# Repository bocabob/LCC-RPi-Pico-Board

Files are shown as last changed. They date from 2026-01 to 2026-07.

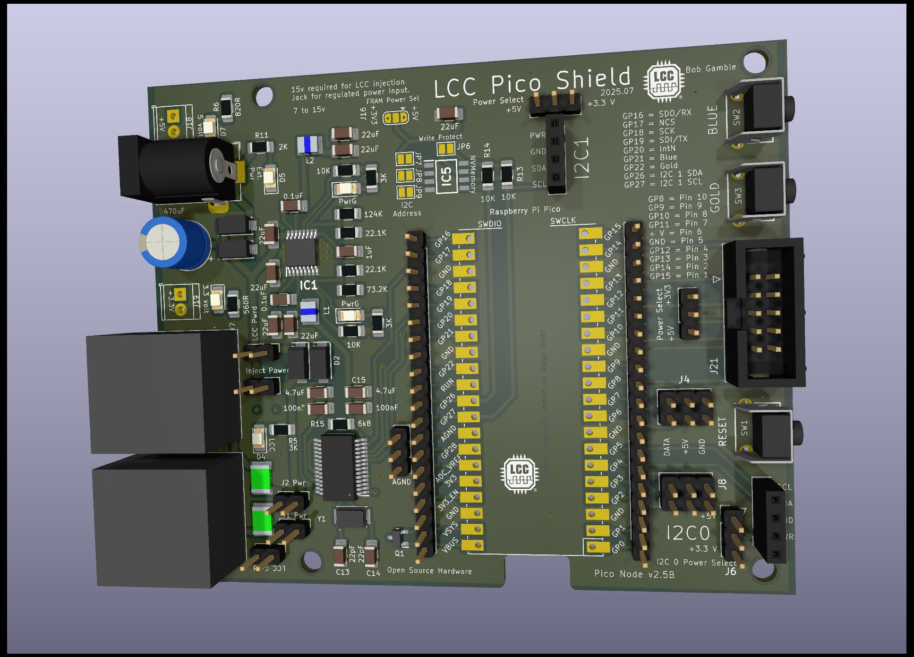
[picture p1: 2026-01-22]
LCC-Pico-Node_v2_6.jpg

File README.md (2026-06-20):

# Raspberry Pi Pico for LCC

KiCad OpenLCB / LCC Raspberry Pi Pico motherboard for model railroad control.

Documentation, source, and gerbers for the board may be found in this repository:
<https://github.com/bocabob/LCC-RPi-Pico-Board>

## Overview

This board provides a flexible Raspberry Pi Pico (or Pico 2) platform for OpenLCB/LCC nodes. It includes:

- 3.3V and 5V switching power regulation
- Provision for onboard or plug-attached EEPROM or FRAM NVM modules
- Configurable to be powered from LCC, powered independently, or to inject power onto the LCC bus
- Tested with the OpenLCB Single Thread and OpenLcbCLib libraries

## Evolution

The LCC Pico development boards evolved from LocoNet designs dating back to 2021. The early turntable boards used Arduino Nanos and depended on turnout commands for indexing to hard-coded stepper positions. Fascia panel input was desired, so a keypad version was developed. This proved cumbersome, so a small touch screen was added with a Mega processor. The screen size needed to grow to nine inches for usability, so the Raspberry Pi Pico was selected. The Pico represents the "Goldilocks" processor of very good function, technical stability, and the easy-to-use Arduino IDE. Moving to the Pico enabled the LCC migration in 2024, when the Single Thread library began to support the RP2040 processor family. With OpenLcbCLib, full protocol support was enabled.

Earlier revisions also included a dedicated **Stepper** board with its own stepper motor driver circuitry built in. As of v3.0, that circuitry has moved to a separate breakout board that plugs into the standard Node board, so there is no longer a need for a Stepper-specific board design — one Node board now serves every node type.

## Family

There is a single board design: the **Node**. It exposes 16 GP pins through two 10P IDC connectors, plus an additional 5-pin analog header (I/O-3), for general-purpose I/O. Specialized functions — stepper motor control, displays, servos, etc. — are added via plug-in breakout boards rather than dedicated board variants.

While the board works with either the Pico or the Pico 2, the Pico 2 is recommended for its enhanced capabilities.

## Common Features

### Power

The board provides dual switching outputs of 3.3V and 5V, with input either from the LCC CAN bus or an external 8–15V source. It may be configured to inject power onto the CAN bus, or to isolate power on either or both of the CAN bus jacks. Auxiliary 3.3V and 5V outputs are available on the board.

### CAN Bus Control

Uses the discrete MCP2518 and MCP2562 CAN controller/transceiver hardware (easier to hand-solder than the integrated MCP251863 used on some earlier boards).

### Non-Volatile Memory (NVM)

I2C non-volatile memory should be used to reduce wear on the Pico flash. External NVM may be attached via the I2C header, the FRAM Breakout header, or soldered down to the IC5 footprint. When using the latter two, the I2C address jumpers may be used to select non-default addresses or implement write protection. Otherwise, those functions are handled by the module plugged into the I2C header.

Typical parts include modules using an AT25C256 chip or RC256V FRAM. Parts compatible with the following pinouts should work for soldering directly to the footprint:

- BR24G512F-3AGTE2 I2C BUS (2-Wire) 512K, or other sizes with equivalent pinouts
- MB85RC256VPF-G-BCERE1 256kbit FRAM with I2C

### I2C

I2C is used to address NVM. One or both of the available I2C channels on the Pico are exposed via headers for external devices. Care should be taken when attaching peripherals to the same channel as the NVM, to avoid interference. Some I2C devices require 5V, so a jumper selects between the two available voltages.

### Buttons

Since the Pico has no reset button, one is provided on the board. There is also a header so a remote reset button may be wired in. Provision is included for blue and gold buttons; on v3.0 these share pins with the I/O-2 and I/O-3 connectors (see pin table below), so they are unavailable when a breakout uses those specific pins.

### IDC Connections

GP pins and other connections are available on 10P IDC connectors (I/O-1, I/O-2), plus a 5-pin analog header (I/O-3). Pinouts are printed on the silkscreen and in the board user guide. On each 10P connector, pin 5 is Ground and pin 6 is a jumper-selectable voltage rail (3.3V or 5V) for the attached breakout.

## Board Variants

### LCC-Pico-Node v3.0

- MCP2518 and MCP2562 chips for CAN bus implementation of OpenLCB/LCC protocols
- Two 10-pin IDC connectors (I/O-1, I/O-2) exposing 16 GP pins for general-purpose I/O
- One 5-pin analog header (I/O-3) for additional GP/analog connections
- Two I2C ports
- Stepper, display, servo, or other specialized functions are added via plug-in breakout boards rather than being built into the Node board itself

### IDC Breakout Boards

- **Display 101 Adapter** — attaches to a BuyDisplay ER-TFTM101 10.1" touchscreen for SPI display control and I2C touch. Includes provision for alternate assignments of line 10 and a reset button.
- **Stepper Breakout** *(planned — design files not yet in this repository)* — carries a stepper motor driver and provides connections to the stepper motor, sensors, NeoPixel bus, and an I2C connection. Has a separate power connection for the external stepper motor supply (12–15V) and for the +5V used for Hall sensors and the NeoPixel bus; the IDC connector voltage should be set to 3.3V on the Node side when this breakout is attached.
- **Ribbon Breakout** — IDC breakout with optional LEDs for testing.
- **Servo Breakout** — IDC breakout with power and ground pins around each GPIO pin to facilitate connections to inputs, servos, NeoPixels, or other devices.

## Board Pin Assignments

| Pin | GP | Alt 1 | Alt 2 | v3.0 Node |
|-----|---|---|---|---|
| 1 | gp0 | SPI0 RX | I2C0 SDA | ACAN_RX_PIN |
| 2 | gp1 | SPI0 CSN  | I2C0 SCL | ACAN_CS_PIN |
| 3 | GND | | | |
| 4 | gp2 | SPI0 SCK  | I2C1 SDA | ACAN_CSK_PIN |
| 5 | gp3 | SPI0 TX | I2C1 SCL | ACAN_TX_PIN |
| 6 | gp4 | SPI0 RX | I2C0 SDA | ACAN_INT_PIN |
| 7 | gp5 | SPI0 CSn  | I2C0 SCL | I/O-2: Pin 10 & Blue Button |
| 8 | GND | | | |
| 9 | gp6 | SPI0 SCK  | I2C1 SDA | I2C1 SDA |
| 10  | gp7 | SPI0 TX | I2C1 SCL | I2C1 SCL |
| 11  | gp8 | SPI1 RX | I2C0 SDA | I/O-1: Pin 1 |
| 12  | gp9 | SPI1 CSn  | I2C0 SCL | I/O-1: Pin 2 |
| 13  | GND | | | |
| 14  | gp10 | SPI1 SCK  | I2C1 SDA | I/O-1: Pin 3 |
| 15  | gp11 | SPI1 TX | I2C1 SCL | I/O-1: Pin 4 |
| 16  | gp12 | SPI1 RX | I2C0 SDA | I/O-1: Pin 7 |
| 17  | gp13 | SPI1 CSn  | I2C0 SCL | I/O-1: Pin 8 |
| 18  | GND | | | |
| 19  | gp14 | SPI1 SCK  | I2C1 SDA | I/O-1: Pin 9 |
| 20  | gp15 | SPI1 TX | I2C1 SCL | I/O-1: Pin 10 |
| 21  | gp16 | SPI0 RX | I2C0 SDA | I/O-2: Pin 1 |
| 22  | gp17 | SPI0 CSn  | I2C0 SCL | I/O-2: Pin 2 |
| 23  | GND | | | |
| 24  | gp18 | SPI0 SCK  | I2C1 SDA | I/O-2: Pin 3 |
| 25  | gp19 | SPI0 TX | I2C1 SCL | I/O-2: Pin 4 |
| 26  | gp20 | | I2C0 SDA | I/O-2: Pin 7 |
| 27  | gp21 | | I2C0 SCL | I/O-2: Pin 8 |
| 28  | GND | | | |
| 29  | gp22 | | | I/O-2: Pin 9 |
| 30  | RUN | | | Reset Button / header |
| 31  | gp26 | ADC0 | I2C1 SDA | I/O-3: Pin 1 |
| 32  | gp27 | ADC1 | I2C1 SCL | I/O-3: Pin 2 |
| 33  | GND | A GND | | I/O-3: Pin 3 (AGND) |
| 34  | gp28 | ADC2 | | I/O-3: Pin 5 & Gold Button |
| 35  | | ADC_VREF  | | I/O-3: Pin 4 (VREF) |
| 36  | 3v3_OUT  | | | |
| 37  | 3V3_EN | | | |
| 38  | GND | | | |
| 39  | VSYS | | | |
| 40  | VBUS | | | |
| | GND | | | I/O-1: Pin 5 |
| | Vselect1 | | | I/O-1: Pin 6 |
| | GND | | | I/O-2: Pin 5 |
| | Vselect2 | | | I/O-2: Pin 6 |

Note: I/O-2 Pin 10 (gp5) and I/O-3 Pin 5 (gp28) double as the Blue and Gold buttons. A breakout that uses either of those pins makes the corresponding button unavailable.

## Software

### Example Node Applications

- <https://github.com/bocabob/LCC_RPiPico_Turntable>
- <https://github.com/bocabob/LCC_RPiPico_Roundhouse>
- <https://github.com/bocabob/LCC_RPiPico_PixelLights>
- <https://github.com/bocabob/LCC_RPiPico_Clock_Lights>

### Architectural Standard

Cross-project firmware conventions (board versioning, breakout pin assignments, configuration memory, naming) for all node applications above are documented in:
<https://github.com/bocabob/LCC_RPiPico_Common>

### Board Support

Use the RP2040 board library by Earle Philhower:
<https://arduino-pico.readthedocs.io/en/latest/install.html>

### LCC Support

- <https://github.com/openlcb/OpenLCB_Single_Thread>
- <https://github.com/JimKueneman/OpenLcbCLib>

### CAN Hardware

- ACAN2517 Arduino library

### External Storage

- I2C_EEPROM Arduino library by Rob Tillaart
- FRAM_I2C Arduino library by Rob Tillaart

### NeoPixel

- NeoPixelBus by Makuna (preferred)
- NeoPixelConnect by Alan Yorinks

### Other Preferred Libraries

#### Display

- `TFT_eSPI_RA8876.h` — display library (modified): <https://github.com/bocabob/TFT_eSPI_RA8876>
- `RA8876_RP2040.h` — display library (modified): <https://github.com/bocabob/RA8876_RP2040>
- `my_bb_captouch.h` — capacitive touch driver (modified): <https://github.com/bocabob/my_bb_captouch>

#### Servos

- `ServoEasing.hpp` — for slow servo action, including bounces
- `PCA9685_servo_driver.h`
- `PCA9685_servo.h`

#### Stepper Motor

- `AccelStepper.h` by Mike McCauley (modified)

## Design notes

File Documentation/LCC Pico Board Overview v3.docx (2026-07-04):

# LCC Pico Board Overview

Documentation, source and gerbers for boards may be found at: https://github.com/bocabob/LCC-RPi-Pico-Board

## Overview

This board provides a flexible Raspberry Pi Pico (or Pico 2) platform for OpenLCB/LCC nodes. It includes:

- 3.3V and 5V switching power regulation
- Provision for onboard or plug-attached EEPROM or FRAM NVM modules
- Configurable to be powered from LCC, powered independently, or to inject power onto the LCC bus
- Tested with the OpenLCB Single Thread and OpenLcbCLib libraries

## Evolution

The LCC Pico development boards evolved from LocoNet designs dating back to 2021. The early turntable boards used Arduino Nanos and depended on turnout commands for indexing to hard-coded stepper positions. Fascia panel input was desired, so a keypad version was developed. This proved cumbersome, so a small touch screen was added with a Mega processor. The screen size needed to grow to nine inches for usability, so the Raspberry Pi Pico was selected. The Pico represents the "Goldilocks" processor of very good function, technical stability, and the easy-to-use Arduino IDE. Moving to the Pico enabled the LCC migration in 2024, when the Single Thread library began to support the RP2040 processor family. With OpenLcbCLib, full protocol support was enabled.

Earlier revisions also included a dedicated Stepper board with its own stepper motor driver circuitry built in. As of v3.0, that circuitry has moved to a separate breakout board that plugs into the standard Node board, so there is no longer a need for a Stepper-specific board design — one Node board now serves every node type.

## Families

There is a single board architecture: the Node. It exposes 16 GP pins through two 10P IDC connectors, plus an additional 6-pin analog header (I/O-3), for general-purpose I/O. Specialized functions — stepper motor control, displays, servos, etc. — are added via plug-in breakout boards rather than dedicated board variants.

## A variant of the Node is the Lite Node which is slightly smaller and lacks external power inputs and the 3.3-volt power circuitry. 3.3-volt power is supplied by the RPi Pico and is thus limited by that specification and should not exceed about 250mA.

## While the boards work with either the Pico or the Pico 2, the Pico 2 is recommended for its enhanced capabilities.

## Common Features

#### Power

The full board provides dual switching power output of 3.3V and 5V with input either from the LCC CAN bus or an external power source between 8 and 15 volts. The boards may be configured to inject power to the CAN bus or to isolate power for either or both of the CAN bus jacks. Auxiliary power outputs for both 3.3V and 5V are available on the board.

#### CAN Bus Control

#### Uses the discrete MCP2518 and MCP2562 CAN controller/transceiver hardware (easier to hand-solder than the integrated MCP251863 used on some earlier boards).

#### Non-Volatile Memory (NVM)

I2C nonvolatile memory is used to reduce strain on the Pico flash. External NVM is soldered down to the IC5 footprint. The I2C Address jumpers may be used to select non-default addresses or implement write protection. Otherwise, these would be functions of the module plugged into the I2C header.

Parts compatible with the following should work for soldering to the footprint on the board.

- BR24G256F-3AGTE2 I2C BUS(2-Wre) 256K or other sizes with equivalent pinouts
- MB85RC256VPF-G-BCERE1 256kbit FRAM with I2C

#### I2C

One of the two available I2C channels is dedicated to address NVM. The other available I2C channel on the Pico may be configured from appropriate pins on the IDC connections. Care should be taken should you attach peripherals to the same channel as the NVM lest there be interference. Some I2C devices will require 5 volts and so there is selection via jumper between the two available voltages but 3.3-volts is preferred as this matches the Pico voltage.

#### Buttons

As there is no reset button on the Pico, one is provided on the board. There is also a header so that a button may be wired in for remote reset. Provision is included for blue and gold buttons; on v3.0 these share pins with the I/O-2 and I/O-3 connectors (see pin table below), so they are unavailable when a breakout uses those specific pins.

#### IDC Connections

GP pins and other connections are available on 10P IDC connectors (I/O-1, I/O-2), plus a 5-pin analog header (I/O-3). Pinouts are printed on the silkscreen and in the board user guide. On each 10P connector, pin 5 is Ground and pin 6 is a jumper-selectable voltage rail (3.3V or 5V) for the attached breakout.

# Board Variants

There are versions with 1206 size components for hand assembly and versions with 0805 sized components for economic production by JLCPCB. All files for assembly input are provided.

## LCC-Pico-Node v3.0

- MCP2518 and MCP2562 chips for CAN bus implementation of OpenLCB/LCC protocols
- Two 10-pin IDC connectors (I/O-1, I/O-2) exposing 16 GP pins for general-purpose I/O
- One 6-pin IDC analog header (I/O-3) for additional GP/analog connections
- External power connections for input and/or output to peripheral devices. 5- and 3.3-volt regulation is on board and available from supplied input. Current should not exceed 1 A from each regulated source. External input power is passed through to associated headers.
- Stepper, display, servo, or other specialized functions are added via plug-in breakout boards rather than being built into the Node board itself

## LCC-Pico-Node-Lite v3.0

- MCP2518 and MCP2562 chips for CAN bus implementation of OpenLCB/LCC protocols
- Two 10-pin IDC connectors (I/O-1, I/O-2) exposing 16 GP pins for general-purpose I/O
- One 6-pin IDC analog header (I/O-3) for additional GP/analog connections
- LCC bus powered, 5 volt regulated supply, 3.3 volt from Pico (limited capacity)
- Display, servo, or other specialized functions are added via plug-in breakout boards rather than being built into the Node board itself. Current demand should not exceed LCC specifications.

### Board Pin Assignments

Pin | GP | Alt 1 | Alt 2 | v3.0 Node
1 | gp0 | SPI0 RX | I2C0 SDA | ACAN_RX_PIN
2 | gp1 | SPI0 CSN | I2C0 SCL | ACAN_CS_PIN
3 | GND
4 | gp2 | SPI0 SCK | I2C1 SDA | ACAN_CSK_PIN
5 | gp3 | SPI0 TX | I2C1 SCL | ACAN_TX_PIN
6 | gp4 | SPI0 RX | I2C0 SDA | ACAN_INT_PIN
7 | gp5 | SPI0 CSn | I2C0 SCL | I/O-2: Pin 10 & Blue Button
8 | GND
9 | gp6 | SPI0 SCK | I2C1 SDA | I2C1 SDA
10 | gp7 | SPI0 TX | I2C1 SCL | I2C1 SCL
11 | gp8 | SPI1 RX | I2C0 SDA | I/O-1: Pin 1
12 | gp9 | SPI1 CSn | I2C0 SCL | I/O-1: Pin 2
13 | GND
14 | gp10 | SPI1 SCK | I2C1 SDA | I/O-1: Pin 3
15 | gp11 | SPI1 TX | I2C1 SCL | I/O-1: Pin 4
16 | gp12 | SPI1 RX | I2C0 SDA | I/O-1: Pin 7
17 | gp13 | SPI1 CSn | I2C0 SCL | I/O-1: Pin 8
18 | GND
19 | gp14 | SPI1 SCK | I2C1 SDA | I/O-1: Pin 9
20 | gp15 | SPI1 TX | I2C1 SCL | I/O-1: Pin 10
21 | gp16 | SPI0 RX | I2C0 SDA | I/O-2: Pin 1
22 | gp17 | SPI0 CSn | I2C0 SCL | I/O-2: Pin 2
23 | GND
24 | gp18 | SPI0 SCK | I2C1 SDA | I/O-2: Pin 3
25 | gp19 | SPI0 TX | I2C1 SCL | I/O-2: Pin 4
26 | gp20 | | I2C0 SDA | I/O-2: Pin 7
27 | gp21 | | I2C0 SCL | I/O-2: Pin 8
28 | GND
29 | gp22 | | | I/O-2: Pin 9
30 | RUN | | | Reset Button / header
31 | gp26 | ADC0 | I2C1 SDA | I/O-3: Pin 1
32 | gp27 | ADC1 | I2C1 SCL | I/O-3: Pin 2
33 | GND | A GND | | I/O-3: Pin 3 (AGND)
34 | gp28 | ADC2 | | I/O-3: Pin 5 & Gold Button
35 | | ADC_VREF | | I/O-3: Pin 4 (VREF)
36 | 3v3_OUT
37 | 3V3_EN
38 | GND
39 | VSYS
40 | VBUS
| GND | | | I/O-1: Pin 5
| Vselect1 | | | I/O-1: Pin 6
| GND | | | I/O-2: Pin 5
| Vselect2 | | | I/O-2: Pin 6

Note: I/O-2 Pin 10 (gp5) and I/O-3 Pin 5 (gp28) double as the Blue and Gold buttons. A breakout that uses either of those pins makes the corresponding button unavailable.

### Node 3.0C

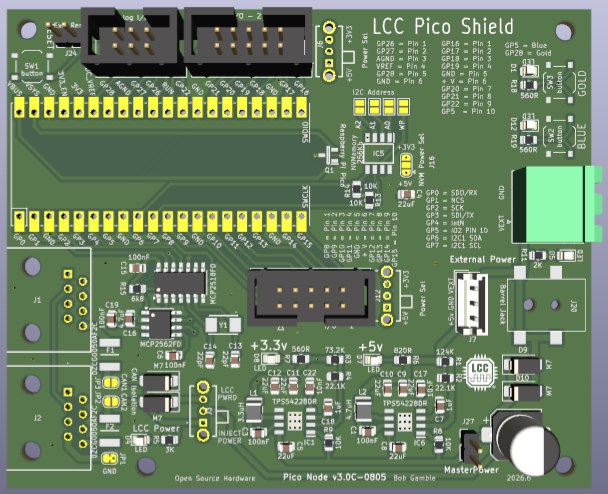
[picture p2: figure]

The power circuit uses two separate switching chips which are identical in function and rated for about 1 amp each.

There is a switch to toggle between injecting power to LCC or to be powered from LCC. Each 10 pin IDC connector is associated with a switch to select the voltage (3.3 or 5) passed on the power pin (6) of the connection. There is a solder jumper to select the voltage used for the NVM chip should there be a specific need.

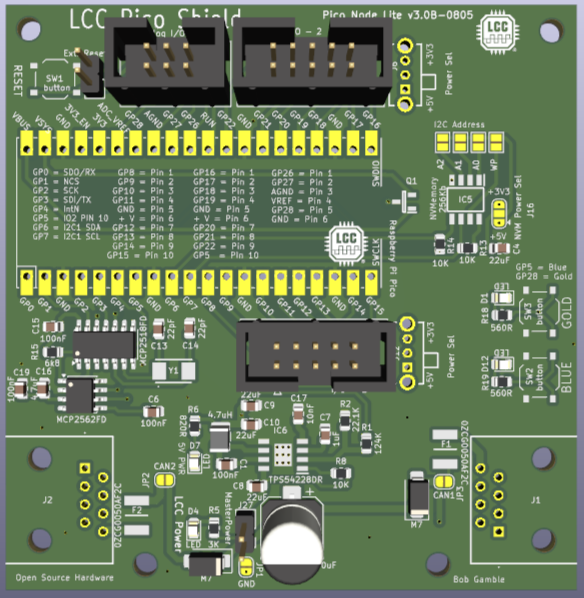
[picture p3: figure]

### Node Lite 3.0B

There is no provision for external power input. The node draws power from the LCC bus.

This board is built using just a single 5-volt supply and using the Pico 3.3V output pin to power the 3.3V for CAN and NVM circuits. Draw should not exceed 200-250mA.

Other than that, it has essentially the same functionality as Node 3.0C.

# IDC Breakout Boards

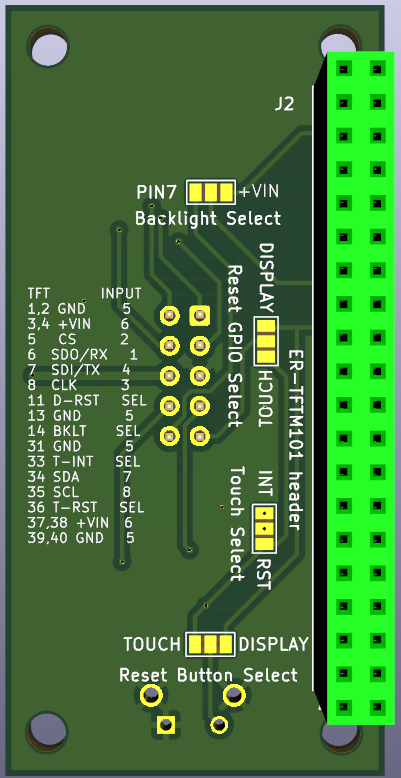
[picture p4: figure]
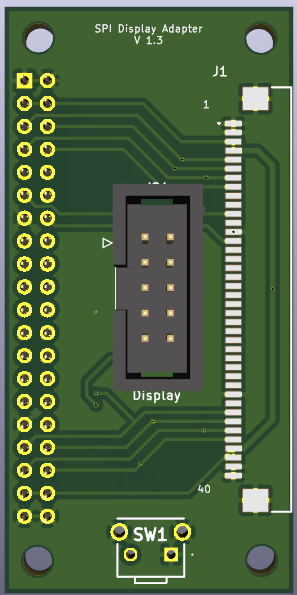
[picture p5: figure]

Display 101 Adapter — attaches to a BuyDisplay ER-TFTM101 10.1" touchscreen for SPI display control and I2C touch. Includes provision for alternate assignments of line 10 and a reset button.

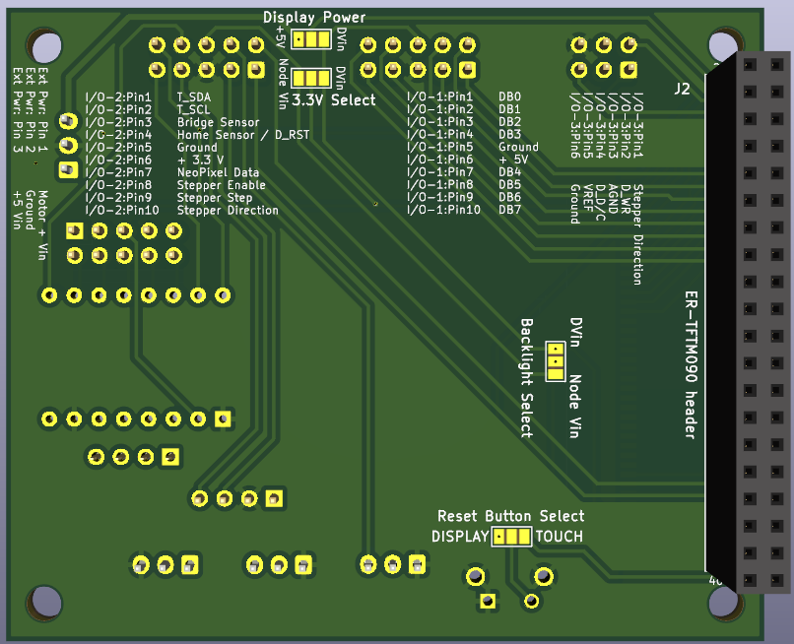
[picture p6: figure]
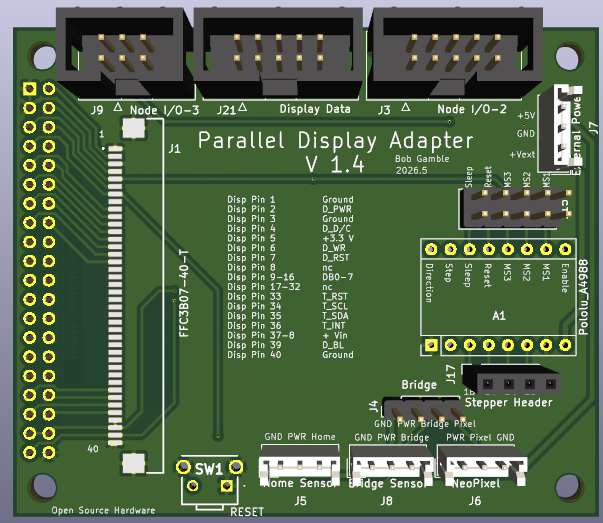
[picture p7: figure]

Display 090 Adapter — attaches to a BuyDisplay ER-TFTM090 9.0" touchscreen for parallel display control and I2C touch. Includes provision for alternate assignments of line 10 and a reset button.

Display 070 Adapter — attaches to a BuyDisplay ER-TFTM070 7.0" touchscreen for SPI display and touch control. Includes provision for alternate assignments of line 10 and a reset button.

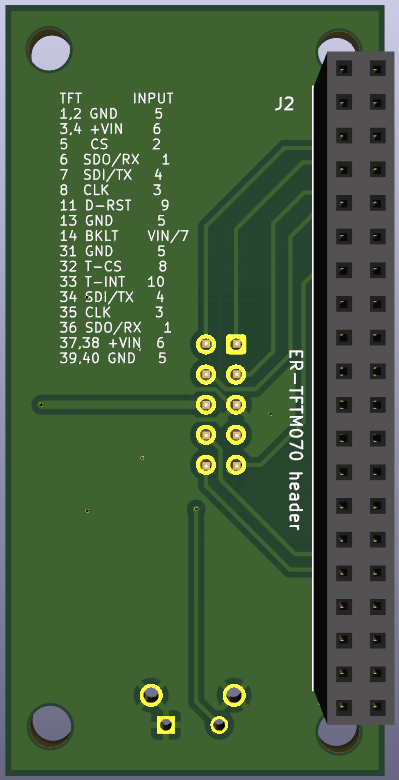
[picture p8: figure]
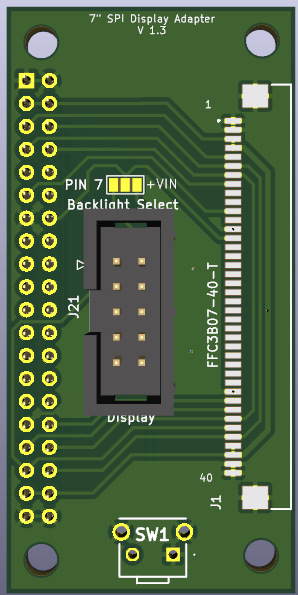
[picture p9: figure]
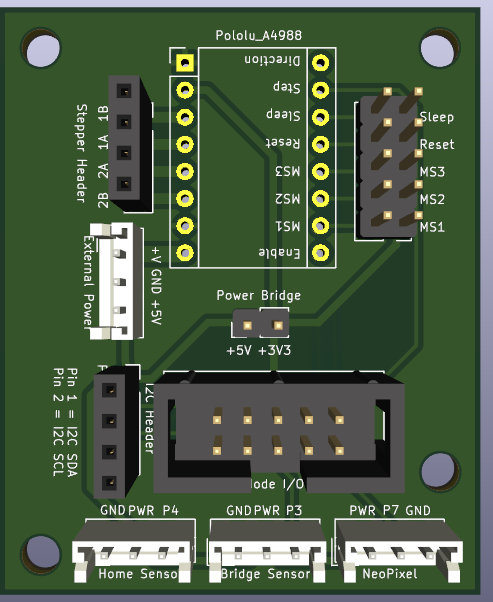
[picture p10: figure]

Stepper Breakout — carries a stepper motor driver and provides connections to the stepper motor, sensors, NeoPixel bus, and an I2C connection. Has a separate power connection for the external stepper motor supply (12–15V) and for the +5V used for Hall sensors and the NeoPixel bus; the IDC connector voltage should be set to 3.3V on the Node side when this breakout is attached.

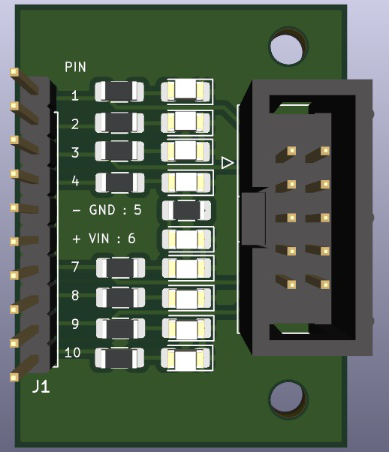
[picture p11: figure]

Ribbon Breakout — IDC breakout with optional LEDs for testing.

Servo Breakout — IDC breakout with power and ground pins around each GPIO pin to facilitate connections to inputs, servos, NeoPixels, or other devices.

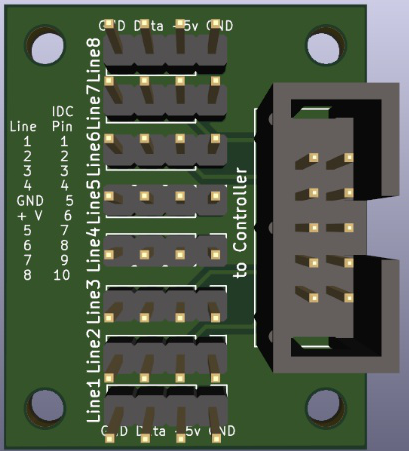
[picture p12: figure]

# Software

## Example Node Applications

- https://github.com/bocabob/LCC_RPiPico_Turntable
- https://github.com/bocabob/LCC_RPiPico_Roundhouse
- https://github.com/bocabob/LCC_RPiPico_PixelLights
- https://github.com/bocabob/LCC_RPiPico_Clock_Lights

## Architectural Standard

Cross-project firmware conventions (board versioning, breakout pin assignments, configuration memory, naming) for all node applications above are documented in: https://github.com/bocabob/LCC_RPiPico_Common

## Board Support

Use the RP2040 board library by Earle Philhower: https://arduino-pico.readthedocs.io/en/latest/install.html

## LCC Support

- https://github.com/openlcb/OpenLCB_Single_Thread
- https://github.com/JimKueneman/OpenLcbCLib

## CAN Hardware

- ACAN2517 Arduino library

## External Storage

- I2C_EEPROM Arduino library by Rob Tillaart
- FRAM_I2C Arduino library by Rob Tillaart

## NeoPixel

- NeoPixelBus by Makuna (preferred)
- NeoPixelConnect by Alan Yorinks

### Other Preferred Libraries

#### Display

- TFT_eSPI_RA8876.h — display library (modified): https://github.com/bocabob/TFT_eSPI_RA8876
- RA8876_RP2040.h — display library (modified): https://github.com/bocabob/RA8876_RP2040
- my_bb_captouch.h — capacitive touch driver (modified): https://github.com/bocabob/my_bb_captouch

#### Servos

- ServoEasing.hpp — for slow servo action, including bounces
- PCA9685_servo_driver.h
- PCA9685_servo.h

#### Stepper Motor

- AccelStepper.h by Mike McCauley (modified)

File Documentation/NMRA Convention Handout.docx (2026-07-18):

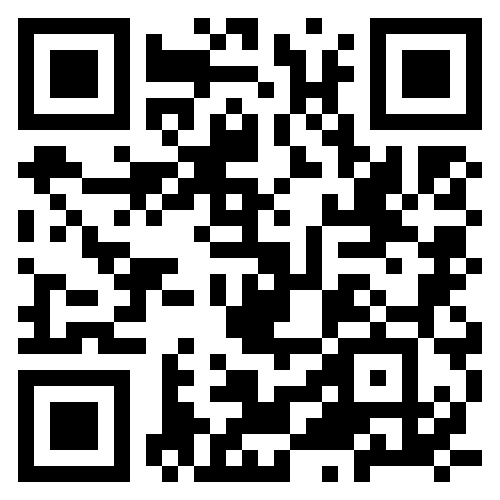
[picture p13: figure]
QR Code Image

LCC RPiPico Node (v3.0)

An open, DIY-friendly Raspberry Pi Pico platform for OpenLCB / LCC model railroad control

Bob Gamble · bocabobgamble@gmail.com · github.com/bocabob

The LCC RPiPico Node is a single, general-purpose board design that replaces a whole family of earlier dedicated boards. Specialized functions — displays, stepper drivers, servos, and more — plug in as breakout boards rather than requiring a new board revision for every node type. It grew out of LocoNet turntable controllers dating back to 2021 and migrated to full LCC/OpenLCB support in 2024.

## WHY IT’S AN EASY DIY ENTRY POINT

- Arduino IDE — programmed with the standard Earle Philhower RP2040 board package.
- Full LCC/OpenLCB stack included via the OpenLcbCLib library — alias allocation, datagrams, CDI, memory config, and more already implemented.
- One board, every node type — swap breakout boards instead of re-designing hardware for each new function.
- Hand-solderable — discrete MCP2518/MCP2562 CAN chips instead of hard-to-hand-solder integrated parts.
- Documented pin/architecture standard shared across every example project, so patterns learned on one node transfer directly to the next.
- Working example firmware to copy — four complete, real-world node applications with full source (see below).

## KEY BOARD ATTRIBUTES

- Processor: Raspberry Pi Pico or Pico 2 (Pico 2 recommended)
- CAN: discrete MCP2518 controller + MCP2562 transceiver
- Power: dual 3.3V/5V switching regulation; power from LCC bus or 8–15V external; can inject power onto the bus
- NVM: onboard I2C EEPROM or FRAM spares the Pico’s flash from wear
- I/O: 16 GP pins via two 10-pin IDC connectors (I/O-1, I/O-2) + a 6-pin analog header (I/O-3)
- Breakout ecosystem: touchscreen displays (SPI or parallel), stepper driver, servo, and test/ribbon breakouts
- Buttons: onboard reset (Pico has none) + header for a remote reset button; Blue/Gold (shared pins)

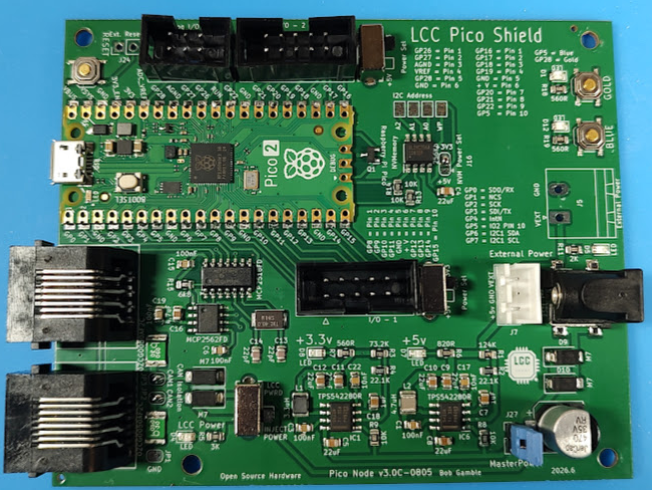
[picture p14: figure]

EXAMPLE NODE PROJECTS (OPEN SOURCE, FULL FIRMWARE ON GITHUB)

- Turntable — Motorized turntable controller — stepper-driven positioning, home/limit sensing, touchscreen UI with track selection, bridge animation, and RailCom occupancy display.
- Roundhouse — Multi-stall roundhouse door control — servo-driven doors synchronized to turntable track selection.
- PixelLights — Addressable NeoPixel lighting controller — scene/effect control for structure, signal, or ambient layout lighting over LCC events.
- Clock Lights — Layout lighting tied to the LCC fast clock — day/night lighting transitions and dimming driven by the shared broadcast fast-clock protocol.

GET STARTED

- Board hardware (documentation, schematics, PCB, gerbers, breakout designs): github.com/bocabob/LCC-RPi-Pico-Board
- Firmware architecture standard & example application links: github.com/bocabob/LCC_RPiPico_Common
- Board support: Earle Philhower’s RP2040 core (arduino-pico) — install instructions at arduino-pico.readthedocs.io/en/latest/install.html
- LCC protocol stack: OpenLcbCLib at github.com/JimKueneman/OpenLcbCLib or OpenLCB Single Thread at github.com/openlcb/OpenLCB_Single_Thread

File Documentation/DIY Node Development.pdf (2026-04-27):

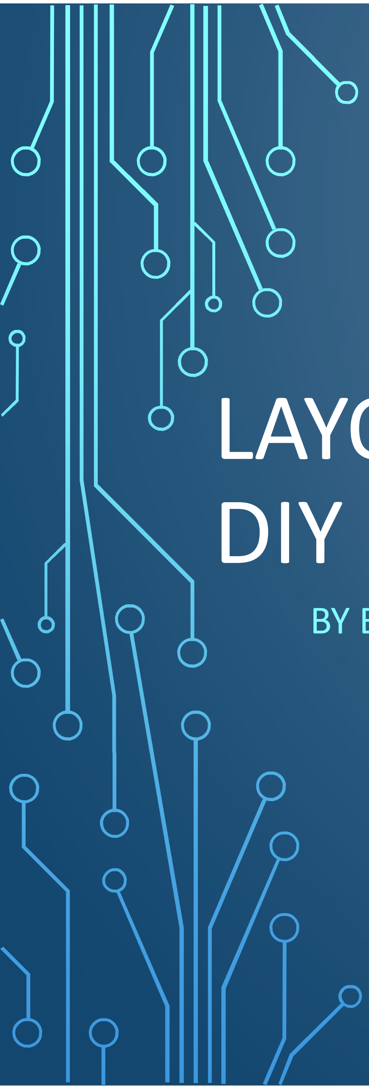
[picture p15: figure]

# LAYOUT COMMAND CONTROL

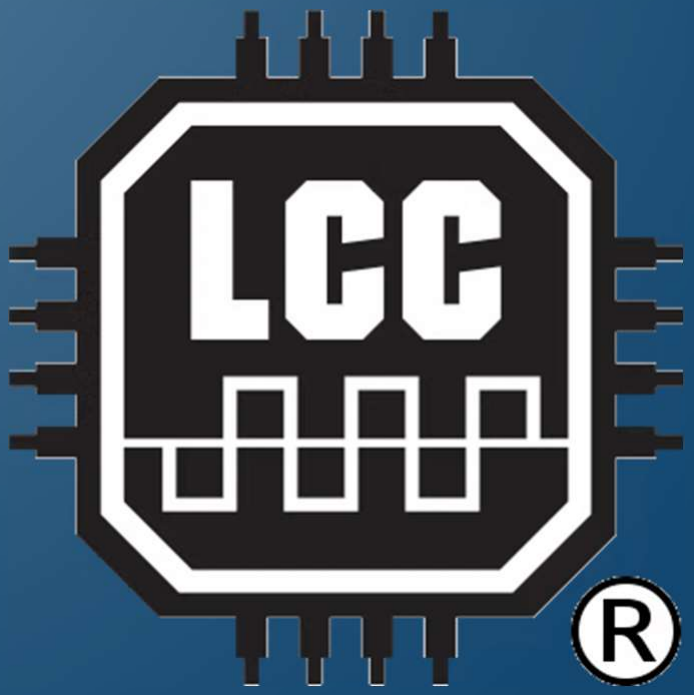
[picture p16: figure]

# DIY NODE DEVELOPMENT

BY BOB GAMBLE, MMR® #800

AGENDA • Disclaimer • LCC Background • Objectives • Resources • Hardware • Software Library • Software Application • My Experience • Recommendations

## DISCLAIMER

- By training I am a Mechanical Engineer, not Electrical or Programming. I did have a career in computer and software development, so I did pick up a few things along the way. Osmosis can be wonderful.
- Self-taught in programming though I have had a course or two in college and professionally.
- I muddle through on circuit design and as Ringo said “With a little help from my friends.”

## LCC BACKGROUND

- Had produced a number of LocoNet nodes using Arduino Nanos and Megas but wanted to upgrade to LCC. Bought a starter kit in 2020.
- I started deploying LCC on my layout in 2021 with Tortoise controls using RRCirKits products. Worked with Dick Bronson to use sampling mode on I/O lines and wrote an article in the NMRA magazine (Jan 2023) on the topic.
- Investigated an ESP32 based LCC development board by Mike Dunston but decided the development environment was too complex for me.
- Deployed block occupancy (2022) and signaling (2023)
- Started using Raspberry Pi Pico and decided to start on the LCC DIY path in 2024.
- Layout has 10 LCC nodes: 7 Towers w/9 SMD-8 & 5 BOD-8, 2 Signal 32H, 1 DIY Pico for lighting
One LocoNet node for Turntable & Roundhouse control to be replaced with DIY LCC

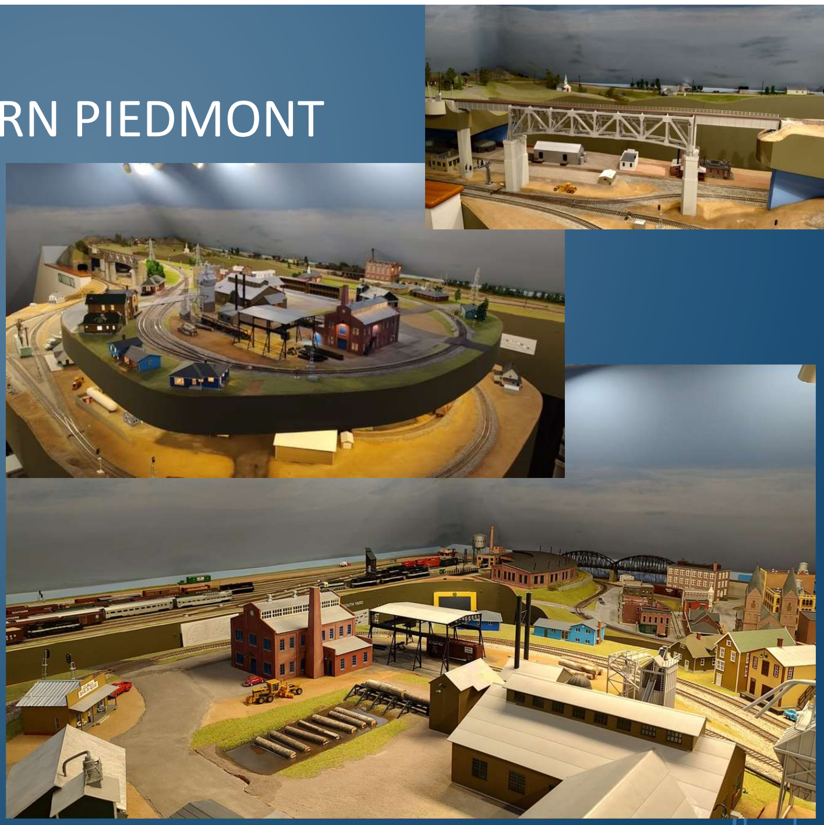
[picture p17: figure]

## MY LAYOUT – SOUTHERN PIEDMONT

- RR Prototype — Southern Railway
- Scale — HO
- Era – Early 1960s, Diesel • Scenery complete – 90%
- Configuration — Overlapping folded dog bone
- Layout Size — 25 by 19 ft • Location in Home —Third floor attic
- Approximate Square Feet – 450 plus
- DCC System — Digikeijs/YAMORC
w/ WiThrottle or Engine Driver • Operation — Fictional branches of the

Southern, with main yard, interchanges, local industries. • Ops-Method – JMRI manifests/switch lists

- Dispatching – JMRI Dispatcher Panel. • Max Operators – 5, yardmasters & road

crews

## OBJECTIVES

- Ease of maintenance using the LCC Configuration tools in JMRI
- Cross-node communication (events)
- Familiar development environment (Arduino IDE)
- Goal: to replace my DIY LocoNet turntable & roundhouse controller with one based on LCC.

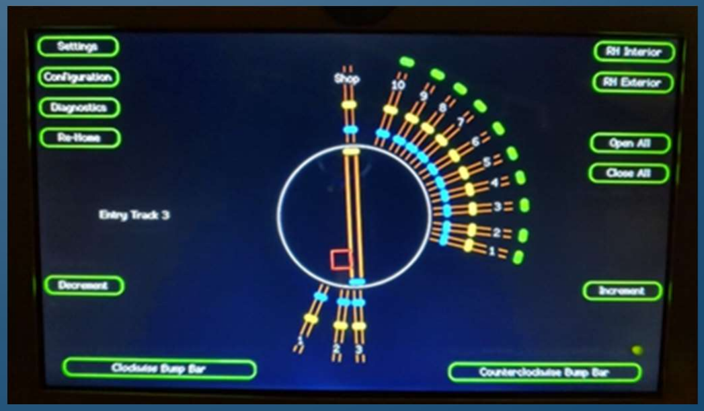
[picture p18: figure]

## RESOURCES

- Friends Mike Dunston and David Harris provided advice and guidance on hardware and software.
- LCC community groups for questions and answers both mine and from others.
- Github for example software.
- Videos, blogs, and books.

## HARDWARE

- I spent a lot of time reading component datasheets on Mouser and searching for example reference designs and schematics.
- The LCC Pico node was designed with the help of my friends. Thanks Ringo.
- Designed in KiCad with PCB from China
- Dual power regulator provides 3.3v and 5v from either LCC cable or external source. If powered externally the node may be configured to inject power to the LCC cable.
- CAN transceiver and NVM support as the RPi Pico lacks these features

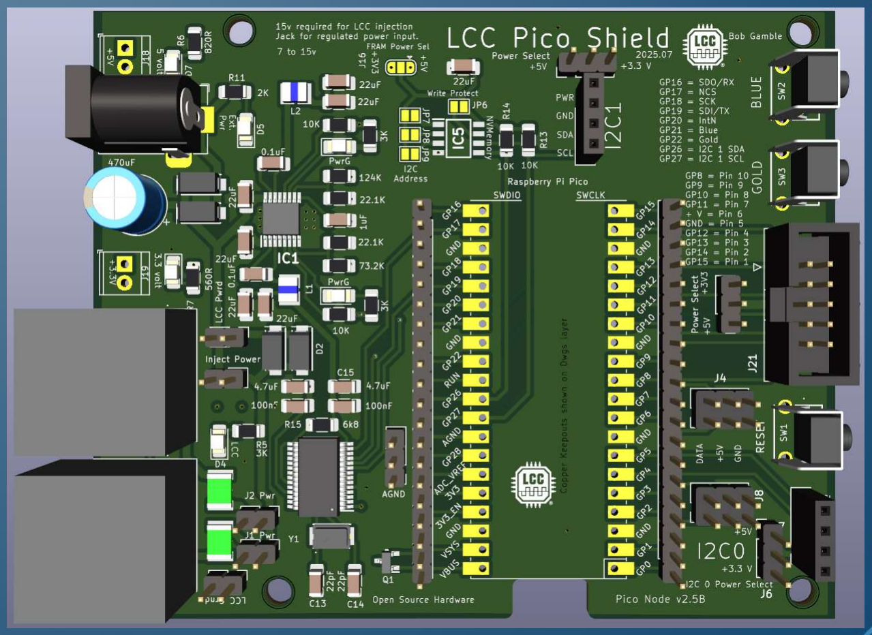
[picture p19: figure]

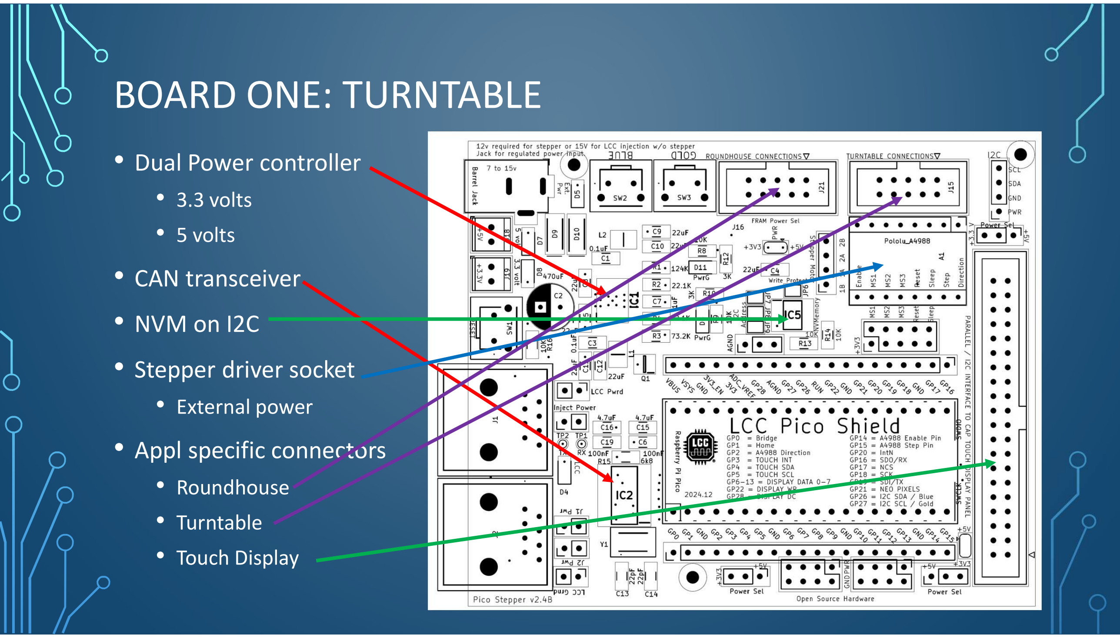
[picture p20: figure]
BOARD ONE: TURNTABLE; • Dual Power controller • 3.3 volts • 5 volts • CAN transceiver • NVM on I2C • Stepper driver socket • External power • Appl specific connectors • Roundhouse • Turntable • Touch Display

## BOARD TWO: SIMPLIFIED DEVELOPMENT

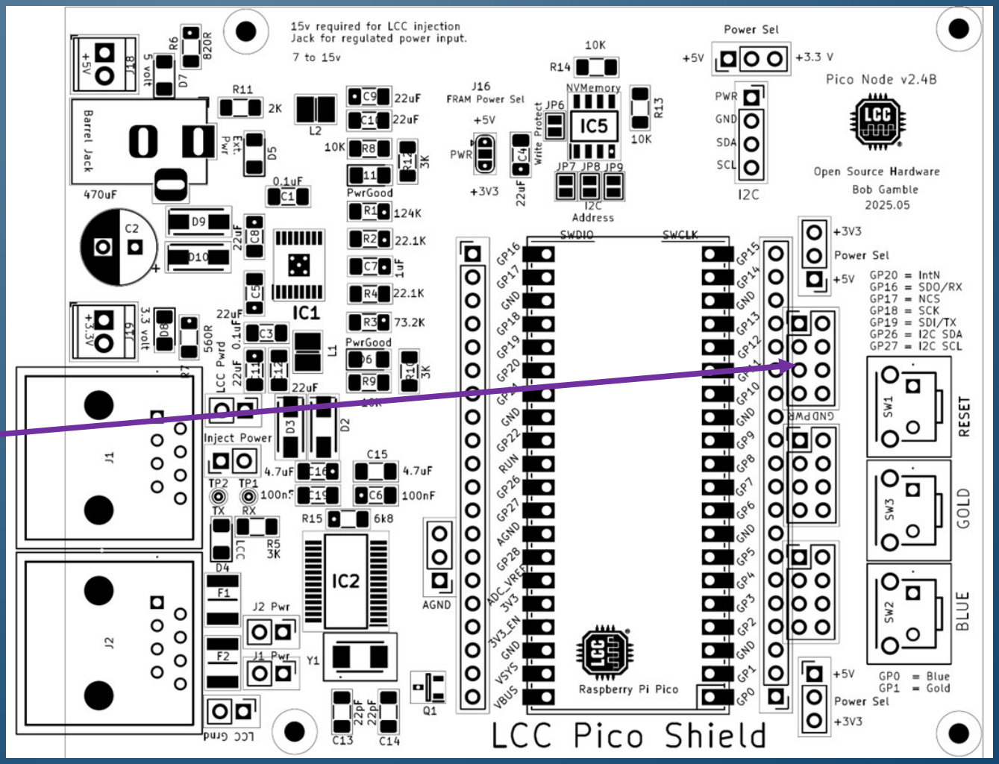
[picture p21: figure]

- Dual Power controller
- 3.3 volts
- 5 volts
- CAN transceiver
- NVM on I2C
- Pico pin access

## BOARD THREE: GENERAL USAGE

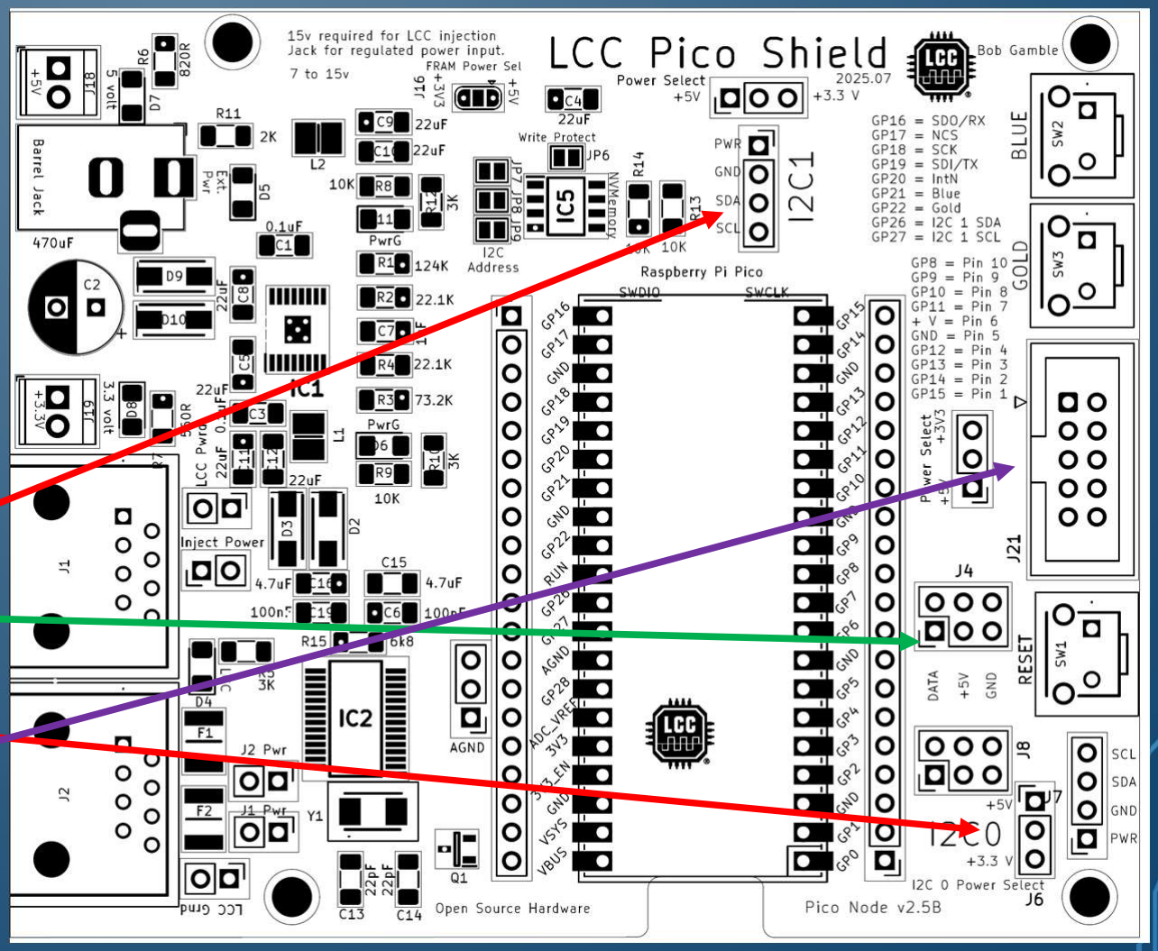
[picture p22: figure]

- Dual Power controller
- 3.3 volts
- 5 volts
- CAN transceiver
- NVM on I2C
- Appl specific connectors
- NeoPixel (4)
- I2C (2)
- 10 Pin IDC (8 GPIO pins)

## SOFTWARE LIBRARY

- Using the OpenLCB_Single_Thread library maintained by David Harris
- Supported by the Arduino IDE
- Raspberry Pi Pico Arduino core, Arduino-Pico, by Earle Philhower, III.
- Various other libraries for specific functions
- NeoPixel lights
- Non-Volatile Memory
- Servos
- Stepper Motors
- Displays

## SOFTWARE APPLICATION

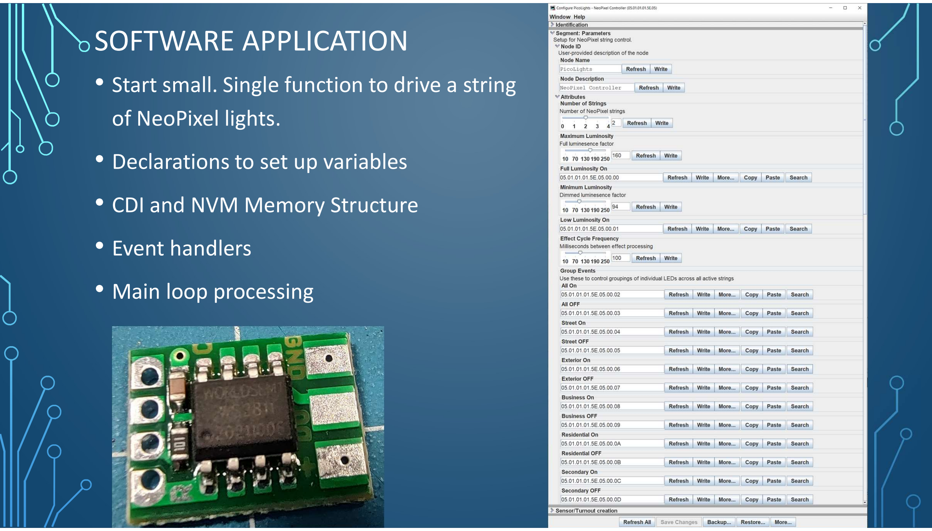
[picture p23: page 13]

- Start small. Single function to drive a string of NeoPixel lights.
- Declarations to set up variables
- CDI and NVM Memory Structure
- Event handlers
- Main loop processing

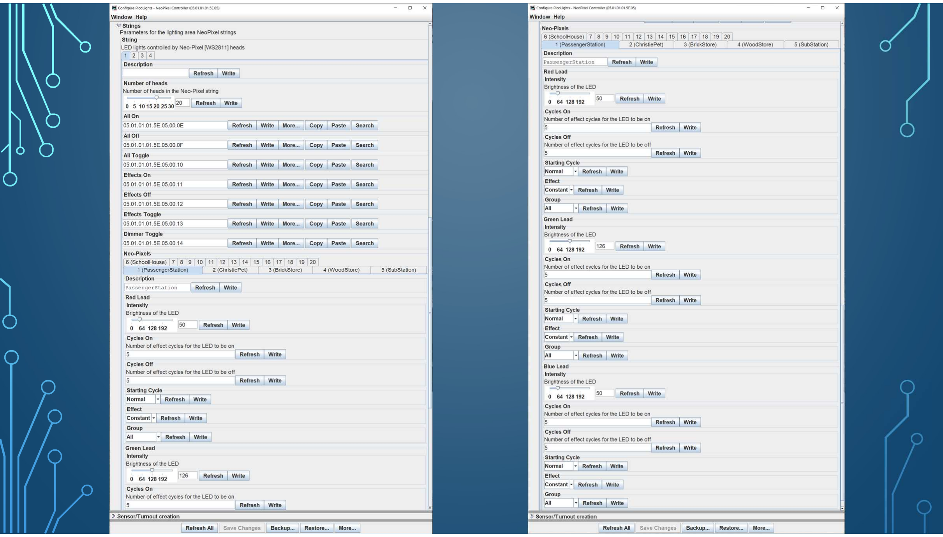
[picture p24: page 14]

## MY EXPERIENCE

- Get a working hardware base
- Start with an example and learn to manipulate the CDI
- Once you have the CDI, work on function and event handling
- Set up a bench test with JMRI LCCPro to iterate and test

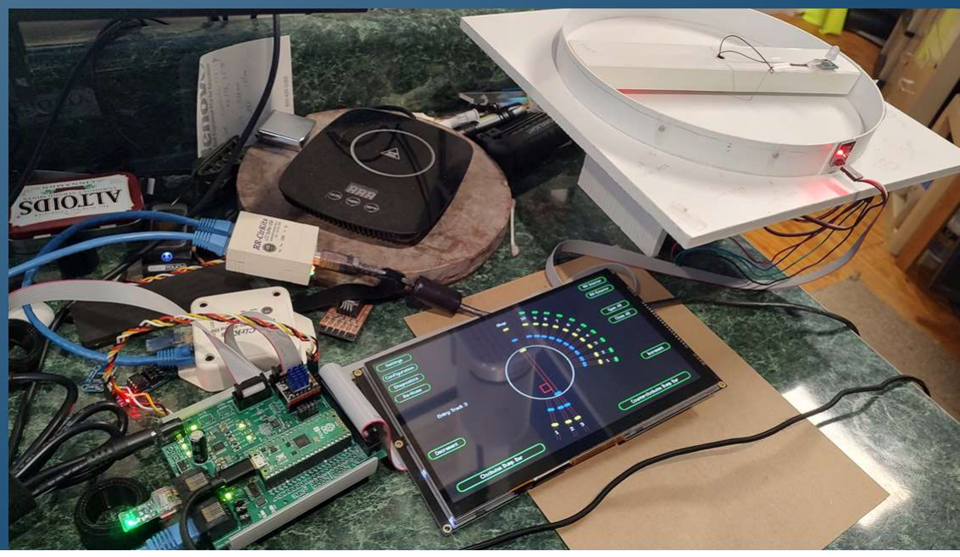
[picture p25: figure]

## FUTURE ADDITIONS


- Developing my own Raspberry Pi Pico LCC node to control my turntable. Will use a separate node to control the roundhouse doors and lights.
- Migrate layout accessory lighting to LCC control so that I can tie to a fastclock for operations.
- Add more block detection on industrial spurs.
- Add grade crossings.
- May change command station and boosters to ones with integrated LCC.
- May change reversing loop control to one that is short-free.

## RECOMMENDATIONS

- Understand the end game
decide where you want to be when complete
- LCC is a great solution for turnout control, detection, and signaling. It can be extended to other peripheral uses.
- If you are unhappy with what you have or want LCC
- Get an LCC starter set
- Read book, manuals, blogs, sites, and watch some videos
- Set it up on your workbench and get familiar with how to make it do what you want
- Deploy to the layout

## INFORMATION

- Developer User Group:

https://groups.io/g/openlcb
- LCC User Group:

https://groups.io/g/layoutcommandcontrol
To Join: openlcb+subscribe@groups.iolayoutcommandcontrol+subscribe@groups.io
- Useful Links:

http://openlcb.org or http://openlcb.com
https://www.nmra.org/lcc


## GETTING UP TO SPEED ON LCC

- Read “Layout Command Control 2025” by Dana Zimmerli. Some of this book is more detailed and technical than a user needs to know for implementation but familiarity of these concepts could be helpful and it won’t hurt (much) to learn it. • Join the openlcb@groups.io mailing list, which emphasizes LCC development efforts and

layoutcommandcontrol@groups.io, which is more user-oriented. • Look at some of the LCC tutorials found on the Great Northwestern Railway website and video

https://www.youtube.com/watch?v=Au4lcuyfx4g
- Introduction to LCC by Robin Peel: https://www.youtube.com/watch?v=jjaNdu0cgaE
- NMRAx clinic “LCC A Better Way to Switch Points” https://www.youtube.com/watch?v=ZsnLhOQSNzs. • Search for the latest tutorials and videos. • Look at The OpenLCB Group – Layout Command Control (LCC). • Decide what you want to do / accomplish with LCC. • Buy the LCC Starter Kit from RR-CirKits, Inc. , SPROG, or others and perhaps a node or two that align with your goals. Read

the manual(s) http://www.rr-cirkits.com/manuals/
- Install jmri A Java Model Railroad Interface if you haven’t already and join jmriusers@groups.io. • The various groups.io message boards are great sources of support.

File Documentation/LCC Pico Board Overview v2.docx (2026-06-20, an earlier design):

# LCC Pico Board Overview

Documentation, source and gerbers for boards may be found at: https://github.com/bocabob/LCC-RPi-Pico-Board

## Evolution

The LCC Pico development boards evolved from LocoNet designs dating back to 2021. These early turntable boards used Arduino Nanos and depended on turnout commands for indexing to hard-coded stepper positions. Fascia panel input was desired so a keypad version was developed. This proved to be cumbersome, so a small touch screen was added with a Mega processor. The screen size needed to increase to nine inches for usability so the Raspberry Pi Pico processor was selected. For me, the Pico represents the ‘Goldilocks’ processor of very good function, technical stability, and the easy-to-use Arduino IDE. Moving to the Pico enabled LCC migration in 2024 when the Single Thread library began to support the RP2040 processor family. With the OpenLcbCLib, full protocol support was enabled.

## Families

There have been two basic designs, the Node and the Stepper. The Stepper provides for a stepper motor driver and dedicates supporting GP pins. The Node provides 16 GP pins through two 10P IDC connectors. While it will work with either the Pico or Pico2, the latter is recommended due to enhanced capabilities.

I have put the stepper driver circuitry on a separate board which can be driven from the Node board. So there should not be a need to continue with a specific Stepper node board design.

## Common Features

#### Power

The boards provide dual switching power output of 3.3V and 5V with input either from the LCC CAN bus or an external power source between 8 and 15 volts. The boards may be configured to inject power to the CAN bus or to isolate power for either or both of the CAN bus jacks. Auxiliary power outputs for both 3.3V and 5V are available on the board.

#### CAN Bus Control

While there is an early design that uses the MCP251863 integrated CAN controller and transceiver, later designs settled on the MCP2518 and MCP2562 discrete hardware components (chips) for the LCC interface. Both work fine, it is just easier to hand solder the discrete chips.

#### Non-Volatile Memory (NVM)

I2C nonvolatile memory should be used to reduce strain on the Pico flash. External NVM may be attached to either a I2C header, the FRAM Breakout header, or soldered down to the IC5 footprint. If either of the latter two choices are used, the I2C Address jumpers may be used to select non-default addresses or implement write protection. Otherwise, these would be functions of the module plugged into the I2C header.


A typical part would be a module utilizing an AT25C256 chip (left) or RC256V FRAM (right).

Parts compatible with the following should work for soldering to the footprint on the board.

- BR24G512F-3AGTE2 I2C BUS(2-Wre) 512K or other sizes with equivalent pinouts
- MB85RC256VPF-G-BCERE1 256kbit FRAM with I2C

#### I2C

I2C is used to address NVM. One or both of the available I2C channels on the Pico have headers on the board for external devices. Care should be taken should you attach peripherals to the same channel as the NVM lest there be interference. Some I2C devices will require 5 volts and so there is selection via jumper between the two available voltages.

#### Buttons

As there is no reset button on the Pico, one is provided on the board. There is also a header so that a button may be wired in for remote reset. There is also provision for blue and gold buttons should these be desired. Later designs have LEDs for these two buttons.

#### IDC Connections

GP pins and other connections are available via 10P IDC connectors. Pinouts may vary but are printed on the board and in the respective board user guide. Power is provided on pins 5 & 6 and is typically selectable except for the Turntable connector on the Stepper board.

The higher GPIO pins are used on the 2.8 Node board for the second IDC connector making the analog pins usable for node peripherals.

#### Node 2.95


The power circuit has been changed to two separate switching chips vs. the dual channel chip use on previous boards. The chips are identical in function. A board could be built just using the single 5-volt supply and using the Pico 3.3V output pin (through the provided jumper) to power the 3.3V for CAN and NVM circuits. Draw should not exceed 200-250mA in this configuration.

This node puts the analog GPIO pins on a separate connector to simplify the board. The I2C0 connector was removed as these pins are available in the second I/O connector to be used as desired.

#### Node 2.8


This node exposes the analog GPIO pins as an alternate implementation. Other than that, it has essentially the same functionality as Node 2.7.

#### Node 2.7


This node drives two 10P IDC connectors with a total of 16 GPIO pins. It is intended to drive servos and lights or to take inputs from detectors or buttons.

#### Stepper 2.7


This node has provision for a stepper motor driver and is intended to control a turntable and SPI connected display.

#### Stepper 2.4


This node has provision for a stepper motor driver and is intended to control a turntable and parallel connected display.

#### IDC Breakout Boards


Display adapter attaches to a BuyDisplay ER-TFTM101 10.1” touchscreen for SDI display control and I2C touch. There is provision for alternate assignments of line 10 and a reset button.


This IDC breakout has optional LEDs for testing.


This IDC breakout has power and ground pins around the GPIO pin to facilitate connections to inputs, servos, NeoPixels, or another device.


This IDC breakout is intended to carry a stepper driver and provide connections to the stepper motor, sensors, NeoPixel bus, and an I2C connection. There is a separate power connection for the external power used for the stepper motor (12-15V) and for the +5V used for the hall sensors and NeoPixel bus. The IDC connector voltage should be set to 3.3V on the node side.

# Board Pin Assignments

| | | | | 2.5 Node board | 2.6 Node board | 2.7 Node board | 2.8 Node board | 2.95 Node board
1 | gp0 | SPI0 RX | I2C0 SDA | | header pin | header pin | I/0-1:Pin1 | ACAN_RX_PIN | ACAN_RX_PIN
2 | gp1 | SPI0 CSN | I2C0 SCL | | header pin | header pin | I/0-1:Pin2 | ACAN_CS_PIN | ACAN_CS_PIN
3 | GND
4 | gp2 | SPI0 SCK | I2C1 SDA | | Npixel 1 | Npixel 1 | I/0-1:Pin3 | ACAN_CSK_PIN | ACAN_CSK_PIN
5 | gp3 | SPI0 TX | I2C1 SCL | | Npixel 2 | Npixel 2 | I/0-1:Pin4 | ACAN_TX_PIN | ACAN_TX_PIN
6 | gp4 | SPI0 RX | I2C0 SDA | | I2C0 SDA | I2C0 SDA | I/0-1:Pin7 / I2C0 SDA | ACAN_INT_PIN | ACAN_INT_PIN
7 | gp5 | SPI0 CSn | I2C0 SCL | | I2C0 SCL | I2C0 SCL | I/0-1:Pin8 / I2C0 SCL | header pin | header pin
8 | GND
9 | gp6 | SPI0 SCK | I2C1 SDA | | Npixel 3 | Npixel 3 | I/0-1:Pin9 | I2C1 SDA | I2C1 SDA
10 | gp7 | SPI0 TX | I2C1 SCL | | Npixel 4 | Npixel 4 | I/0-1:Pin10 | I2C1 SCL | I2C1 SCL
11 | gp8 | SPI1 RX | I2C0 SDA | | I/0-1:Pin10 | I/O - Pin10 | I/0-2:Pin1 | I/0-1:Pin1 | I/0-1:Pin1
12 | gp9 | SPI1 CSn | I2C0 SCL | | I/0-1:Pin9 | I/O - Pin9 | I/0-2:Pin2 | I/0-1:Pin2 | I/0-1:Pin2
13 | GND
14 | gp10 | SPI1 SCK | I2C1 SDA | | I/0-1:Pin8 | I/O - Pin8 | I/0-2:Pin3 | I/0-1:Pin3 | I/0-1:Pin3
15 | gp11 | SPI1 TX | I2C1 SCL | | I/0-1:Pin7 | I/O - Pin7 | I/0-2:Pin4 | I/0-1:Pin4 | I/0-1:Pin4
16 | gp12 | SPI1 RX | I2C0 SDA | | I/0-1:Pin4 | I/O - Pin4 | I/0-2:Pin7 | I/0-1:Pin7 | I/0-1:Pin7
17 | gp13 | SPI1 CSn | I2C0 SCL | | I/0-1:Pin3 | I/O - Pin3 | I/0-2:Pin8 | I/0-1:Pin8 | I/0-1:Pin8
18 | GND
19 | gp14 | SPI1 SCK | I2C1 SDA | | I/0-1:Pin2 | I/O - Pin2 | I/0-2:Pin9 | I/0-1:Pin9 | I/0-1:Pin9
20 | gp15 | SPI1 TX | I2C1 SCL | | I/0-1:Pin1 | I/O - Pin1 | I/0-2:Pin10 | I/0-1:Pin10 | I/0-1:Pin10
21 | gp16 | SPI0 RX | I2C0 SDA | | ACAN_RX_PIN | ACAN_RX_PIN | ACAN_RX_PIN | I2C0 SDA | I/0-2:Pin1
22 | gp17 | SPI0 CSn | I2C0 SCL | | ACAN_CS_PIN | ACAN_CS_PIN | ACAN_CS_PIN | I2C0 SCL | I/0-2:Pin2
23 | GND
24 | gp18 | SPI0 SCK | I2C1 SDA | | ACAN_CSK_PIN | ACAN_CSK_PIN | ACAN_CSK_PIN | I/0-2:Pin1 | I/0-2:Pin3
25 | gp19 | SPI0 TX | I2C1 SCL | | ACAN_TX_PIN | ACAN_TX_PIN | ACAN_TX_PIN | I/0-2:Pin2 | I/0-2:Pin4
26 | gp20 | | I2C0 SDA | | ACAN_INT_PIN | ACAN_INT_PIN | ACAN_INT_PIN | I/0-2:Pin3 | I/0-2:Pin7
27 | gp21 | | I2C0 SCL | | Blue Button | Blue Button | Blue Button | I/0-2:Pin4 & Blue Button | I/0-2:Pin8 & Blue Button
28 | GND
29 | gp22 | | | | Gold Button | Gold Button | Gold Button | I/0-2:Pin7 & Gold Button | I/0-2:Pin9 & Gold Button
30 | RUN | | | | Reset Button / header | Reset Button / header | Reset Button / header | Reset Button / header | Reset Button / header
31 | gp26 | ADC0 | I2C1 SDA | | I2C1 SDA | I2C1 SDA | I2C1 SDA | I/0-2:Pin8 | I/0-2:Pin10; I/O-3:Pin 1
32 | gp27 | ADC1 | I2C1 SCL | | I2C1 SCL | I2C1 SCL | I2C1 SCL | I/0-2:Pin9 | I/0-3:Pin2
33 | GND | A GND | | | header pin | header pin | header pin | I/0-2:Pin7 alternative | I/0-3:Pin3
34 | gp28 | ADC2 | | | header pin | header pin | header pin | I/0-2:Pin10 | I/0-3:Pin5
35 | | ADC_VREF | | | header pin | header pin | header pin | I/0-2:Pin6 alternative | I/0-3:Pin4
36 | 3v3_OUT
37 | 3V3_EN
38 | GND | | | | | | | | I/0-3:Pin6
39 | VSYS
40 | VBUS
| GND | | | | I/0-1:Pin5 | I/0-1:Pin5 | I/0-1:Pin5 | I/0-1:Pin5 | I/0-1:Pin5
| Vselect1 | | | | I/0-1:Pin6 | I/0-1:Pin6 | I/0-1:Pin6 | I/0-1:Pin6 | I/0-1:Pin6
| GND | | | | | | I/0-2:Pin5
| Vselect2 | | | | | | I/0-2:Pin6

| | | | | 2.4 Stepper board | 2.7 Stepper board | 2.9 Stepper board
1 | gp0 | SPI0 RX | I2C0 SDA | | Bridge sensor | TT-Pin3 - Bridge sensor | ACAN_RX_PIN
2 | gp1 | SPI0 CSN | I2C0 SCL | | Home sensor | TT-Pin2 - Home sensor | ACAN_CS_PIN
3 | GND
4 | gp2 | SPI0 SCK | I2C1 SDA | | Stepper Direction | Stepper Direction | ACAN_CSK_PIN
5 | gp3 | SPI0 TX | I2C1 SCL | | Touch Interrupt | TT-Pin4 - NeoPixel data line | ACAN_TX_PIN
6 | gp4 | SPI0 RX | I2C0 SDA | | Touch SDA | header pin | ACAN_INT_PIN
7 | gp5 | SPI0 CSn | I2C0 SCL | | Touch SCL | header pin | TT-Pin1
8 | GND
9 | gp6 | SPI0 SCK | I2C1 SDA | | Display Data 0 | Stepper Enable | I2C1 SDA
10 | gp7 | SPI0 TX | I2C1 SCL | | Display Data 1 | Stepper Step | I2C1 SCL
11 | gp8 | SPI1 RX | I2C0 SDA | | Display Data 2 | I/0-2:Pin1 : SPI1 SDI | I/0-2:Pin1 : SPI1 SDI
12 | gp9 | SPI1 CSn | I2C0 SCL | | Display Data 3 | I/0-2:Pin2 : SPI1 CS | I/0-2:Pin2 : SPI1 CS
13 | GND
14 | gp10 | SPI1 SCK | I2C1 SDA | | Display Data 4 | I/0-2:Pin3 : SPI1 CLK | I/0-2:Pin3 : SPI1 CLK
15 | gp11 | SPI1 TX | I2C1 SCL | | Display Data 5 | I/0-2:Pin4 : SPI1 SDO | I/0-2:Pin4 : SPI1 SDO
16 | gp12 | SPI1 RX | I2C0 SDA | | Display Data 6 | I/0-2:Pin7 : Touch I2C0 SDA | I/0-2:Pin7 : Touch I2C0 SDA
17 | gp13 | SPI1 CSn | I2C0 SCL | | Display Data 7 | I/0-2:Pin8 : Touch I2C0 SCL | I/0-2:Pin8 : Touch I2C0 SCL
18 | GND
19 | gp14 | SPI1 SCK | I2C1 SDA | | Stepper Enable | I/0-2:Pin9 : Touch INT | I/0-2:Pin9 : Touch INT
20 | gp15 | SPI1 TX | I2C1 SCL | | Stepper Step | I/0-2:Pin10 : open | I/0-2:Pin10 : open
21 | gp16 | SPI0 RX | I2C0 SDA | | ACAN_RX_PIN | ACAN_RX_PIN | I2C0 SDA
22 | gp17 | SPI0 CSn | I2C0 SCL | | ACAN_CS_PIN | ACAN_CS_PIN | I2C0 SCL
23 | GND
24 | gp18 | SPI0 SCK | I2C1 SDA | | ACAN_CSK_PIN | ACAN_CSK_PIN | TT-Pin3 - Bridge sensor
25 | gp19 | SPI0 TX | I2C1 SCL | | ACAN_TX_PIN | ACAN_TX_PIN | TT-Pin2 - Home sensor
26 | gp20 | | I2C0 SDA | | ACAN_INT_PIN | ACAN_INT_PIN | TT-Pin4 - NeoPixel data line
27 | gp21 | | I2C0 SCL | | NeoPixel data line | Blue Button | Blue Button
28 | GND
29 | gp22 | | | | Display WR | Gold Button | Gold Button
30 | RUN | | | | Reset Button | Reset Button / header | Reset Button / header
31 | gp26 | ADC0 | I2C1 SDA | | I2C SDA / Blue Button | I2C1 SDA | Stepper Enable
32 | gp27 | ADC1 | I2C1 SCL | | I2C SCL / Gold Button | I2C1 SCL | Stepper Step
33 | GND | A GND | | | | header pin | header pin
34 | gp28 | ADC2 | | | Display D/C | header pin | Stepper Direction
35 | | ADC_VREF | | | | header pin | header pin
36 | 3v3_OUT
37 | 3V3_EN
38 | GND
39 | VSYS
40 | VBUS
| | | | | | TT-Pin1 - open | TT-Pin1 - open
| GND | | | | | I/0-1:Pin5 | I/0-1:Pin5
| Vselect1 | | | | | I/0-1:Pin6 | I/0-1:Pin6
| GND | | | | | I/0-2:Pin5 | I/0-2:Pin5
| Vselect2 | | | | | I/0-2:Pin6 | I/0-2:Pin6

# Software

Example node applications may be found in:

https://github.com/bocabob/LCC_RPiPico_Turntable

https://github.com/bocabob/LCC_RPiPico_Roundhouse

https://github.com/bocabob/LCC_RPiPico_PixelLights

### Board:

Must use the RP2040 board library by Earle Philhower: https://arduino-pico.readthedocs.io/en/latest/install.html

### LCC support:

https://github.com/openlcb/OpenLCB_Single_Thread

https://github.com/JimKueneman/OpenLcbCLib

### CAN Hardware:

ACAN2517 Arduino library.

### External Storage:

I2C_EEPROM Arduino library by Rob Tillaart

FRAM_I2C Arduino library by Rob Tillaart

### NeoPixel:

NeoPixelBus by Makuna Arduino library (preferred)

NeoPixelConnect Arduino library by Alan Yorinks.

### Other preferred libraries for the RPi Pico:

#### Display

#include <TFT_eSPI_RA8876.h> // display library [modified] https://github.com/bocabob/TFT_eSPI_RA8876

#include <RA8876_RP2040.h> // display library [modified] https://github.com/bocabob/RA8876_RP2040

#include "my_bb_captouch.h" //capacitive touch driver [modified] https://github.com/bocabob/my_bb_captouch

#### Servos

#include <ServoEasing.hpp> // great library for getting slow servo action, including bounces

#include <PCA9685_servo_driver.h>

#include <PCA9685_servo.h>

#### Stepper Motor

#include "AccelStepper.h" // by Mike McCauley [modified]

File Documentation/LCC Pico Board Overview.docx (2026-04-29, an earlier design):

# LCC Pico Board Overview

Documentation, source and gerbers for boards may be found at: https://github.com/bocabob/LCC-RPi-Pico-Board

## Evolution

The LCC Pico development boards evolved from LocoNet designs dating back to 2021. These early turntable boards used Arduino Nanos and depended on turnout commands for indexing to hard-coded stepper positions. Fascia panel input was desired so a keypad version was developed. This proved to be cumbersome, so a small touch screen was added with a Mega processor. The screen size needed to increase to nine inches for usability so the Raspberry Pi Pico processor was selected. For me, the Pico represents the ‘Goldilocks’ processor of very good function, technical stability, and the easy-to-use Arduino IDE. Moving to the Pico enabled LCC migration in 2024 when the Single Thread library began to support the RP2040 processor family. With the OpenLcbCLib, full protocol support was enabled.

## Families

There are two basic designs, the Node and the Stepper. The Stepper provides for a stepper motor driver and dedicates supporting GP pins. The Node provides 16 GP pins through two 10P IDC connectors. While it will work with either the Pico or Pico2, the latter is recommended due to enhanced capabilities.

## Common Features

#### Power

The boards provide dual switching power output of 3.3V and 5V with input either from the LCC CAN bus or an external power source between 8 and 15 volts. The boards may be configured to inject power to the CAN bus or to isolate power for either or both of the CAN bus jacks. Auxiliary power outputs for both 3.3V and 5V are available on the board.

#### CAN Bus Control

While there is an early design that uses the MCP251863 integrated CAN controller and transceiver, later designs settled on the MCP2518 and MCP2562 discrete hardware components (chips) for the LCC interface. Both work fine, it is just easier to hand solder the discrete chips.

#### Non-Volatile Memory (NVM)

I2C nonvolatile memory should be used to reduce strain on the Pico flash. External NVM may be attached to either a I2C header, the FRAM Breakout header, or soldered down to the IC5 footprint. If either of the latter two choices are used, the I2C Address jumpers may be used to select non-default addresses or implement write protection. Otherwise, these would be functions of the module plugged into the I2C header.


A typical part would be a module utilizing an AT25C256 chip (left) or RC256V FRAM (right).

Parts compatible with the following should work for soldering to the footprint on the board.

- BR24G512F-3AGTE2 I2C BUS(2-Wre) 512K or other sizes with equivalent pinouts
- MB85RC256VPF-G-BCERE1 256kbit FRAM with I2C

#### I2C

I2C is used to address NVM. One or both of the available I2C channels on the Pico have headers on the board for external devices. Care should be taken should you attach peripherals to the same channel as the NVM lest there be interference. Some I2C devices will require 5 volts and so there is selection via jumper between the two available voltages.

#### Buttons

As there is no reset button on the Pico, one is provided on the board. There is also a header so that a button may be wired in for remote reset. There is also provision for blue and gold buttons should these be desired. Later designs have LEDs for these two buttons.

#### IDC Connections

GP pins and other connections are available via 10P IDC connectors. Pinouts may vary but are printed on the board and in the respective board user guide. Power is provided on pins 5 & 6 and is typically selectable except for the Turntable connector on the Stepper board.

The higher GPIO pins are used on the 2.8 Node board for the second IDC connector making the analog pins usable for node peripherals.

#### Node 2.8


This node exposes the analog GPIO pins as an alternate implementation. Other than that, it has essentially the same functionality as Node 2.7.

#### Node 2.7


This node drives two 10P IDC connectors with a total of 16 GPIO pins. It is intended to drive servos and lights or to take inputs from detectors or buttons.

#### Stepper 2.7


This node has provision for a stepper motor driver and is intended to control a turntable and SPI connected display.

#### Stepper 2.4


This node has provision for a stepper motor driver and is intended to control a turntable and parallel connected display.

#### IDC Breakout Boards


Display adapter attaches to a BuyDisplay ER-TFTM101 10.1” touchscreen for SDI display control and I2C touch. There is provision for alternate assignments of line 10 and a reset button.


This IDC breakout has optional LEDs for testing.


This IDC breakout has power and ground pins around the GPIO pin to facilitate connections to inputs, servos, NeoPixels, or another device.

# Board Pin Assignments

| | | | | 2.5 Node board | 2.6 Node board | 2.7 Node board | 2.8 Node board | 2.4 Stepper board | 2.7 Stepper board
1 | gp0 | SPI0 RX | I2C0 SDA | | header pin | header pin | I/0-1:Pin1 | ACAN_RX_PIN | Bridge sensor | TT-Pin3 - Bridge sensor
2 | gp1 | SPI0 CSN | I2C0 SCL | | header pin | header pin | I/0-1:Pin2 | ACAN_CS_PIN | Home sensor | TT-Pin2 - Home sensor
3 | GND
4 | gp2 | SPI0 SCK | I2C1 SDA | | Npixel 1 | Npixel 1 | I/0-1:Pin3 | ACAN_CSK_PIN | Stepper Direction | Stepper Direction
5 | gp3 | SPI0 TX | I2C1 SCL | | Npixel 2 | Npixel 2 | I/0-1:Pin4 | ACAN_TX_PIN | Touch Interrupt | TT-Pin4 - NeoPixel data line
6 | gp4 | SPI0 RX | I2C0 SDA | | I2C0 SDA | I2C0 SDA | I/0-1:Pin7 / I2C0 SDA | ACAN_INT_PIN | Touch SDA | header pin
7 | gp5 | SPI0 CSn | I2C0 SCL | | I2C0 SCL | I2C0 SCL | I/0-1:Pin8 / I2C0 SCL | header pin | Touch SCL | header pin
8 | GND
9 | gp6 | SPI0 SCK | I2C1 SDA | | Npixel 3 | Npixel 3 | I/0-1:Pin9 | I2C1 SDA | Display Data 0 | Stepper Enable
10 | gp7 | SPI0 TX | I2C1 SCL | | Npixel 4 | Npixel 4 | I/0-1:Pin10 | I2C1 SCL | Display Data 1 | Stepper Step
11 | gp8 | SPI1 RX | I2C0 SDA | | I/0-1:Pin10 | I/O - Pin10 | I/0-2:Pin1 | I/0-1:Pin1 | Display Data 2 | I/0-2:Pin1 : SPI1 SDI
12 | gp9 | SPI1 CSn | I2C0 SCL | | I/0-1:Pin9 | I/O - Pin9 | I/0-2:Pin2 | I/0-1:Pin2 | Display Data 3 | I/0-2:Pin2 : SPI1 CS
13 | GND
14 | gp10 | SPI1 SCK | I2C1 SDA | | I/0-1:Pin8 | I/O - Pin8 | I/0-2:Pin3 | I/0-1:Pin3 | Display Data 4 | I/0-2:Pin3 : SPI1 CLK
15 | gp11 | SPI1 TX | I2C1 SCL | | I/0-1:Pin7 | I/O - Pin7 | I/0-2:Pin4 | I/0-1:Pin4 | Display Data 5 | I/0-2:Pin4 : SPI1 SDO
16 | gp12 | SPI1 RX | I2C0 SDA | | I/0-1:Pin4 | I/O - Pin4 | I/0-2:Pin7 | I/0-1:Pin7 | Display Data 6 | I/0-2:Pin7 : Touch I2C0 SDA
17 | gp13 | SPI1 CSn | I2C0 SCL | | I/0-1:Pin3 | I/O - Pin3 | I/0-2:Pin8 | I/0-1:Pin8 | Display Data 7 | I/0-2:Pin8 : Touch I2C0 SCL
18 | GND
19 | gp14 | SPI1 SCK | I2C1 SDA | | I/0-1:Pin2 | I/O - Pin2 | I/0-2:Pin9 | I/0-1:Pin9 | Stepper Enable | I/0-2:Pin9 : Touch INT
20 | gp15 | SPI1 TX | I2C1 SCL | | I/0-1:Pin1 | I/O - Pin1 | I/0-2:Pin10 | I/0-1:Pin10 | Stepper Step | I/0-2:Pin10 : open
21 | gp16 | SPI0 RX | I2C0 SDA | | ACAN_RX_PIN | ACAN_RX_PIN | ACAN_RX_PIN | I2C0 SDA | ACAN_RX_PIN | ACAN_RX_PIN
22 | gp17 | SPI0 CSn | I2C0 SCL | | ACAN_CS_PIN | ACAN_CS_PIN | ACAN_CS_PIN | I2C0 SCL | ACAN_CS_PIN | ACAN_CS_PIN
23 | GND
24 | gp18 | SPI0 SCK | I2C1 SDA | | ACAN_CSK_PIN | ACAN_CSK_PIN | ACAN_CSK_PIN | I/0-2:Pin1 | ACAN_CSK_PIN | ACAN_CSK_PIN
25 | gp19 | SPI0 TX | I2C1 SCL | | ACAN_TX_PIN | ACAN_TX_PIN | ACAN_TX_PIN | I/0-2:Pin2 | ACAN_TX_PIN | ACAN_TX_PIN
26 | gp20 | | I2C0 SDA | | ACAN_INT_PIN | ACAN_INT_PIN | ACAN_INT_PIN | I/0-2:Pin3 | ACAN_INT_PIN | ACAN_INT_PIN
27 | gp21 | | I2C0 SCL | | Blue Button | Blue Button | Blue Button | I/0-2:Pin4 & Blue Button | NeoPixel data line | Blue Button
28 | GND
29 | gp22 | | | | Gold Button | Gold Button | Gold Button | I/0-2:Pin7 & Gold Button | Display WR | Gold Button
30 | RUN | | | | Reset Button / header | Reset Button / header | Reset Button / header | Reset Button / header | Reset Button | Reset Button / header
31 | gp26 | ADC0 | I2C1 SDA | | I2C1 SDA | I2C1 SDA | I2C1 SDA | I/0-2:Pin8 | I2C SDA / Blue Button | I2C1 SDA
32 | gp27 | ADC1 | I2C1 SCL | | I2C1 SCL | I2C1 SCL | I2C1 SCL | I/0-2:Pin9 | I2C SCL / Gold Button | I2C1 SCL
33 | GND | A GND | | | header pin | header pin | header pin | I/0-2:Pin7 alternative | | header pin
34 | gp28 | ADC2 | | | header pin | header pin | header pin | I/0-2:Pin10 | Display D/C | header pin
35 | | ADC_VREF | | | header pin | header pin | header pin | I/0-2:Pin6 alternative | | header pin
36 | 3v3_OUT
37 | 3V3_EN
38 | GND
39 | VSYS
40 | VBUS
| | | | | | | | | | TT-Pin1 - open
| GND | | | | I/0-1:Pin5 | I/0-1:Pin5 | I/0-1:Pin5 | I/0-1:Pin5 | | I/0-1:Pin5
| Vselect1 | | | | I/0-1:Pin6 | I/0-1:Pin6 | I/0-1:Pin6 | I/0-1:Pin6 | | I/0-1:Pin6
| GND | | | | | | I/0-2:Pin5 | | | I/0-2:Pin5
| Vselect2 | | | | | | I/0-2:Pin6 | | | I/0-2:Pin6

# Software

Example node applications may be found in:

https://github.com/bocabob/LCC_RPiPico_Turntable

https://github.com/bocabob/LCC_RPiPico_Roundhouse

https://github.com/bocabob/LCC_RPiPico_PixelLights

### Board:

Must use the RP2040 board library by Earle Philhower: https://arduino-pico.readthedocs.io/en/latest/install.html

### LCC support:

https://github.com/openlcb/OpenLCB_Single_Thread

https://github.com/JimKueneman/OpenLcbCLib

### CAN Hardware:

ACAN2517 Arduino library.

### External Storage:

I2C_EEPROM Arduino library by Rob Tillaart

FRAM_I2C Arduino library by Rob Tillaart

### NeoPixel:

NeoPixelBus by Makuna Arduino library (preferred)

NeoPixelConnect Arduino library by Alan Yorinks.

### Other preferred libraries for the RPi Pico:

#### Display

#include <TFT_eSPI_RA8876.h> // display library [modified] https://github.com/bocabob/TFT_eSPI_RA8876

#include <RA8876_RP2040.h> // display library [modified] https://github.com/bocabob/RA8876_RP2040

#include "my_bb_captouch.h" //capacitive touch driver [modified] https://github.com/bocabob/my_bb_captouch

#### Servos

#include <ServoEasing.hpp> // great library for getting slow servo action, including bounces

#include <PCA9685_servo_driver.h>

#include <PCA9685_servo.h>

#### Stepper Motor

#include "AccelStepper.h" // by Mike McCauley [modified]

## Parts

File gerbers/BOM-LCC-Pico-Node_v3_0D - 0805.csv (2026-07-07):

Comment | Designator | Footprint | LCSC | Quantity
0ZCG0050AF2C | F1,F2 | FUSC4632X70N | C3762102 | 2
100nF | C1,C15,C19,C3,C6 | C_0805_2012Metric | C49678 | 5
10K | R13,R14,R8,R9 | R_0805_2012Metric | C17414 | 4
10nF | C17,C22 | C_0805_2012Metric | C1710 | 2
124K | R1 | R_0805_2012Metric | C2902861 | 1
1uF | C18,C7 | C_0805_2012Metric | C28323 | 2
22.1K | R2,R4 | R_0805_2012Metric | C865310 | 2
22pF | C13,C14 | C_0805_2012Metric | C1804 | 2
22uF | C10,C11,C12,C4,C5,C8,C9 | C_0805_2012Metric | C45783 | 7
256Kb | IC5 | SOIC127P600X175-8N | C90485 | 1
2K | R11 | R_0805_2012Metric | C17604 | 1
3.3uH | L1 | L_1210_3225Metric | C337905 | 1
3K | R5 | R_0805_2012Metric | C17661 | 1
4.7uF | C16 | C_0805_2012Metric | C1779 | 1
4.7uH | L2 | L_1210_3225Metric | C1330201 | 1
470uF | C2 | CP_Elec_8x10.5 | C48935389 | 1
560R | R18,R19,R7 | R_0805_2012Metric | C28636 | 3
6k8 | R15 | R_0805_2012Metric | C17772 | 1
73.2K | R3 | R_0805_2012Metric | C422816 | 1
820R | R6 | R_0805_2012Metric | C17837 | 1
ABM-40MHZ | Y1 | ABM3 | C1986264 | 1
Barrel Jack | J20 | DC-050_SMD | C431534 | 1
DMG2305UX-7 | Q1 | SOT96P240X115-3N | C150470 | 1
LED | D1,D12,D4,D5,D7,D8 | LED_0805_2012Metric | C2297 | 6
M7 | D10,D2,D3,D9 | D_SMA | C22448047 | 4
MCP2518FD | IC2 | SOIC-14_3.9x8.7mm_P1.27mm | C626758 | 1
MCP2562FD | IC3 | SOIC-8_3.9x4.9mm_P1.27mm | C511335 | 1
RJ45 | J1,J2 | MTJ880X1 | C7235899 | 2
TPS54228DR | IC1,IC6 | SOIC127P600X170-9N | C263275 | 2
button | SW1,SW2,SW3 | SW_Push_1P1T_XKB_TS-1187A | C318884 | 3
I/O - 1 | J21 | IDC-Header_2x05_P2.54mm_Vertical |  | 1
Raspberry Pi Pico | RPiPico1 | RPi_Pico_SMD_TH |  | 1
Ext. Reset | J24 | PinHeader_1x02_P2.54mm_Vertical |  | 1
Power Sel | J6 | SLW8645872ARAND |  | 1
External Power | J5 | PhoenixContact_MSTBA_2,5_2-G-5,08_1x02_P5.08mm_Horizontal |  | 1
Analog I/O | J15 | IDC-Header_2x03_P2.54mm_Vertical |  | 1
LCC Pwr Sel | J3 | SLW8645872ARAND |  | 1
Power Sel | J12 | SLW8645872ARAND |  | 1
I/O - 2 | J4 | IDC-Header_2x05_P2.54mm_Vertical |  | 1
MasterPower | J27 | PinHeader_1x02_P2.54mm_Vertical |  | 1
External Power | J7 | JST_EH_B3B-EH-A_1x03_P2.50mm_Vertical |  | 1

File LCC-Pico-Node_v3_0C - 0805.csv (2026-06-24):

Qty | Reference | Value | Manufacturer_Name | Manufacturer_Part_Number | Description | LCSC
1 | R1 | 124K |  |  |  | C2902861
2 | R2,R4 | 22.1K |  |  |  | C865310
1 | R3 | 73.2K |  |  |  | C422816
1 | R5 | 3K |  |  |  | C17661
1 | R6 | 820R |  |  |  | C17837
3 | R7,R18,R19 | 560R |  |  |  | C28636
4 | R8,R9,R13,R14 | 10K |  |  |  | C17414
1 | R11 | 2K |  |  |  | C17604
1 | R15 | 6k8 |  |  |  | C17772
1 | RPiPico1 | Raspberry Pi Pico
1 | IC3 | MCP2562FD | NXP | TJA1042T/3/1J | High-Speed CAN Transceiver, 1Mbps, 5V supply, Vio pin, -40C to +125C, SOIC-8 | C511335
2 | IC1,IC6 | TPS54228DR | Texas Instruments | TPS54228DDAR | 4.5V to 18V Input, 2-A Synchronous Step-Down Converter with Eco-mode&#153; | C263275
1 | Y1 | ABM-40MHZ | ABRACON | ABM3-40.000MHZ-B2-T | 40 MHz +/-20ppm Crystal 18pF 25 Ohms 2-SMD, No Lead | C1986264
2 | J1,J2 | RJ45 | Adam Tech | MTJ-880X1 | Conn Modular Jack F 8 POS 1.27mm Solder RA Thru-Hole 8 Terminal 1 Port Cat 5/Cat 5e | C7235899
1 | IC2 | MCP2518FD | Microchip | MCP2518FDT-E/SL | CAN Interface IC Stand-alone Low Power CAN FD Controller w/SPI Interface Grade1 | C626758
1 | IC5 | 256Kb | ROHM Semiconductor | BR24G256F-5E2 | EEPROM ICs, Memory, 256KBit, I&sup2;C BUS, High Endurance, Low Power Serial EEPROM | C90485
3 | SW1,SW2,SW3 | button | Same Sky | TS11-674-43-BK-160-RA-D | Tactile Switches 6 x 7.4 mm 4.3 mm 160 gf Black Right Angle Through Hole SPST | C318884
1 | Q1 | DMG2305UX-7 | Diodes Incorporated | DMG2305UX-7 | MOSFET P-Ch 20V 5A Enhancement SOT23 Diodes Inc DMG2305UX-7 P-channel MOSFET Transistor, -3.3 A, -20 V, 3-Pin SOT-23 | C150470
2 | F1,F2 | 0ZCG0050AF2C | Bel | 0ZCG0050AF2C | Resettable Fuses - PPTC | C3762102
1 | L1 | 3.3uH | Murata Electronics | 1277AS-H-3R3M=P2 | Ind,3.2x2.5x1mm,3.3uH+/-20%,3.1A,shd | C337905
1 | L2 | 4.7uH | Murata | 1276AS-H-4R7M=P2 | Ind,3.2x2.5x1mm,4.7uH+/-20%,3.1A,shd | C1330201
5 | C1,C3,C6,C15,C19 | 100nF |  |  | Unpolarized capacitor, small symbol | C49678
1 | C2 | 470uF |  |  | Polarized capacitor, small symbol | C48935389
7 | C4,C5,C8,C9,C10,C11,C12 | 22uF |  |  | Unpolarized capacitor, small symbol | C45783
2 | C7,C18 | 1uF |  |  | Unpolarized capacitor, small symbol | C28323
2 | C13,C14 | 22pF |  |  | Unpolarized capacitor, small symbol | C1804
1 | C16 | 4.7uF |  |  | Unpolarized capacitor, small symbol | C1779
2 | C17,C22 | 10nF |  |  | Unpolarized capacitor, small symbol | C1710
6 | D1,D4,D5,D7,D8,D12 | LED |  |  |  | C2297
4 | D2,D3,D9,D10 | M7 |  |  | Diode | C22448047
1 | J3 | LCC Pwr Sel |  |  | Switch, single pole double throw
1 | J4 | I/O - 2
2 | J5,J7 | External Power |  |  | Generic screw terminal, single row, 01x02, script generated (kicad-library-utils/schlib/autogen/connector/),Generic screw terminal, single row, 01x03, script generated (kicad-library-utils/schlib/autogen/connector/)
2 | J6,J12 | Power Sel |  |  | Switch, single pole double throw
1 | J15 | Analog I/O |  |  | Generic connector, double row, 02x03, odd/even pin numbering scheme (row 1 odd numbers, row 2 even numbers), script generated (kicad-library-utils/schlib/autogen/connector/)
1 | J20 | Barrel Jack |  |  |  | C431534
1 | J21 | I/O - 1
1 | J24 | Ext. Reset |  |  | Generic connector, single row, 01x02, script generated (kicad-library-utils/schlib/autogen/connector/)
1 | J27 | MasterPower |  |  | Generic connector, single row, 01x02, script generated (kicad-library-utils/schlib/autogen/connector/)

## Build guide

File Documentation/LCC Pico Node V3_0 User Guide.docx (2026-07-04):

# LCC Pico Node User Guide

Version 3.0

This version utilizes the MCP2815 and MCP2562 discrete hardware components (chips) for the LCC interface.

The intent of this node is to control 16 pins on two 10 pin IDC connectors for a model railroad layout. It exposes 16 GP pins through two 10P IDC connectors, plus an additional 6-pin analog header (I/O-3), for general-purpose I/O. While it will work with either the Pico or Pico2, the latter is recommended due to enhanced capabilities.

There are no resistors on the Reset, Blue, and Gold button lines other than for the Blue and Gold LEDs.

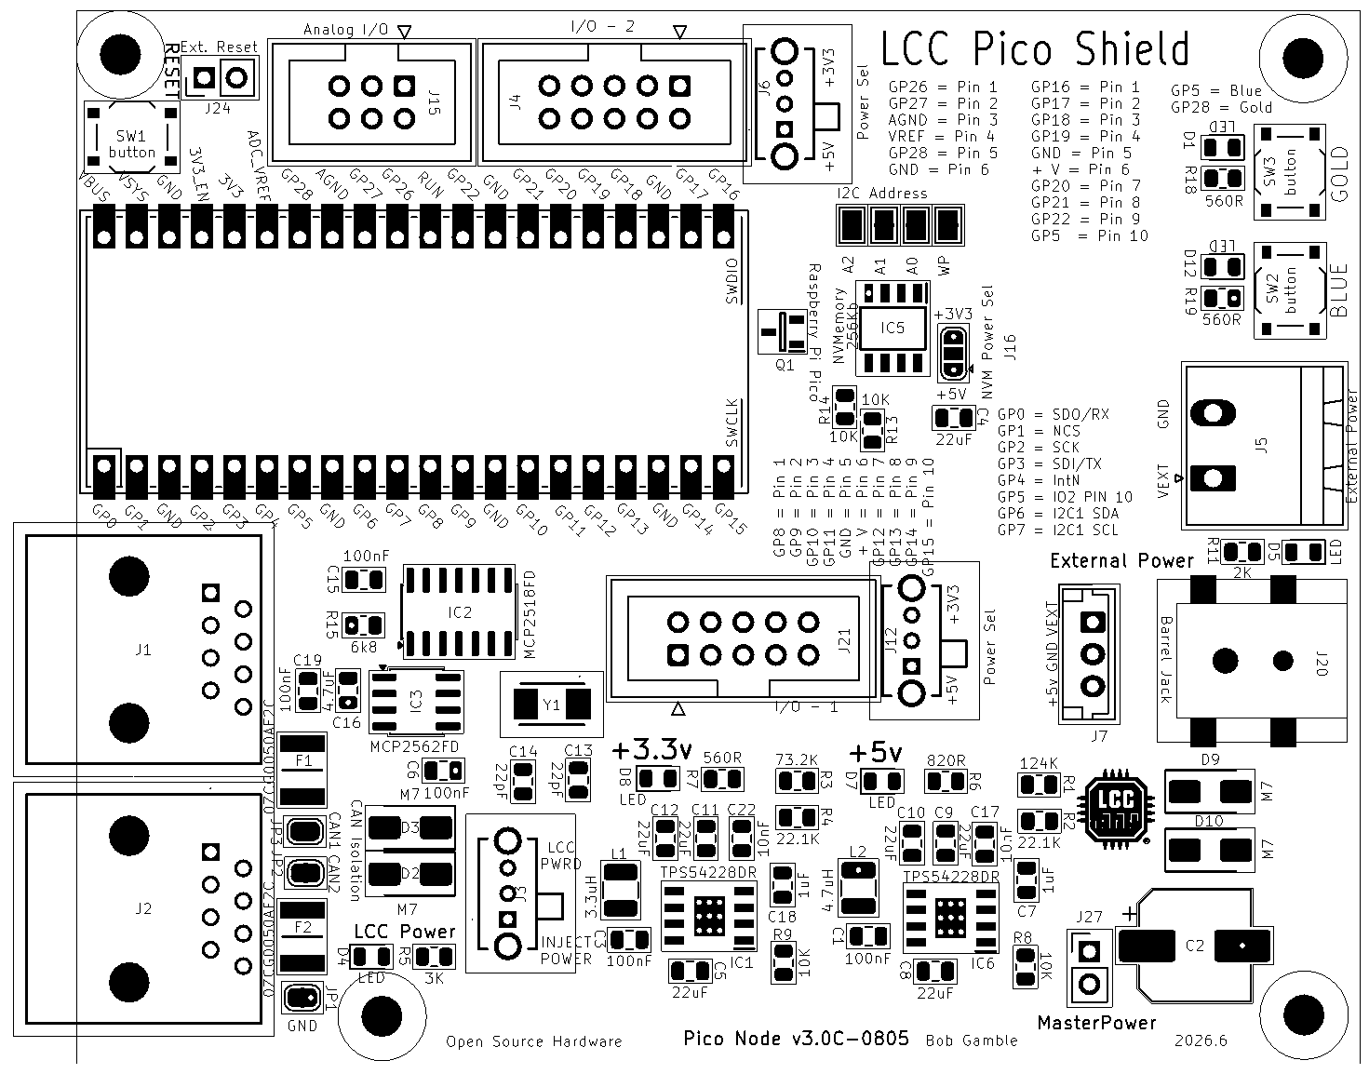
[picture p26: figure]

The node may be powered from the barrel/terminal jack or the LCC port. The barrel jack power should be at least eight (8) volts to power the microcontroller or fifteen (15) volts [or your preferred LCC voltage] if using the node to inject power to LCC. Amperage should be sufficient to drive any external devices plus about half an amp for the node plus another 1.5 amps if injecting power to LCC. There are four power LEDs. The 3.3- and 5-volt LEDs should be lit to indicate that the node is properly powered.

Node power configuration is accomplished with five jumpers located behind the LCC ports.

J1 Pwr (JP2) and J2 Pwr (JP3) jumpers allow power isolation of one or both LCC ports. Generally, both jumpers would be bridged. If power injection or utilization was only desired in one direction, then the opposing jumper would be opened to isolate that leg. The isolated leg should be powered downstream as opening the jumper will cut off any power from the node.

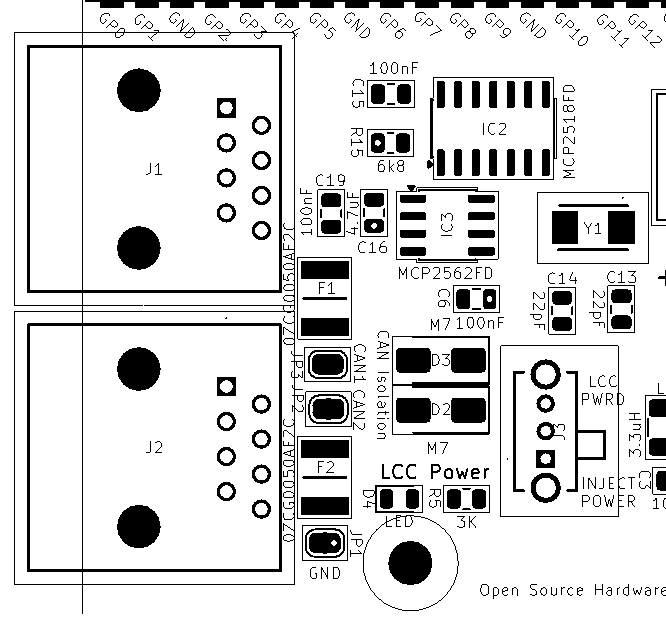
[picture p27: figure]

LCC Grnd jumper should be bridged. If cut, ground will be isolated from the CAN bus which may impact communication.

Switch position for LCC Pwrd should be selected if the node is to be powered from the LCC Port.

Inject Power should be selected if the node is intended to inject power to one or both of the LCC ports. 15 volts of at least 1.5 amps should be applied externally in order to inject power.

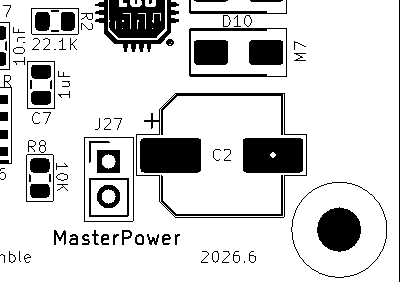
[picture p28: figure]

Master Power jumper should be bridged to power the node. A normally closed button may be plugged in here as a means to do a hardware reset should there be a need to hard cycle the power.

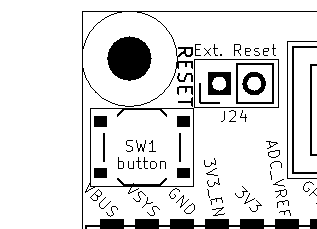
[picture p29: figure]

J24 jumper may be attached to a normally open button to function as a Reset as it is in parallel to the on board Reset button.

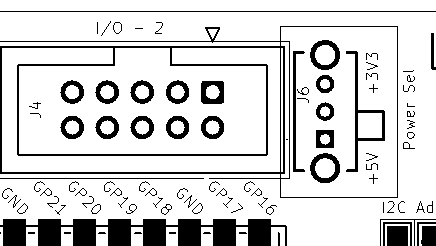
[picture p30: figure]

The power applied to the middle pins of the IDC connector may be selected by the power selection switch. Pin assignments are noted on the PCB.

The power applied to the middle pins of the IDC connector may be selected by the power selection switch and the solder jumper. Pin assignments are noted on the PCB.

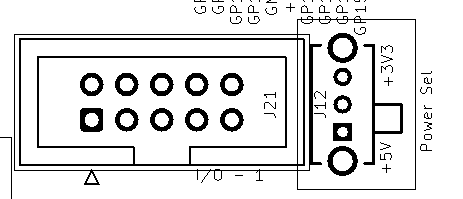
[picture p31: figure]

# NVM Storage

I2C nonvolatile memory is used to reduce strain on the Pico flash. External NVM is soldered down to the IC5 footprint. The I2C Address jumpers may be used to select non-default addresses or implement write protection. Otherwise, these would be functions of the module plugged into the I2C header.

Parts compatible with the following should work for soldering to the footprint on the board.

- BR24G256F-3AGTE2 I2C BUS(2-Wre) 256K or other sizes with equivalent pinouts
- MB85RC256VPF-G-BCERE1 256kbit FRAM with I2C

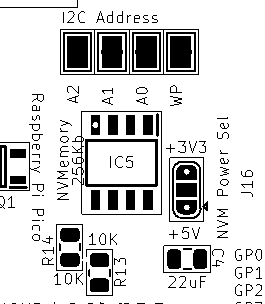
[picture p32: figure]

3.3V is the preferred selection for this solder jumper. The selection will apply to the soldered NVM module.

I2C address may be selected by the left three jumpers.

I2C nonvolatile memory may be populated if desired to reduce strain on the Pico flash. Parts compatible with these should work.

BR24G256F-3AGTE2 I2C BUS(2-Wre) 256K

MB85RC256VPF-G-BCERE1 256kbit FRAM with I2C

### Board Pin Assignments

Pin | GP | Alt 1 | Alt 2 | v3.0 Node
1 | gp0 | SPI0 RX | I2C0 SDA | ACAN_RX_PIN
2 | gp1 | SPI0 CSN | I2C0 SCL | ACAN_CS_PIN
3 | GND
4 | gp2 | SPI0 SCK | I2C1 SDA | ACAN_CSK_PIN
5 | gp3 | SPI0 TX | I2C1 SCL | ACAN_TX_PIN
6 | gp4 | SPI0 RX | I2C0 SDA | ACAN_INT_PIN
7 | gp5 | SPI0 CSn | I2C0 SCL | I/O-2: Pin 10 & Blue Button
8 | GND
9 | gp6 | SPI0 SCK | I2C1 SDA | I2C1 SDA
10 | gp7 | SPI0 TX | I2C1 SCL | I2C1 SCL
11 | gp8 | SPI1 RX | I2C0 SDA | I/O-1: Pin 1
12 | gp9 | SPI1 CSn | I2C0 SCL | I/O-1: Pin 2
13 | GND
14 | gp10 | SPI1 SCK | I2C1 SDA | I/O-1: Pin 3
15 | gp11 | SPI1 TX | I2C1 SCL | I/O-1: Pin 4
16 | gp12 | SPI1 RX | I2C0 SDA | I/O-1: Pin 7
17 | gp13 | SPI1 CSn | I2C0 SCL | I/O-1: Pin 8
18 | GND
19 | gp14 | SPI1 SCK | I2C1 SDA | I/O-1: Pin 9
20 | gp15 | SPI1 TX | I2C1 SCL | I/O-1: Pin 10
21 | gp16 | SPI0 RX | I2C0 SDA | I/O-2: Pin 1
22 | gp17 | SPI0 CSn | I2C0 SCL | I/O-2: Pin 2
23 | GND
24 | gp18 | SPI0 SCK | I2C1 SDA | I/O-2: Pin 3
25 | gp19 | SPI0 TX | I2C1 SCL | I/O-2: Pin 4
26 | gp20 | | I2C0 SDA | I/O-2: Pin 7
27 | gp21 | | I2C0 SCL | I/O-2: Pin 8
28 | GND
29 | gp22 | | | I/O-2: Pin 9
30 | RUN | | | Reset Button / header
31 | gp26 | ADC0 | I2C1 SDA | I/O-3: Pin 1
32 | gp27 | ADC1 | I2C1 SCL | I/O-3: Pin 2
33 | GND | A GND | | I/O-3: Pin 3 (AGND)
34 | gp28 | ADC2 | | I/O-3: Pin 5 & Gold Button
35 | | ADC_VREF | | I/O-3: Pin 4 (VREF)
36 | 3v3_OUT
37 | 3V3_EN
38 | GND
39 | VSYS
40 | VBUS
| GND | | | I/O-1: Pin 5
| Vselect1 | | | I/O-1: Pin 6
| GND | | | I/O-2: Pin 5
| Vselect2 | | | I/O-2: Pin 6

Note: I/O-2 Pin 10 (gp5) and I/O-3 Pin 5 (gp28) double as the Blue and Gold buttons. A breakout that uses either of those pins makes the corresponding button unavailable.

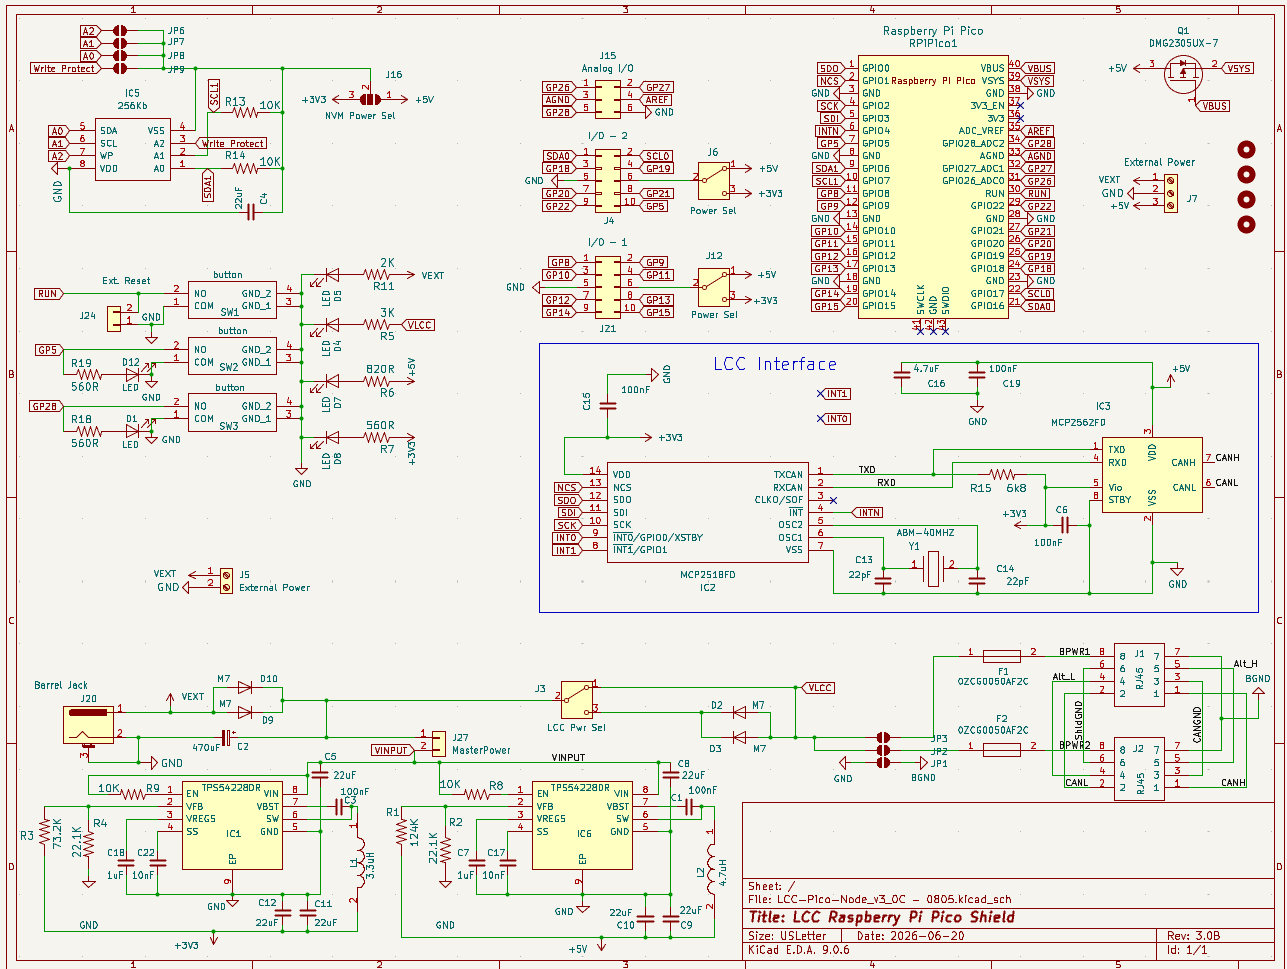
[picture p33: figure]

# Bill of Materials

Qty | Value | Reference | Mfr. # | Description
5 | 0.1uF, 100nF | C1,C3,C6,C15,C19 | C1206C104K3RAC7411 | Multilayer Ceramic Capacitors MLCC - SMD/SMT 25V 0.1uF X7R 1206 10%
1 | 470uF | C2 | REF1016471M035K | Aluminum Electrolytic Capacitor
7 | 22uF | C4,C5,C8,C9,C10,C11,C12 | CL31A226MOCLNNC | Multilayer Ceramic Capacitors MLCC - SMD/SMT 22uF+/-20% 16V X5R 3 1206
2 | 1uF | C7, C18 | CL31B105KAHNFNE | Multilayer Ceramic Capacitors MLCC - SMD/SMT 1uF+/-10% 25V X7R 32 1206
2 | 22pF | C13,C14 | C1206C220J3HACTU | Multilayer Ceramic Capacitors MLCC - SMD/SMT 25V 22pF X8R 1206 5%
1 | 4.7uF | C16 | CL31B475KOHNFNE | Multilayer Ceramic Capacitors MLCC - SMD/SMT 4.7uF+/-10% 16V X7R 1206
2 | 10nF | C17, C22
6 | LED | D1,D4,D5,D7,D8,D12 | 156120VS75000 | Single Color LEDs WL-SMRW SMD RvMt Mon Wtrclr Rect 1206BtGn
4 | M7 | D2,D3,D9,D10 | M7 | Rectifiers Diode, SMA, 1000V, 1A
2 | 0ZCG0050AF2C | F1,F2 | 0ZCG0050AF2C | Resettable Fuses - PPTC
1 | TPS54228DDAR | IC1, IC6 | TPS54228DDAR | 4.5V to 18V Input, 2-A Synchronous Step-Down Converter with Eco-mode&#153;
1 | MCP2518FDT-E_SL | IC2 | MCP2518FDT-E/SL | CAN Interface IC Stand-alone Low Power CAN FD Controller w/SPI Interface Grade1
1 | MCP2562FDT-E/SN | IC3 | MCP2562FDT-E/SN | CAN Interface IC CAN Flexible Data Rate Transceiver
1 | TPS3840DxNBR | IC4
1 | 256Kb | IC5 | BR24G256F-5E2 | EEPROM I2C BUS(2-Wre) 256K SOP8 EEPROM
2 | RJ45 | J1,J2 | MTJ-880X1 | Modular Connectors / Ethernet Connectors 8P8C TYPE 0 GLD FLSH BLK
1 | 3.3uH | L1 | 1277AS-H-3R3M=P2 | Power Inductors - SMD Ind,3.2x2.5x1mm,3.3uH+/-20%,4A, shd AEC-Q200
1 | 4.7uH | L2 | 1276AS-H-4R7M=P2 | Power Inductors - SMD Ind,3.2x2.5x1mm,4.7uH+/-20%,3.1A, shd AEC-Q200
1 | DMG2305UX-7 | Q1 | DMG2305UX-7 | MOSFETs P-Ch ENH FET -20V 52mOh -5A
1 | 124K | R1 | ERA-8AEB1243V | Thin Film Resistors - SMD 1206 124Kohm 25ppm 0.1% AEC-Q200
2 | 22.1K | R2,R4 | ERA-8AEB2212V | Thin Film Resistors - SMD 1206 22.1Kohm 25ppm 0.1% AEC-Q200
1 | 73.2K | R3 | ERA-8AEB7322V | Thin Film Resistors - SMD 1206 73.2Kohm 25ppm 0.1% AEC-Q200
1 | 3K | R5
1 | 820R | R6 | RT1206FRE07820RL | Thin Film Resistors - SMD 1/4W 820 ohm 1% 50ppm
3 | 560R | R7,R18,R19 | RT1206FRE07560RL | Thin Film Resistors - SMD 560 OHM 1% 50PPM 1/4W
4 | 10K | R8,R9,R13,R14
1 | 2K | R11 | RT1206FRE072KL | Thin Film Resistors - SMD 1/4W 2K ohm 1% 50ppm
1 | 6k8 | R15 | RT1206DRD076K8L | Thin Film Resistors - SMD 6.8 kOhms 250 mW 0.5 % 1206
1 | Raspberry Pi Pico | RPiPico1
3 | button | SW1, SW2, SW3 | | Tactile Switch
1 | ABM-40MHZ | Y1 | ABM3-40.000MHZ-B2-T | Crystals Xtal 5032 2-SMD 40MHz Tol +/-20ppm Stab +/-50ppm -20C - 70C 18pF 25 Ohms

### Connections:

J3 | Select power from LCC or Inject Power to LCC
J4, J21 | 10 pin IDC connector I/O
J6,J12 | 3.3/5 Volt Power Selection
J16 | FRAM Power Select
J7 | power out
J5 | Power terminal block
J20 | Barrel Jack power input
J24 | External Reset header
J27 | MasterPower bridge header
JP2 | J2 LCC Power enable
JP3 | J1 LCC Power enable
JP1 | LCC Ground enable
JP6-9 | NVM Address & WP

# Software

## Example Node Applications

- https://github.com/bocabob/LCC_RPiPico_Turntable
- https://github.com/bocabob/LCC_RPiPico_Roundhouse
- https://github.com/bocabob/LCC_RPiPico_PixelLights
- https://github.com/bocabob/LCC_RPiPico_Clock_Lights

## Architectural Standard

Cross-project firmware conventions (board versioning, breakout pin assignments, configuration memory, naming) for all node applications above are documented in: https://github.com/bocabob/LCC_RPiPico_Common

## Board Support

Use the RP2040 board library by Earle Philhower: https://arduino-pico.readthedocs.io/en/latest/install.html

## LCC Support

- https://github.com/openlcb/OpenLCB_Single_Thread
- https://github.com/JimKueneman/OpenLcbCLib

## CAN Hardware

- ACAN2517 Arduino library

## External Storage

- I2C_EEPROM Arduino library by Rob Tillaart
- FRAM_I2C Arduino library by Rob Tillaart

## NeoPixel

- NeoPixelBus by Makuna (preferred)
- NeoPixelConnect by Alan Yorinks

### Other Preferred Libraries

#### Display

- TFT_eSPI_RA8876.h — display library (modified): https://github.com/bocabob/TFT_eSPI_RA8876
- RA8876_RP2040.h — display library (modified): https://github.com/bocabob/RA8876_RP2040
- my_bb_captouch.h — capacitive touch driver (modified): https://github.com/bocabob/my_bb_captouch

#### Servos

- ServoEasing.hpp — for slow servo action, including bounces
- PCA9685_servo_driver.h
- PCA9685_servo.h

#### Stepper Motor

- AccelStepper.h by Mike McCauley (modified)

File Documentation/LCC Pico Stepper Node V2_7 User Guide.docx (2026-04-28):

# LCC Pico Turntable Node User Guide

Version 2.7

This version utilizes the MCP2815 and MCP2562 discrete components for the LCC interface.

The intent of this node is to control all aspects of a turntable on a model railroad layout. It can also produce events to control other LCC actions such as servo activated roundhouse doors or lighting. It may also be adapted to several other uses by connecting to exposed pins on the Raspberry Pi Pico microcontroller.

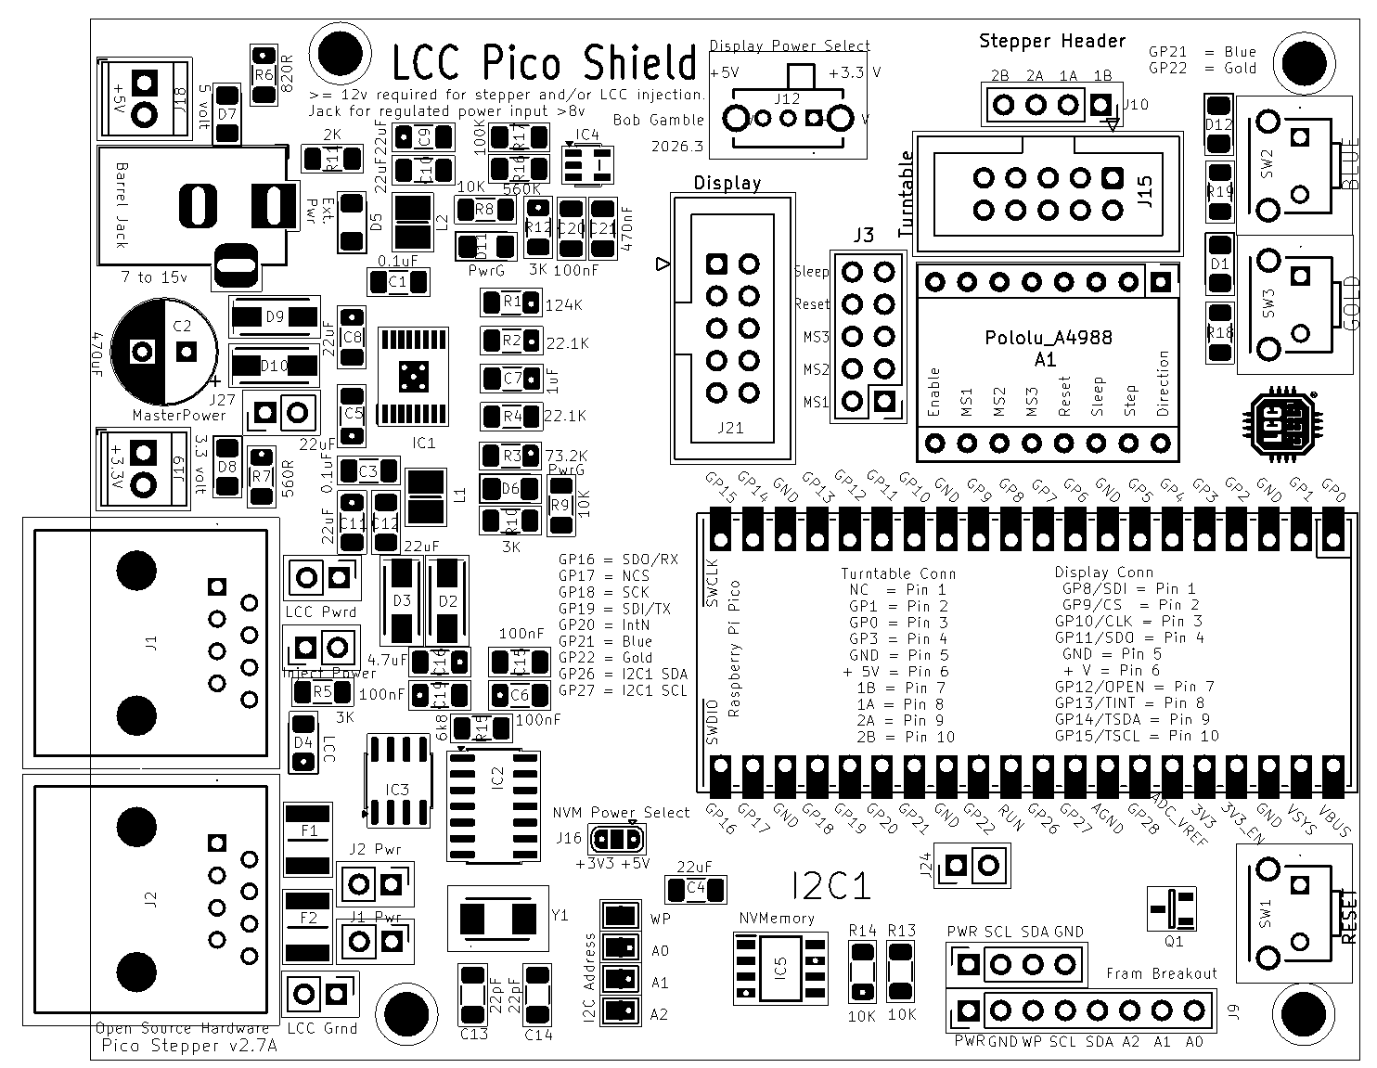
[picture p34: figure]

The node may be powered from the barrel jack or the LCC port. If driving a stepper motor power must be applied from the barrel jack. In this case the external power must be suitable for the motor and stepper controller. The barrel jack power should be at least seven (8) volts to power the node or fifteen (15) volts if using the node to inject power to LCC. Amperage should be sufficient to drive any external devices plus about half an amp for the node plus another 1.5 amps if injecting power to LCC.

Node power configuration is accomplished with five jumpers located behind the LCC ports.

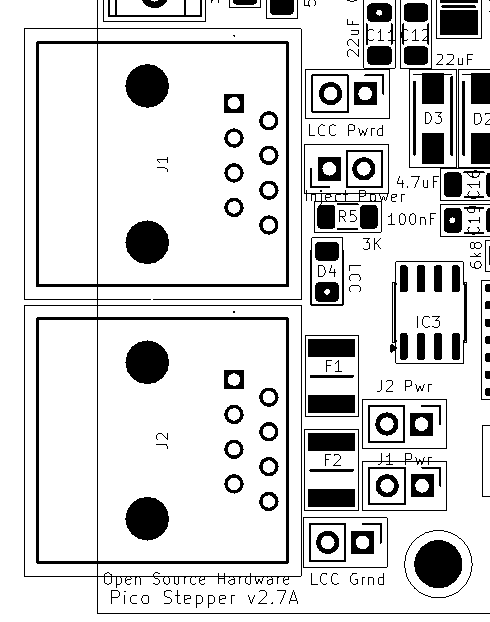
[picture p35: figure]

Inject Power should be bridged along with the LCC Grnd jumper if the node is intended to inject power to one or both of the LCC ports. 15 volts of at least 1.5 amps should be applied to the barrel jack in order to inject power.

J1 Pwr and J2 Pwr jumpers allow power isolation of one or both LCC ports. Generally, both jumpers would be bridged. If power injection or utilization was only desired in one direction, then the opposing jumper would be opened to isolate that leg. The isolated leg should be powered downstream as opening the jumper will cut off any power from the node.

LCC Pwrd jumper should be bridged along with the LCC Grnd jumper if the node is to be powered from the LCC Port. Note that this will not provide power to the stepper driver which is powered exclusively from the barrel jack.

LCC Grnd jumper should be bridged if the node is intended to inject power to or draw power from one or both of the LCC ports.

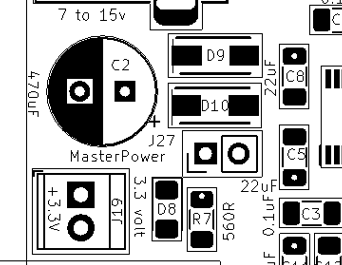
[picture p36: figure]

Master Power jumper should be bridged to power the node. A normally closed button may be wired to this jumper to create a master power reset.

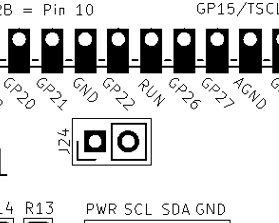
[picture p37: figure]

Jumper 24 is in parallel with the reset button and may be used to wire to a normally open button as a remote Pico reset.

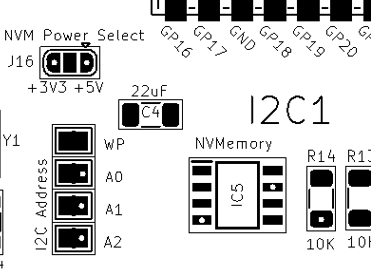
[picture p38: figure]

I2C nonvolatile memory may be populated if desired to reduce strain on the Pico flash. Parts compatible with these should work.

BR24G512F-3AGTE2 I2C BUS(2-Wre) 512K

MB85RC256VPF-G-BCERE1 256kbit FRAM with I2

The power applied to the I2C nonvolatile memory may be selected by bridging the power selection jumper.

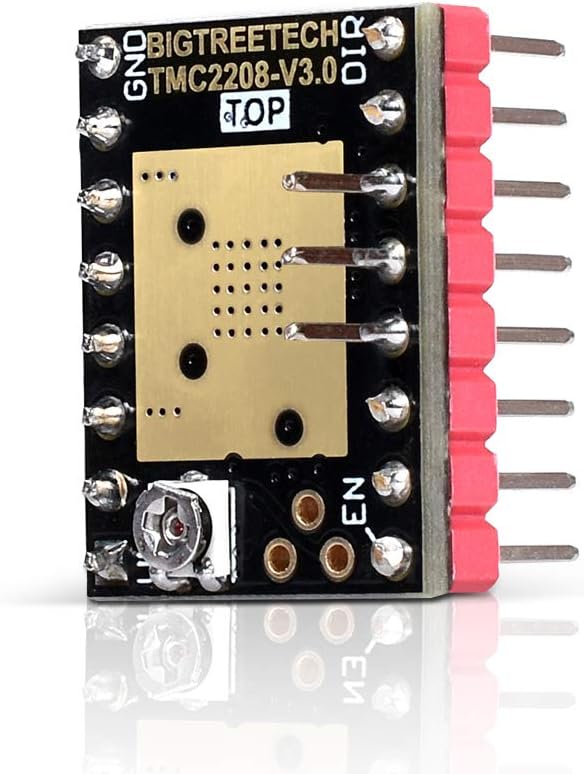
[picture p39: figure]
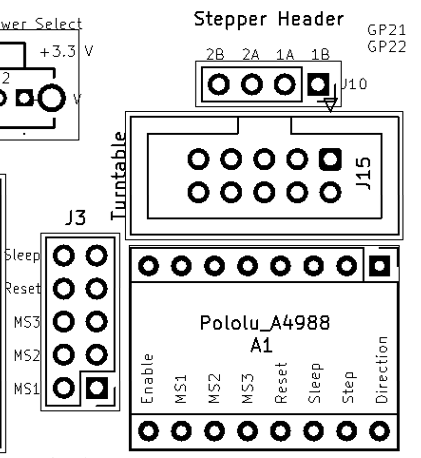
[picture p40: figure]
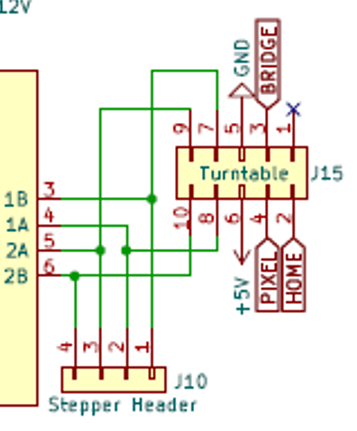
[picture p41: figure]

The stepper motor driver, if populated, can be configured with these jumpers. Bigtreetech TMC2208 V3.0 UART Stepper with Heat Sink has worked well for me as a replacement for a A4988

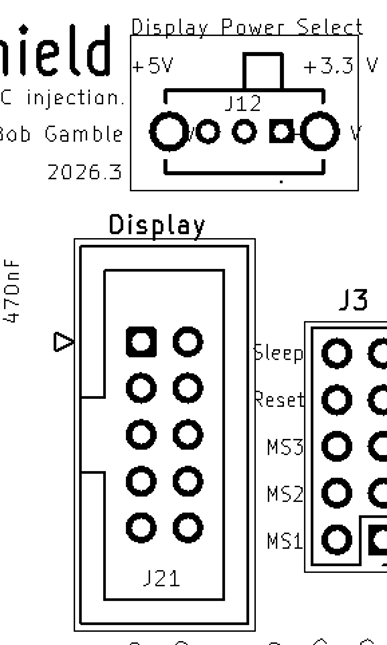
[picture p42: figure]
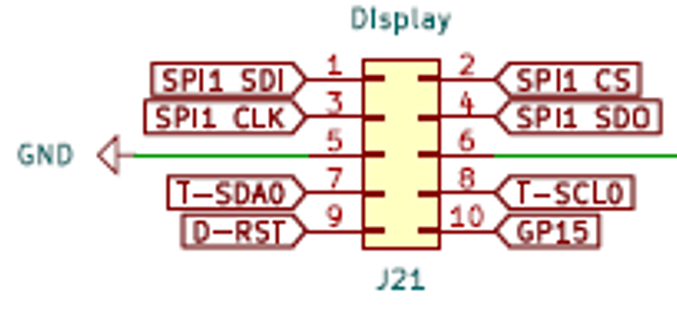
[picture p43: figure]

The voltage for pin 6 of the IDC connector may be selected to be either 3.3 or 5 volts.

The pinout of the connector is as below.

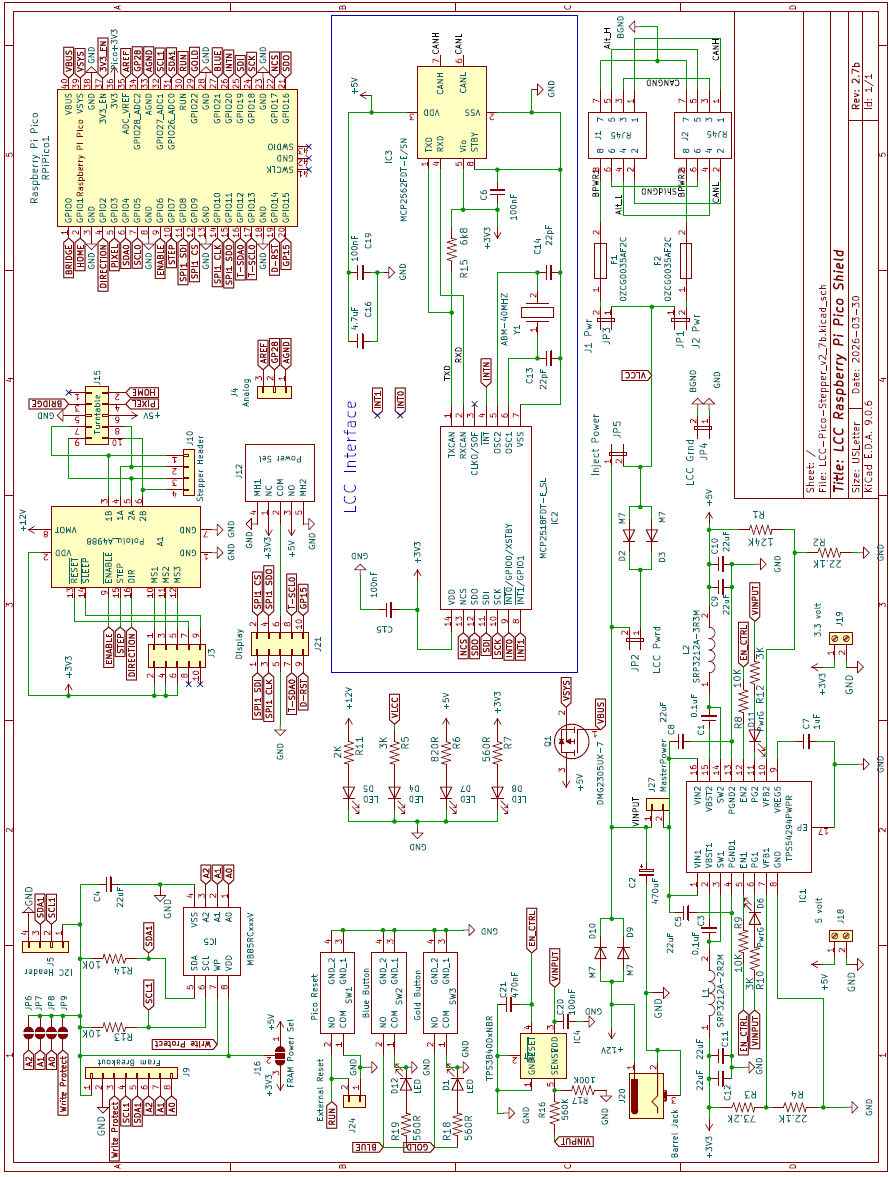
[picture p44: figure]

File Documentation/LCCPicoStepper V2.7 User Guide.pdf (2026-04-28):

# LCC Pico Turntable Node User Guide

### Version 2.7

This version ulizes the MCP2815 and MCP2562 discrete components for the LCC interface.
The intent of this node is to control all aspects of a turntable on a model railroad layout. It can also produce events to control other LCC acons such as servo acvated roundhouse doors or lighng. It may also be adapted to several other uses by connecng to exposed pins on the Raspberry Pi Pico microcontroller.

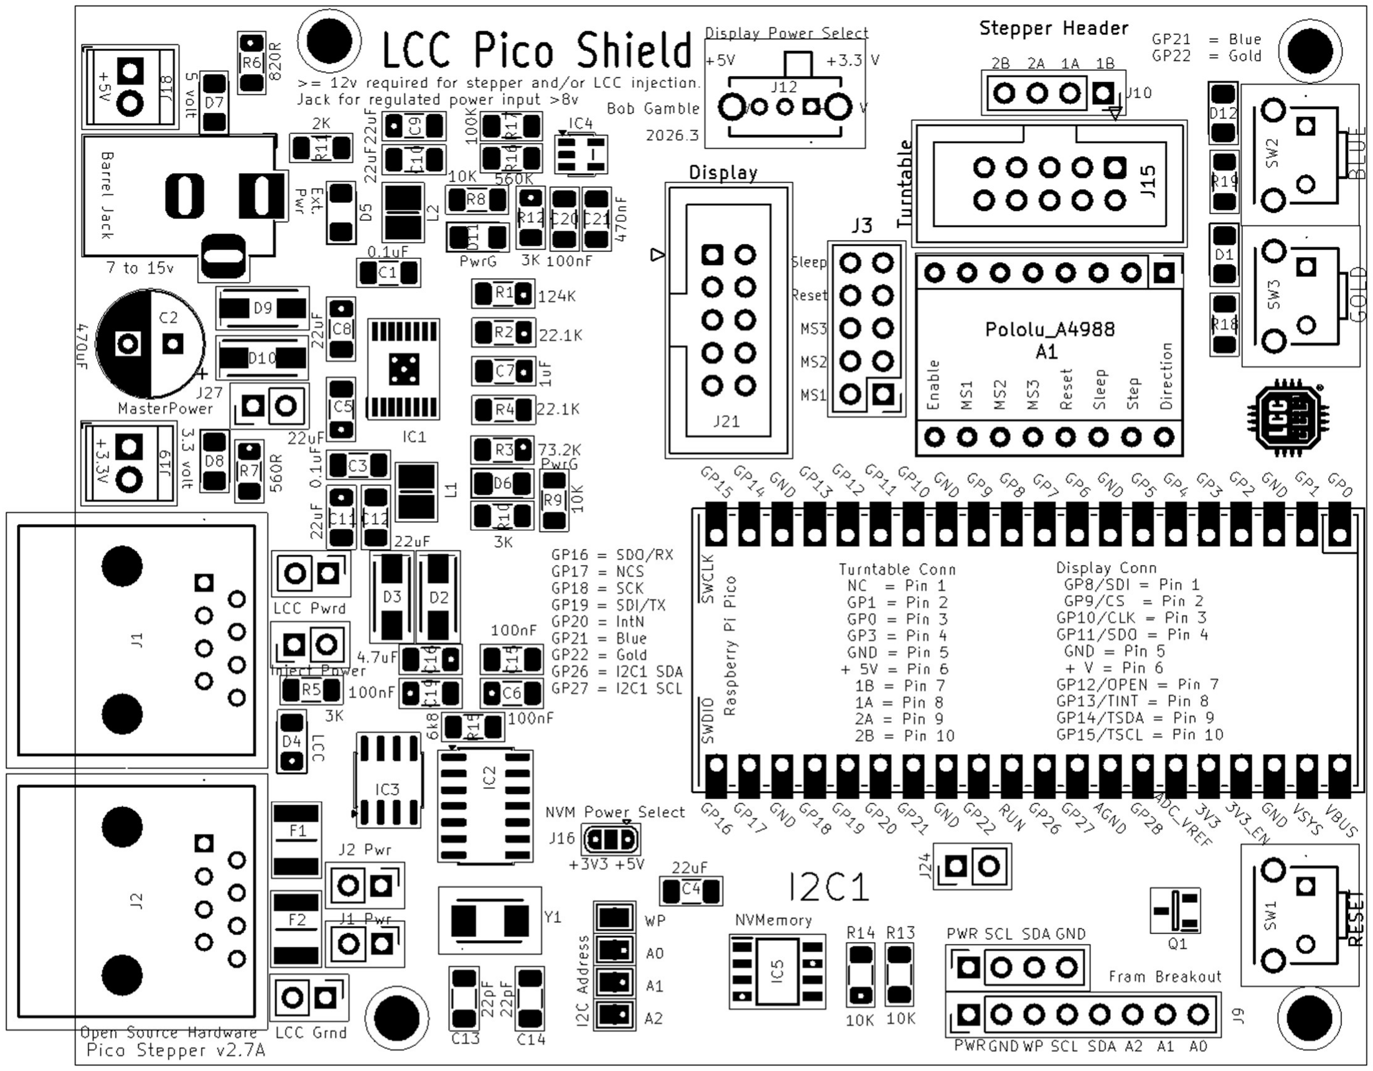
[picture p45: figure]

The node may be powered from the barrel jack or the LCC port. If driving a stepper motor power must be applied from the barrel jack. In this case the external power must be suitable for the motor and stepper controller. The barrel jack power should be at least seven (8) volts to power the node or fieen (15) volts if using the node to inject power to LCC. Amperage should be sufficient to drive any external devices plus about half an amp for the node plus another 1.5 amps if injecng power to LCC.

Node power configuraon is accomplished with five jumpers located behind the LCC ports.

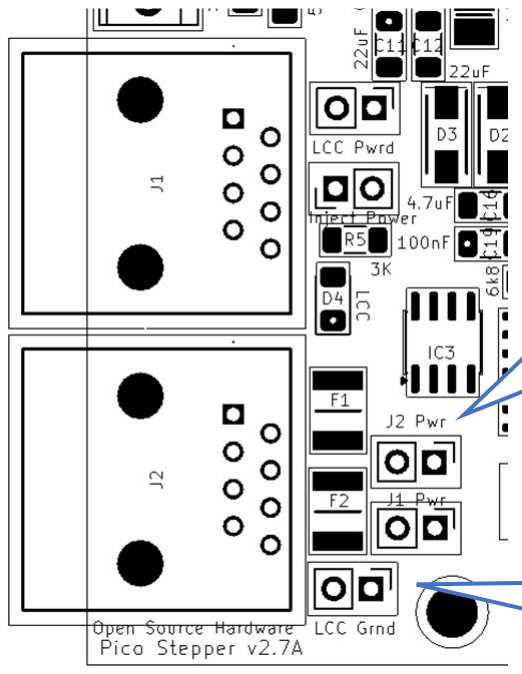
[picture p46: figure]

J1 Pwr and J2 Pwr jumpers allow power isolaon of one or both LCC ports. Generally, both jumpers would be bridged. If power injecon or ulizaon was only desired in one direcon, then the opposing jumper would be opened to isolate that leg. The isolated leg should be powered downstream as opening the jumper will cut off any power from the node.

LCC Pwrd jumper should be bridged along with the LCC Grnd jumper if the node is to be powered from the LCC Port. Note that this will not provide power to the stepper driver which is powered exclusively from the barrel jack.

Inject Power should be bridged along with the LCC Grnd jumper if the node is intended to inject power to one or both of the LCC ports. 15 volts of at least 1.5 amps should be applied to the barrel jack in order to inject power.

LCC Grnd jumper should be bridged if the node is intended to inject power to or draw power from one or both of the LCC ports.

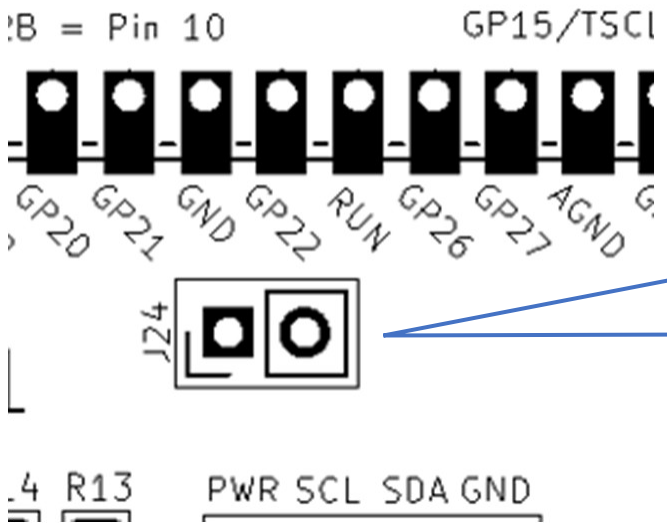
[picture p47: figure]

Jumper 24 is in parallel with the reset buon and may be used to wire to a normally open buon as a remote Pico reset.

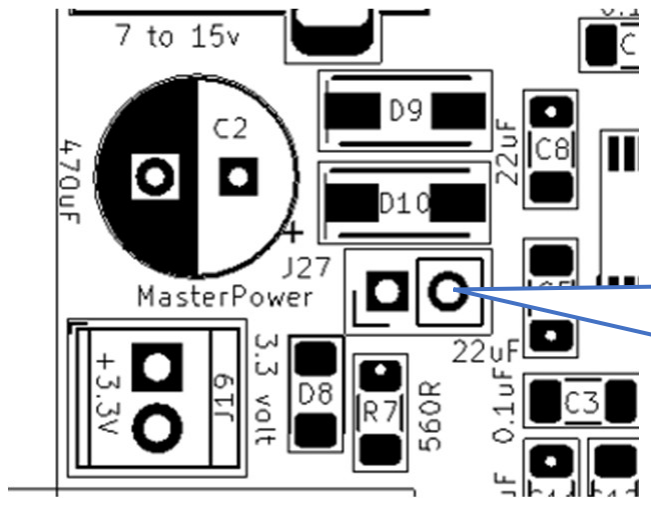
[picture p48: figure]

Master Power jumper should be bridged to power the node. A normally closed buon may be wired to this jumper to create a master power reset.

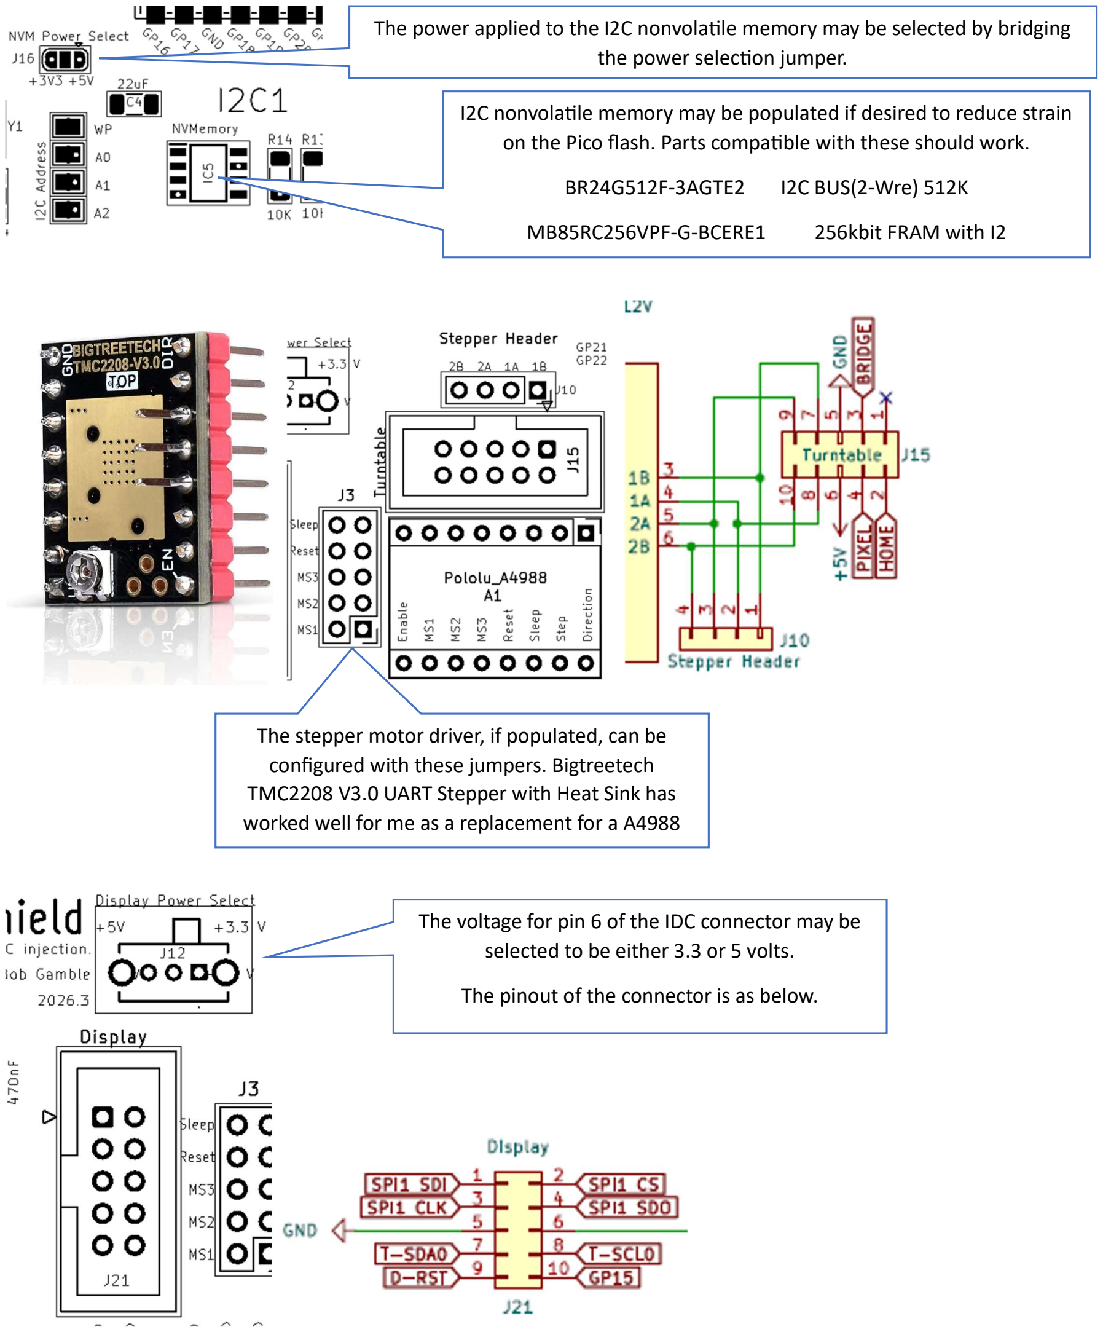
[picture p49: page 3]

The power applied to the I2C nonvolale memory may be selected by bridging the power selecon jumper.

I2C nonvolale memory may be populated if desired to reduce strain on the Pico flash. Parts compable with these should work.
BR24G512F-3AGTE2 | I2C BUS(2-Wre) 512K
MB85RC256VPF-G-BCERE1 | 256kbit FRAM with I2

The stepper motor driver, if populated, can be configured with these jumpers. Bigtreetech TMC2208 V3.0 UART Stepper with Heat Sink has worked well for me as a replacement for a A4988

The voltage for pin 6 of the IDC connector may be selected to be either 3.3 or 5 volts.
The pinout of the connector is as below.

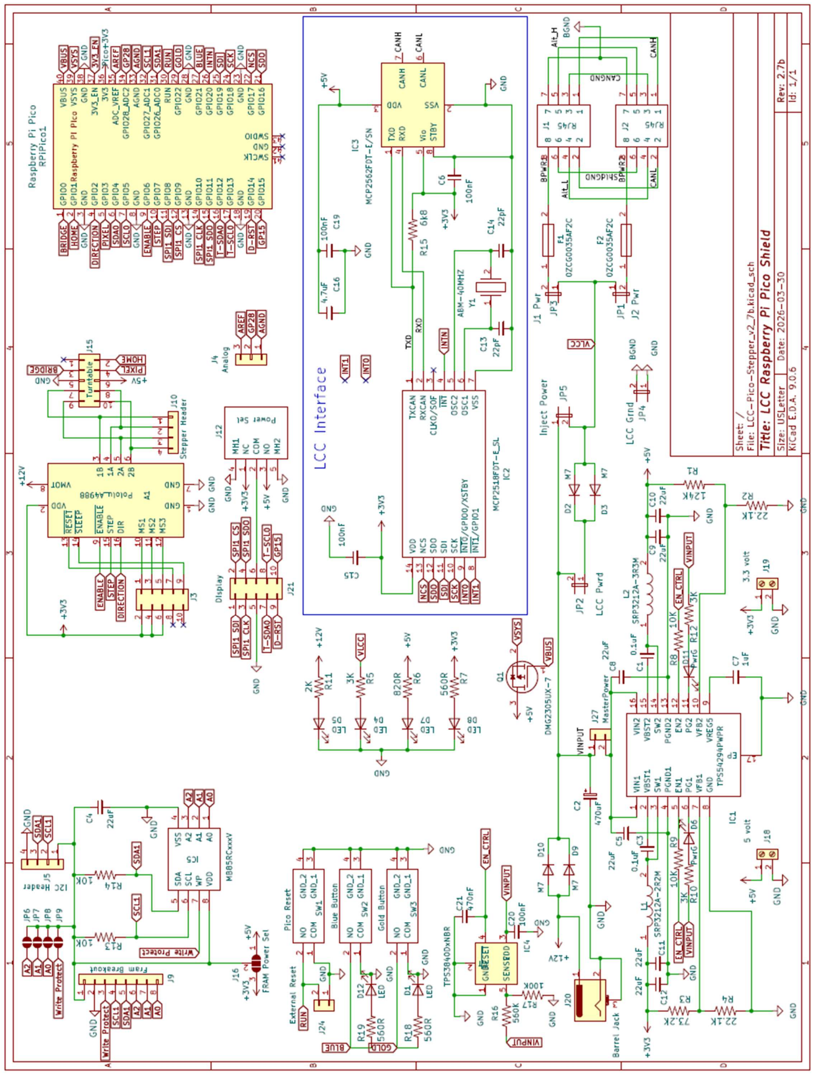
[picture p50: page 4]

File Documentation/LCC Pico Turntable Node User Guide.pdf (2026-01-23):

# LCC Pico Turntable Node User Guide

### Version 2.4

This version ulizes the MCP2815 and MCP2562 discrete components for the LCC interface.
The intent of this node is to control all aspects of a turntable & roundhouse engine facility on a model railroad layout. It may also be adapted to several other uses as there is facility to connect to all the exposed pins on the Raspberry Pi Pico microcontroller. Some pins have power and ground pins in line to facilitate peripheral connecons.
Note that the resistor in line with the reset buon has been changed to zero ohm from the 10K shown. There are no resistors on the Blue and Gold buon lines.

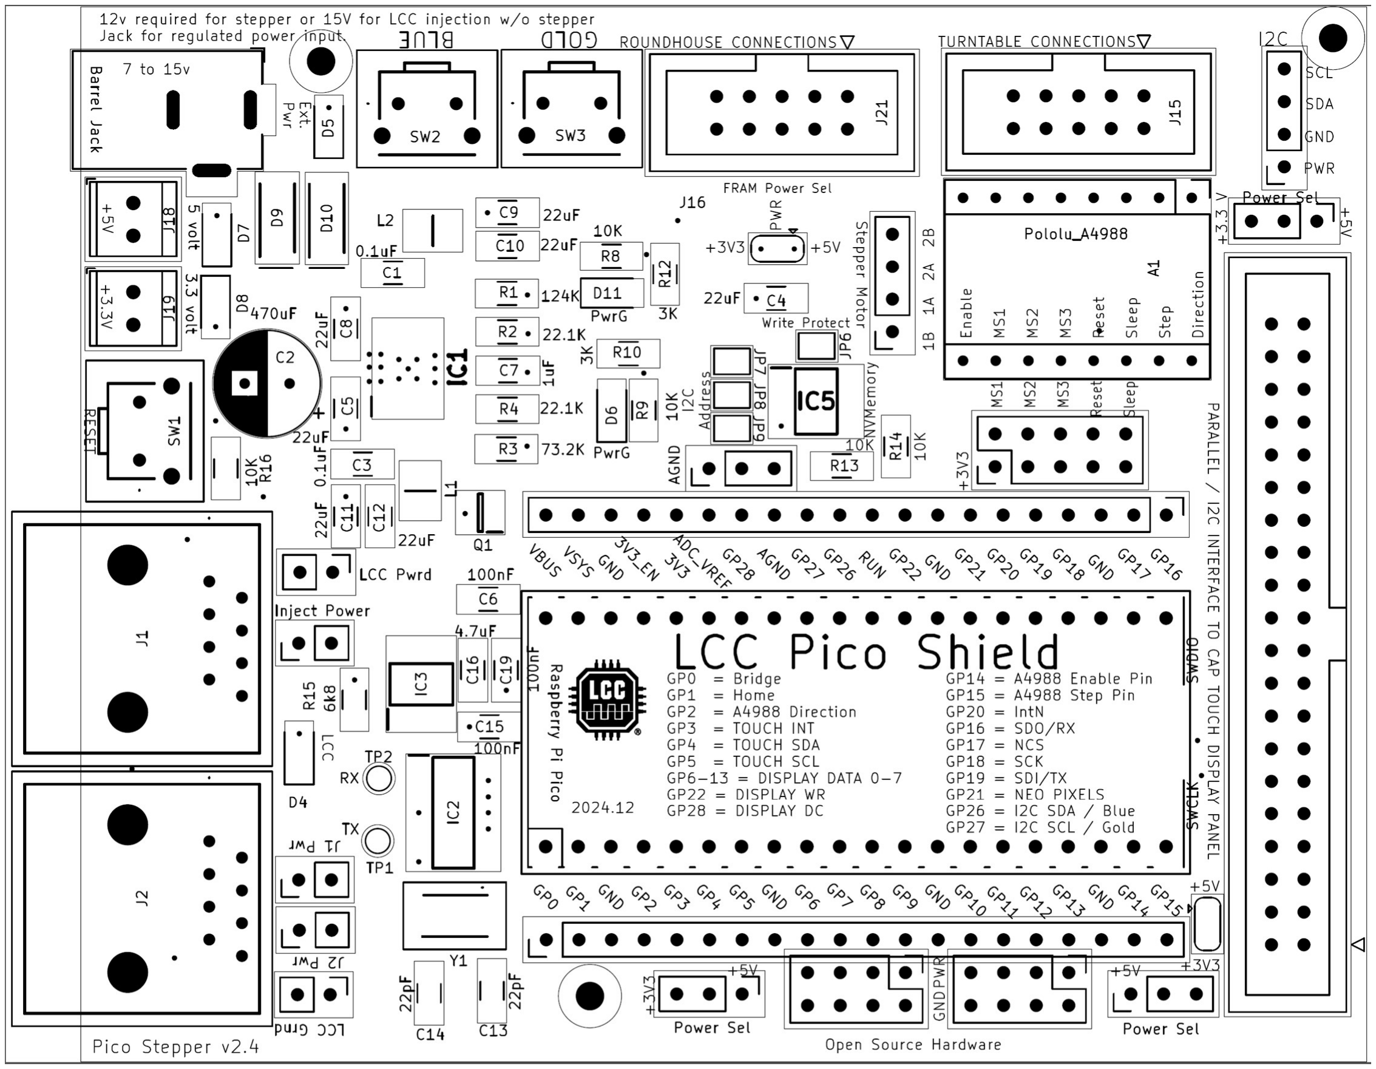
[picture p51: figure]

The node may be powered from the barrel jack or the LCC port. If driving a stepper motor power must be applied from the barrel jack. In this case the external power must be suitable for the motor and stepper controller. The barrel jack power should be at least seven (7) volts to power the node or fieen (15) volts if using the node to inject power to LCC. Amperage should be sufficient to drive any external devices plus about half an amp for the node plus another 1.5 amps if injecng power to LCC.

Node power configuraon is accomplished with five jumpers located behind the LCC ports.

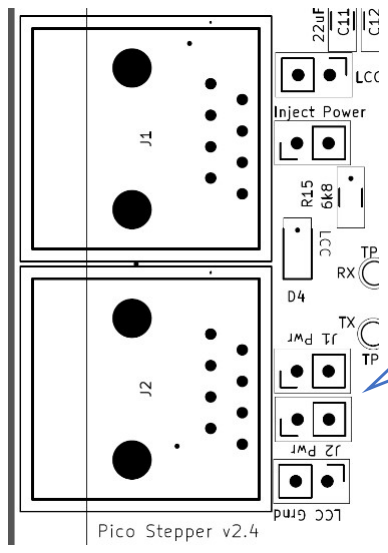
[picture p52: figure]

J1 Pwr and J2 Pwr jumpers allow power isolaon of one or both LCC ports. Generally, both jumpers would be bridged. If power injecon or ulizaon was only desired in one direcon, then the opposing jumper would be opened to isolate that leg. The isolated leg should be powered downstream as opening the jumper will cut off any power from the node.

LCC Pwrd jumper should be bridged along with the LCC Grnd jumper if the node is to be powered from the LCC Port. Note that this will not provide power to the stepper driver which is powered exclusively from the barrel jack.

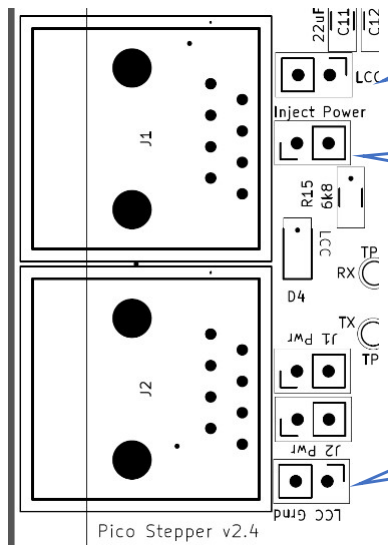
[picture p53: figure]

Inject Power should be bridged along with the LCC Grnd jumper if the node is intended to inject power to one or both of the LCC ports. 15 volts of at least 1.5 amps should be applied to the barrel jack in order to inject power.

LCC Grnd jumper should be bridged if the node is intended to inject power to or draw power from one or both of the LCC ports.

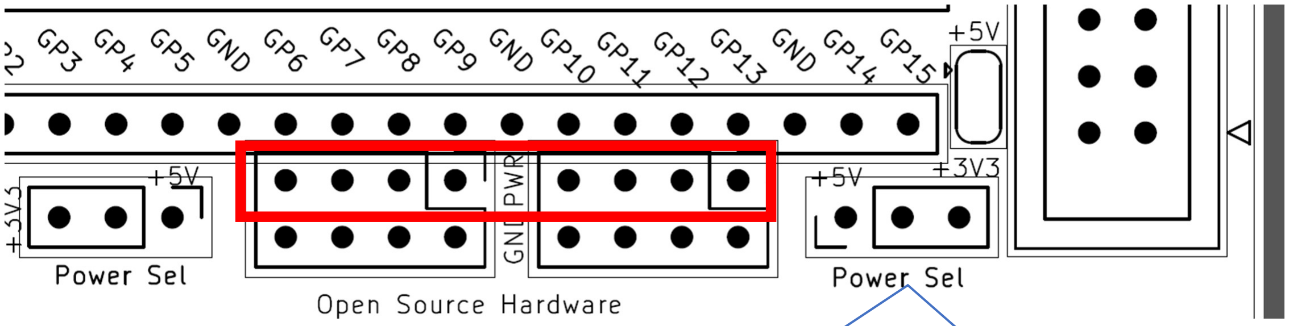
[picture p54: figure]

The power applied to the middle pins of the GPIO blocks of four may be selected by bridging the respecve power selecon jumpers.

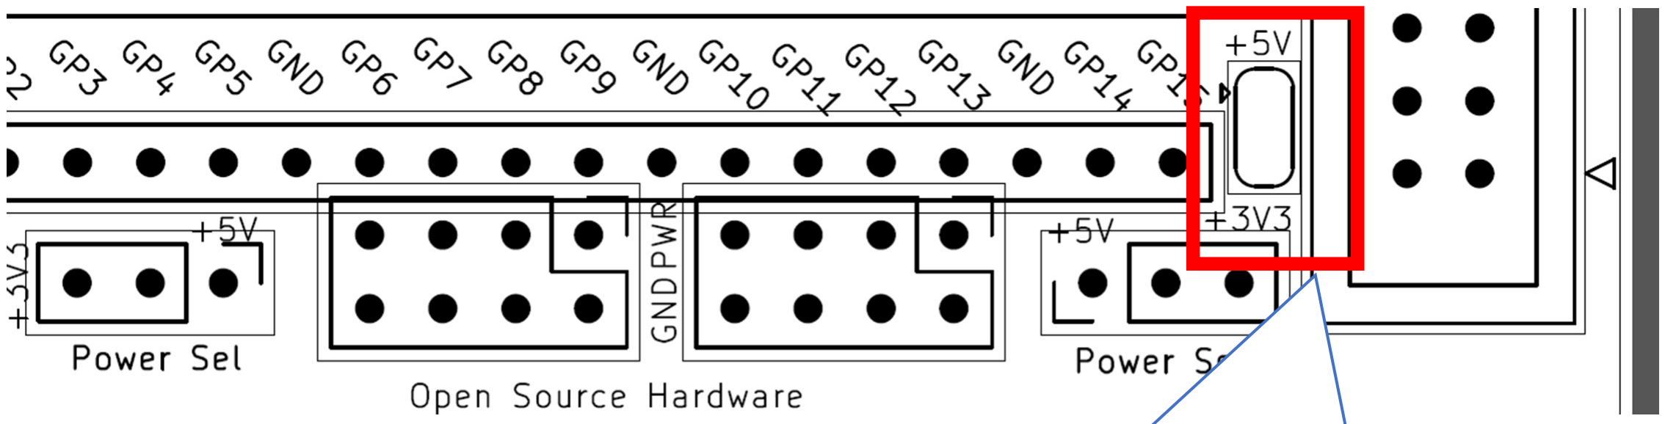
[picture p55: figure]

The power applied to the 40 pin display connector may be selected by bridging the respecve power selecon jumper.

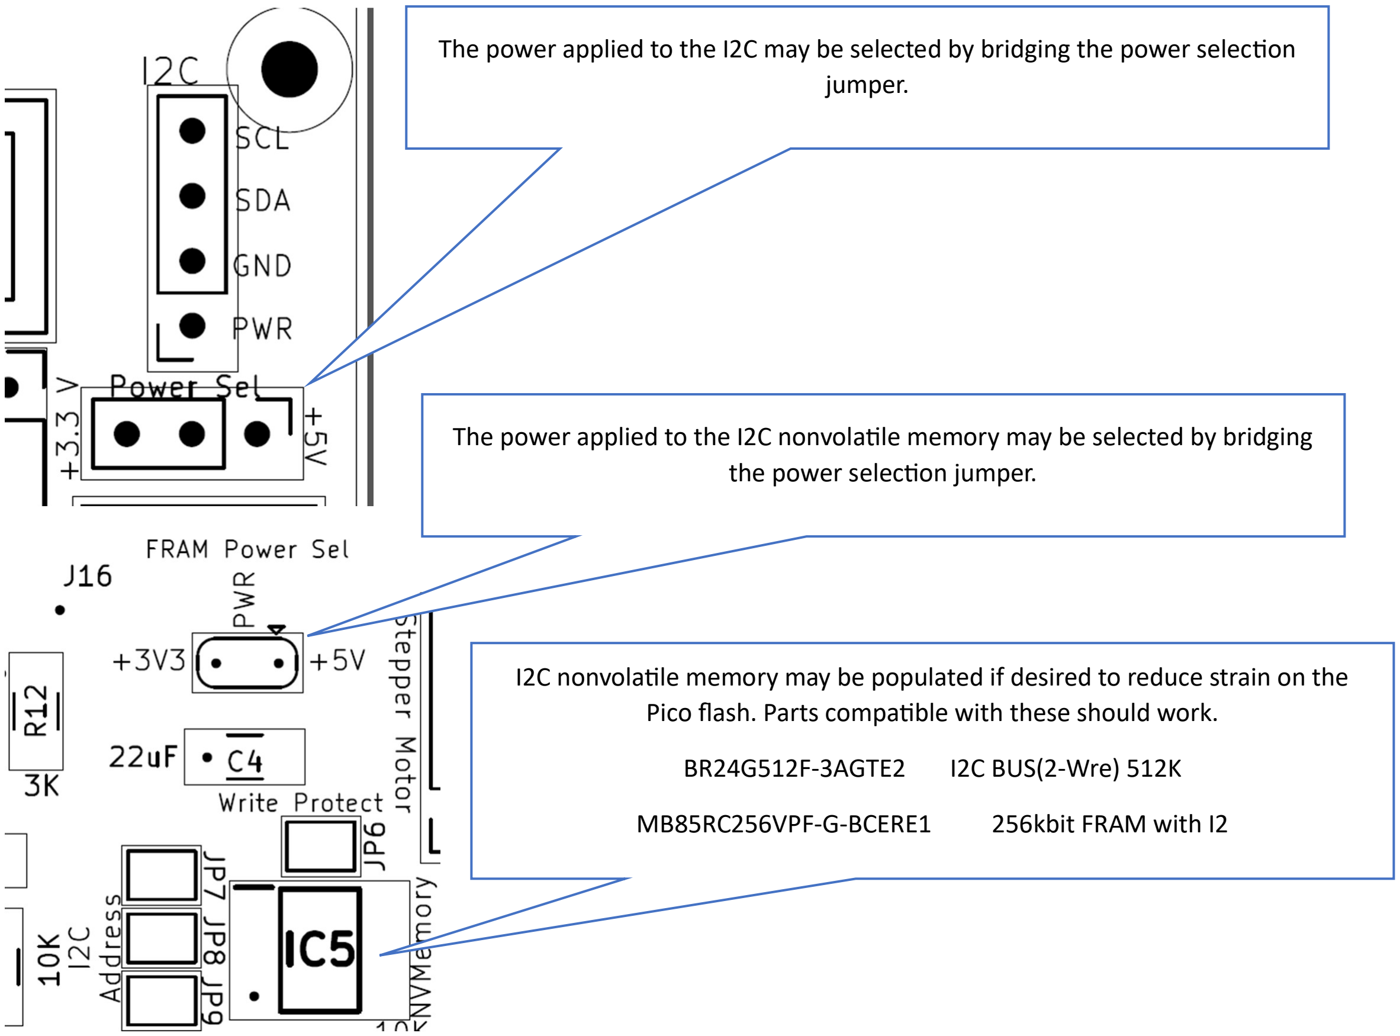
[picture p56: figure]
jumper.; the power selecon jumper.; BR24G512F-3AGTE2; I2C BUS(2-Wre) 512K; MB85RC256VPF-G-BCERE1; 256kbit FRAM with I2

The power applied to the I2C may be selected by bridging the power selecon

The power applied to the I2C nonvolale memory may be selected by bridging

I2C nonvolale memory may be populated if desired to reduce strain on the Pico flash. Parts compable with these should work.

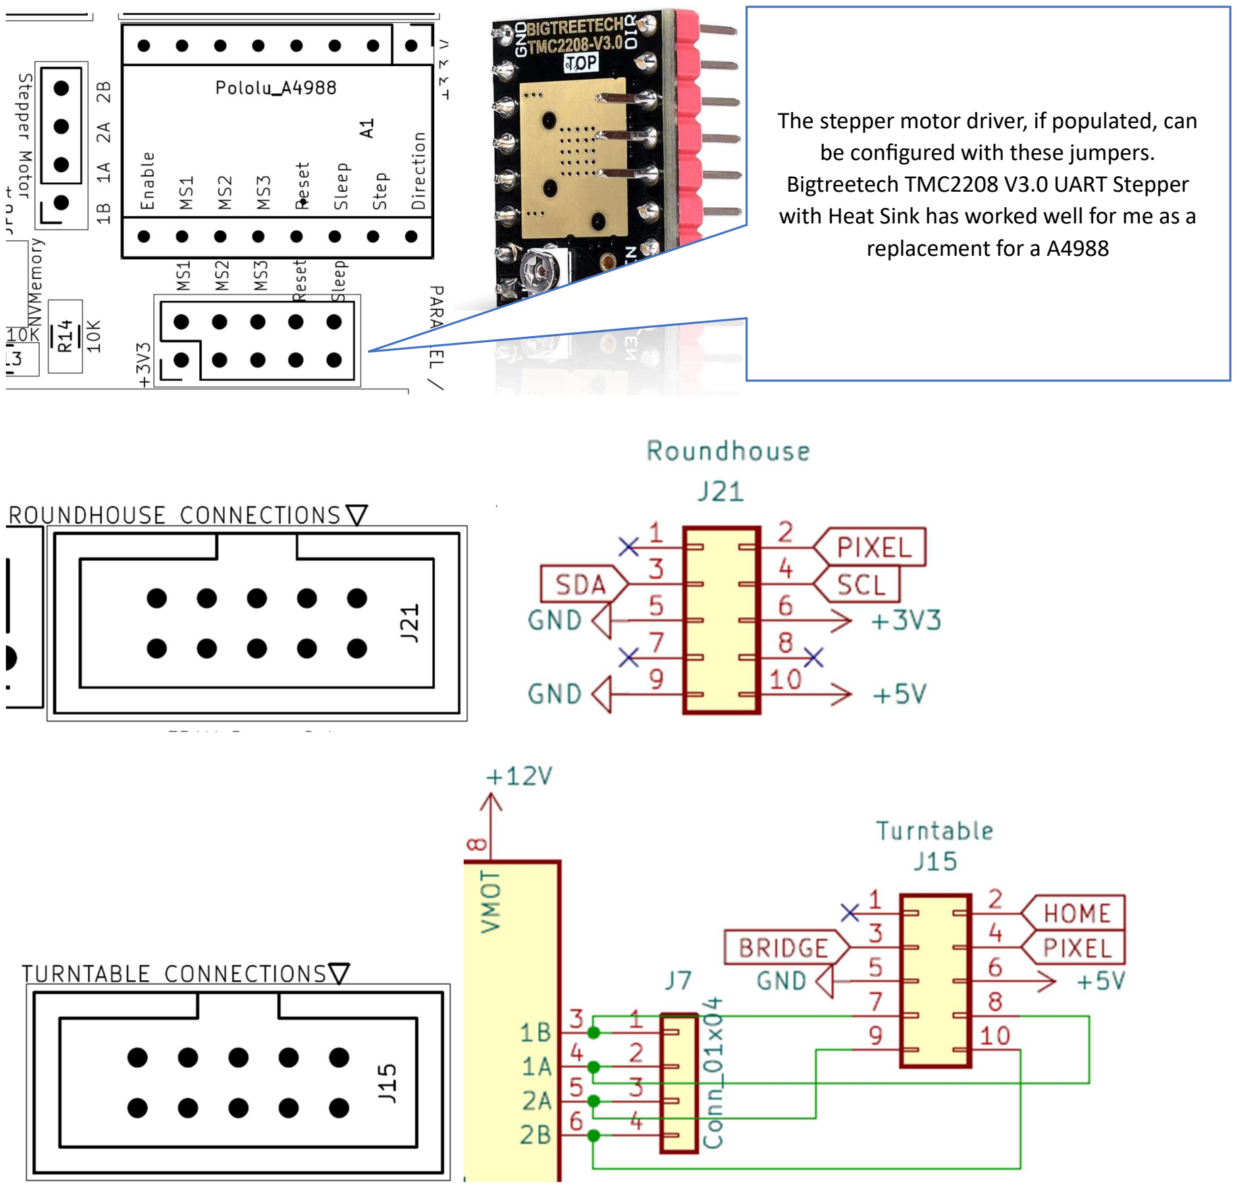
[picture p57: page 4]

The stepper motor driver, if populated, can be configured with these jumpers. Bigtreetech TMC2208 V3.0 UART Stepper with Heat Sink has worked well for me as a replacement for a A4988

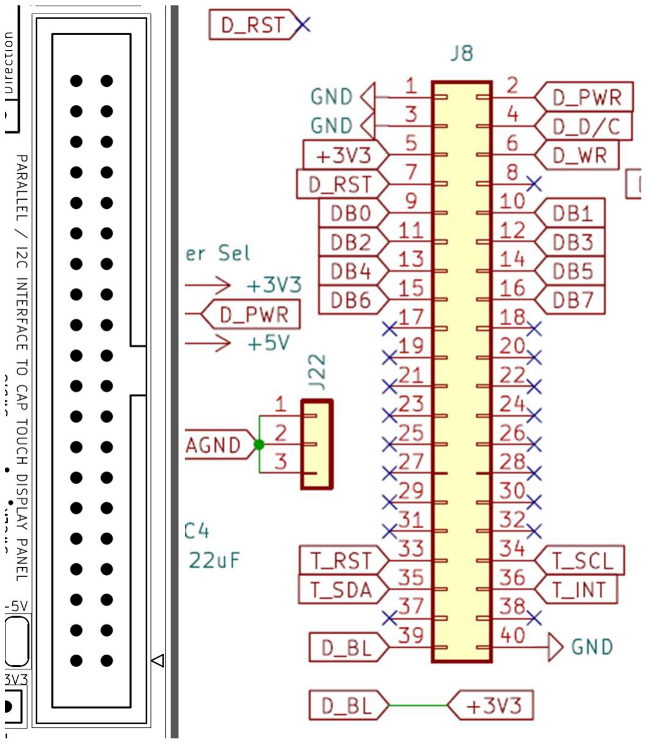
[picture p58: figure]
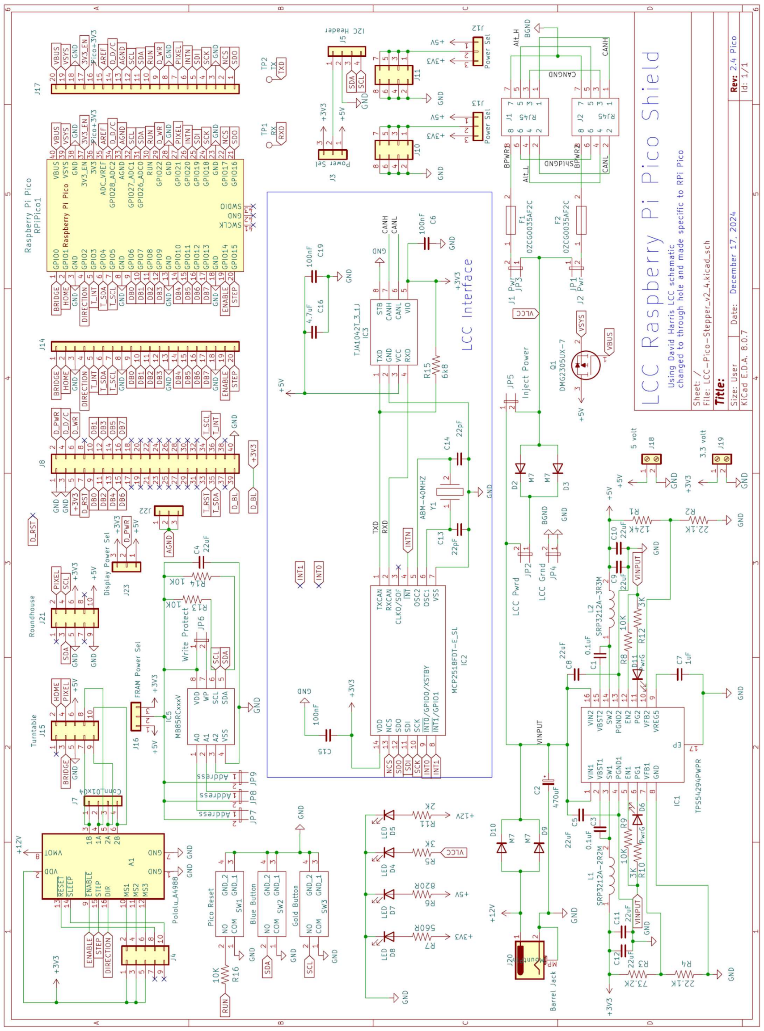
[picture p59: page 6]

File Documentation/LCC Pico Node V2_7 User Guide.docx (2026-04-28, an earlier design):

# LCC Pico Node User Guide

Version 2.7

This version utilizes the MCP2815 and MCP2562 discrete hardware components (chips) for the LCC interface.

The intent of this node is to control 16 pins on two 10 pin IDC connectors for a model railroad layout. While it will work with either the Pico or Pico2, the latter is recommended due to enhanced capabilities.

There are no resistors on the Reset, Blue, and Gold button lines.

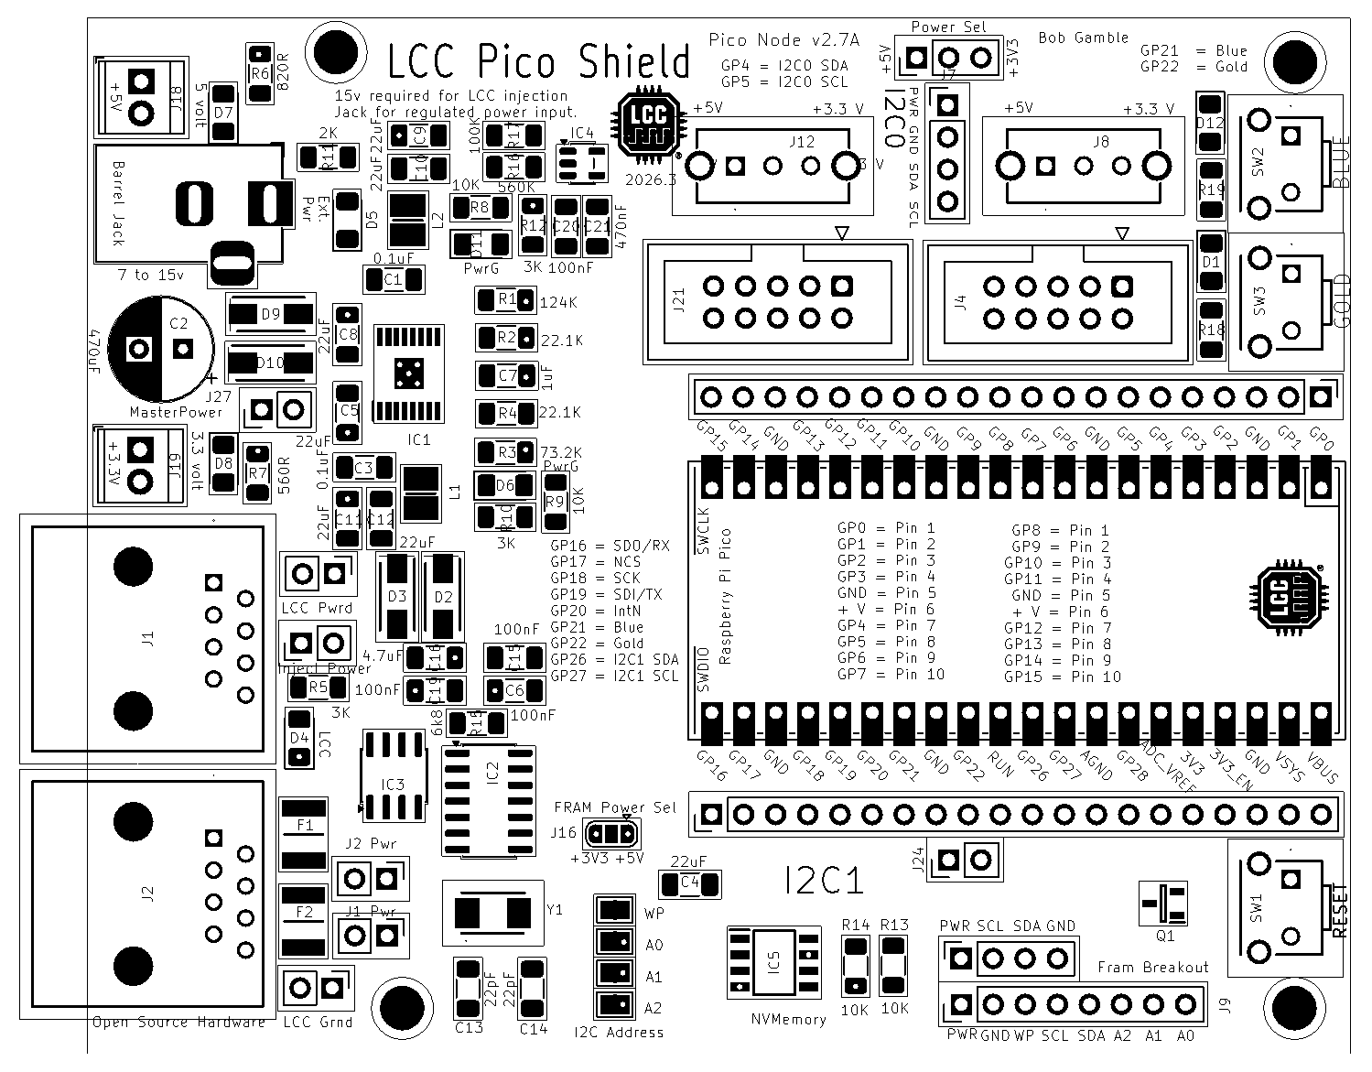
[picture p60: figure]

The node may be powered from the barrel jack or the LCC port. The barrel jack power should be at least seven (8) volts to power the microcontroller or fifteen (15) volts [or your preferred LCC voltage] if using the node to inject power to LCC. Amperage should be sufficient to drive any external devices plus about half an amp for the node plus another 1.5 amps if injecting power to LCC. There are six power LEDs. Five should be lit to indicate that the node is properly powered, six if barrel jack powered.

Node power configuration is accomplished with five jumpers located behind the LCC ports.

Master Power jumper should be bridged to power the node. A normally closed button may be plugged in here as a means to do a hardware reset should there be a problem with the power initialization due to a slow ramping power supply.

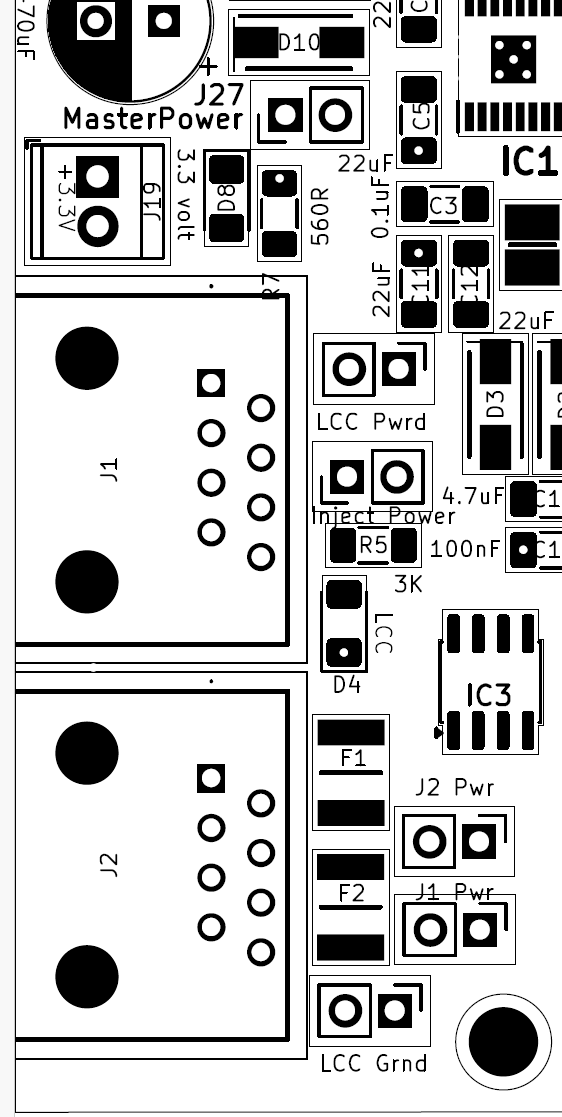
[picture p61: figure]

LCC Pwrd jumper should be bridged along with the LCC Grnd jumper if the node is to be powered from the LCC Port. Note that this will not provide power to the stepper driver which is powered exclusively from the barrel jack.

Inject Power should be bridged along with the LCC Grnd jumper if the node is intended to inject power to one or both of the LCC ports. 15 volts of at least 1.5 amps should be applied to the barrel jack in order to inject power.

J1 Pwr and J2 Pwr jumpers allow power isolation of one or both LCC ports. Generally, both jumpers would be bridged. If power injection or utilization was only desired in one direction, then the opposing jumper would be opened to isolate that leg. The isolated leg should be powered downstream as opening the jumper will cut off any power from the node.

LCC Grnd jumper should be bridged if the node is intended to inject power to or draw power from one or both of the LCC ports.

J24 jumper may be attached to a normally open button to function as a Reset as it is in parallel to the on board Reset button.

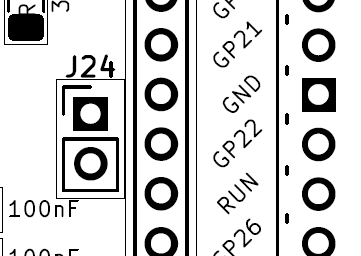
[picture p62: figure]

The power applied to the middle pins of the IDC connectors may be selected by the respective power selection switches. Pin assignments are noted on the PCB.

The power applied to the I2C may be selected by bridging the power selection jumper.

A similar jumper is adjacent to the I2C1 header.

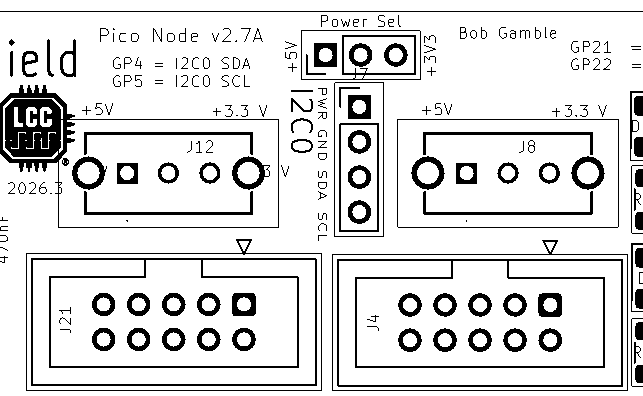
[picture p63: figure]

# NVM Storage

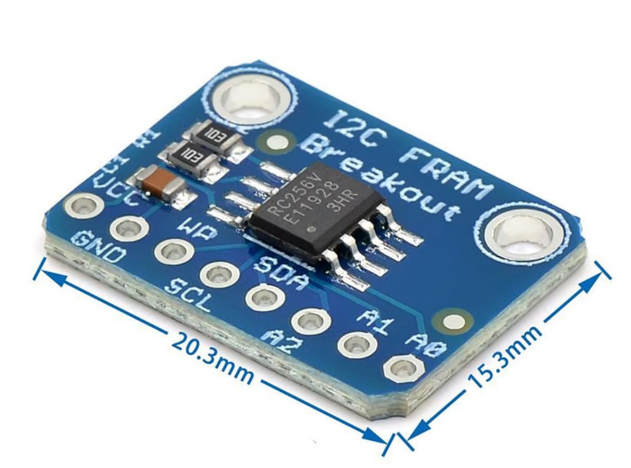
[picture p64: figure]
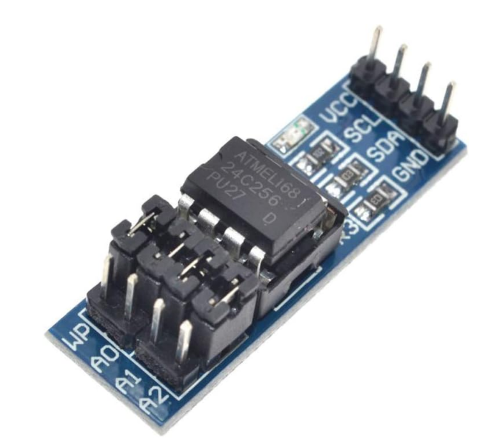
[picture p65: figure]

External NVM may be attached to either the I2C1 header, the FRAM Breakout header, or soldered down to the IC5 footprint. If either of the latter two choices are used, the I2C Address jumpers may be used to select non-default addresses or implement write protection. Otherwise, these would be functions of the module plugged into the I2C1 header.

A typical part would be a module utilizing an AT25C256 chip (left) or RC256V FRAM (right).

Either 3.3V or 5V may be selected by this solder jumper. The selection will apply to the soldered NVM module or FRAM Breakout header

I2C modules including NVM may be attached to this header. Either 3.3V or 5V may be selected by the adjacent jumpers.


I2C nonvolatile memory may be populated if desired to reduce strain on the Pico flash. Parts compatible with these should work.

BR24G512F-3AGTE2 I2C BUS(2-Wre) 512K

MB85RC256VPF-G-BCERE1 256kbit FRAM with I2C

I2C address may be selected by the lower three pairs of headers. The selection will apply to the soldered NVM module or FRAM Breakout header

An Adafruit FRAM breakout board may be attached to this header.


# Bill of Materials

Qty | Value | Reference | Mfr. # | Description
6 | 0.1uF, 100nF | C1,C3,C6,C15,C19,C20 | C1206C104K3RAC7411 | Multilayer Ceramic Capacitors MLCC - SMD/SMT 25V 0.1uF X7R 1206 10%
1 | 470uF | C2 | REF1016471M035K | Aluminum Electrolytic Capacitors - Radial Leaded Radial Leaded Aluminum Electrolytic Capacitor
7 | 22uF | C4,C5,C8,C9,C10,C11,C12 | CL31A226MOCLNNC | Multilayer Ceramic Capacitors MLCC - SMD/SMT 22uF+/-20% 16V X5R 3 1206
1 | 1uF | C7 | CL31B105KAHNFNE | Multilayer Ceramic Capacitors MLCC - SMD/SMT 1uF+/-10% 25V X7R 32 1206
2 | 22pF | C13,C14 | C1206C220J3HACTU | Multilayer Ceramic Capacitors MLCC - SMD/SMT 25V 22pF X8R 1206 5%
1 | 4.7uF | C16 | CL31B475KOHNFNE | Multilayer Ceramic Capacitors MLCC - SMD/SMT 4.7uF+/-10% 16V X7R 1206
1 | 470nF | C21
6 | LED | D1,D4,D5,D7,D8,D12 | 156120VS75000 | Single Color LEDs WL-SMRW SMD RvMt Mon Wtrclr Rect 1206BtGn
4 | M7 | D2,D3,D9,D10 | M7 | Rectifiers Diode, SMA, 1000V, 1A
2 | PwrG | D6,D11 | 156120VS75000 | Single Color LEDs WL-SMRW SMD RvMt Mon Wtrclr Rect 1206BtGn
2 | 0ZCG0035AF2C | F1,F2 | 0ZCG0035AF2C | Resettable Fuses - PPTC
1 | TPS54294PWPR | IC1 | TPS54294PWPR | Switching Voltage Regulators 4.5-18Vin Dual 2A Ou t Sync SD Cnvrtr A A 595-TPS54294PWP
1 | MCP2518FDT-E_SL | IC2 | MCP2518FDT-E/SL | CAN Interface IC Stand-alone Low Power CAN FD Controller w/SPI Interface Grade1
1 | MCP2562FDT-E/SN | IC3 | MCP2562FDT-E/SN | CAN Interface IC CAN Flexible Data Rate Transceiver
1 | TPS3840DxNBR | IC4
1 | MB85RCxxxV | IC5 | BR24G512F-3AGTE2 | EEPROM I2C BUS(2-Wre) 512K SOP8 EEPROM
2 | RJ45 | J1,J2 | MTJ-880X1 | Modular Connectors / Ethernet Connectors 8P8C TYPE 0 GLD FLSH BLK
1 | SRP3212A-2R2M | L1 | SRP3212A-2R2M | Power Inductors - SMD Ind,3.2x2.5x1mm,2.2uH+/-20%,4A, shd AEC-Q200
1 | SRP3212A-3R3M | L2 | SRP3212A-3R3M | Power Inductors - SMD Ind,3.2x2.5x1mm,3.3uH+/-20%,3.1A, shd AEC-Q200
1 | DMG2305UX-7 | Q1 | DMG2305UX-7 | MOSFETs P-Ch ENH FET -20V 52mOh -5A
1 | 124K | R1 | ERA-8AEB1243V | Thin Film Resistors - SMD 1206 124Kohm 25ppm 0.1% AEC-Q200
2 | 22.1K | R2,R4 | ERA-8AEB2212V | Thin Film Resistors - SMD 1206 22.1Kohm 25ppm 0.1% AEC-Q200
1 | 73.2K | R3 | ERA-8AEB7322V | Thin Film Resistors - SMD 1206 73.2Kohm 25ppm 0.1% AEC-Q200
3 | 3K | R5,R10,R12
1 | 820R | R6 | RT1206FRE07820RL | Thin Film Resistors - SMD 1/4W 820 ohm 1% 50ppm
3 | 560R | R7,R18,R19 | RT1206FRE07560RL | Thin Film Resistors - SMD 560 OHM 1% 50PPM 1/4W
4 | 10K | R8,R9,R13,R14
1 | 2K | R11 | RT1206FRE072KL | Thin Film Resistors - SMD 1/4W 2K ohm 1% 50ppm
1 | 6k8 | R15 | RT1206DRD076K8L | Thin Film Resistors - SMD 6.8 kOhms 250 mW 0.5 % 1206
1 | 560K | R16
1 | 100K | R17
1 | Raspberry Pi Pico | RPiPico1
1 | Pico Reset | SW1 | TS11-674-43-BK-160-RA-D | Tactile Switches 6 x 7.4 mm 4.3 mm 160 gf Black Right Angle Through Hole SPST
1 | Blue Button | SW2 | TS11-674-43-BK-160-RA-D | Tactile Switches 6 x 7.4 mm 4.3 mm 160 gf Black Right Angle Through Hole SPST
1 | Gold Button | SW3 | TS11-674-43-BK-160-RA-D | Tactile Switches 6 x 7.4 mm 4.3 mm 160 gf Black Right Angle Through Hole SPST
1 | ABM-40MHZ | Y1 | ABM3-40.000MHZ-B2-T | Crystals Xtal 5032 2-SMD 40MHz Tol +/-20ppm Stab +/-50ppm -20C - 70C 18pF 25 Ohms

### Connections:

J6,J8,J12 | 3.3/5 Volt Power Selection
J5,J7 | I2C Header
J9 | Fram Breakout header
J4, J21 | 10 pin IDC connector I/O
J14,J17 | Pico Pinout Conn_01x20
J16 | FRAM Power Select
J18 | 5 volt power out
J19 | 3.3 volt power out
J20 | Barrel Jack power input
J24 | External Reset header
J27 | MasterPower bridge header
JP1 | J2 LCC Power enable
JP2 | Power from LCC enable
JP3 | J1 LCC Power enable
JP4 | LCC Ground enable
JP5 | Inject Power to LCC enable
JP6-9 | NVM Address & WP

# Software

### Board:

The author uses the RP2040 board library by Earle Philhower

https://arduino-pico.readthedocs.io/en/latest/install.html

### For LCC support:

https://github.com/openlcb/OpenLCB_Single_Thread

Or

https://github.com/JimKueneman/OpenLcbCLib

### CAN Hardware:

ACAN2517 Arduino library.

### External Storage:

I2C_EEPROM Arduino library by Rob Tillaart

FRAM_I2C Arduino library by Rob Tillaart

### NeoPixel:

NeoPixelBus by Makuna Arduino library (preferred)

Or

NeoPixelConnect Arduino library by Alan Yorinks.

### Other preferred libraries for the RPi Pico:

#### Display

#include <TFT_eSPI.h> // Hardware-specific display library

#include "my_bb_captouch.h" //capacitive touch driver

#### Servos

#include <ServoEasing.hpp> // great library for getting slow servo action, including bounces

#include <PCA9685_servo_driver.h>

#include <PCA9685_servo.h>

#### Stepper Motor

#include "AccelStepper.h" // by Mike McCauley

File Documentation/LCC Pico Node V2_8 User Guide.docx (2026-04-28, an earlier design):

# LCC Pico Node User Guide

Version 2.8

This version utilizes the MCP2815 and MCP2562 discrete hardware components (chips) for the LCC interface.

The intent of this node is to control 16 pins on two 10 pin IDC connectors for a model railroad layout. It differs from the 2.7 board by the pin assignments. The higher GPIO pins are used for the second IDC connector making the analog pins usable for node peripherals. While it will work with either the Pico or Pico2, the latter is recommended due to enhanced capabilities.

There are no resistors on the Reset, Blue, and Gold button lines other than for the Blue and Gold LEDs.


The node may be powered from the barrel jack or the LCC port. The barrel jack power should be at least seven (8) volts to power the microcontroller or fifteen (15) volts [or your preferred LCC voltage] if using the node to inject power to LCC. Amperage should be sufficient to drive any external devices plus about half an amp for the node plus another 1.5 amps if injecting power to LCC. There are six power LEDs. Five should be lit to indicate that the node is properly powered, six if barrel jack powered.

Node power configuration is accomplished with five jumpers located behind the LCC ports.

Master Power jumper should be bridged to power the node. A normally closed button may be plugged in here as a means to do a hardware reset should there be a problem with the power initialization due to a slow ramping power supply.


LCC Grnd jumper should be bridged if the node is intended to inject power to or draw power from one or both of the LCC ports.

J1 Pwr and J2 Pwr jumpers allow power isolation of one or both LCC ports. Generally, both jumpers would be bridged. If power injection or utilization was only desired in one direction, then the opposing jumper would be opened to isolate that leg. The isolated leg should be powered downstream as opening the jumper will cut off any power from the node.

LCC Pwrd jumper should be selected along with the LCC Grnd jumper if the node is to be powered from the LCC Port. Note that this will not provide power to the stepper driver which is powered exclusively from the barrel jack.

Inject Power should be selected along with the LCC Grnd jumper if the node is intended to inject power to one or both of the LCC ports. 15 volts of at least 1.5 amps should be applied to the barrel jack in order to inject power.

J24 jumper may be attached to a normally open button to function as a Reset as it is in parallel to the on board Reset button.


The power applied to the middle pins of the IDC connector may be selected by the power selection switch. Pin assignments are noted on the PCB.


The alternate power selection between +5V and Aref. Use ARef if you want to use ADC0-2 pins.

The power applied to the middle pins of the IDC connector may be selected by the power selection switch and the solder jumper. Pin assignments are noted on the PCB.

Pin 7 can be set to GP22 or AGND. Use AGND if you want to use ADC0-2 pins.

The power applied to the I2C may be selected by bridging the power selection jumper.

A similar jumper is adjacent to the I2C1 header.


# NVM Storage


External NVM may be attached to either the I2C1 header, the FRAM Breakout header, or soldered down to the IC5 footprint. If either of the latter two choices are used, the I2C Address jumpers may be used to select non-default addresses or implement write protection. Otherwise, these would be functions of the module plugged into the I2C1 header.

A typical part would be a module utilizing an AT25C256 chip (left) or RC256V FRAM (right).

An Adafruit FRAM breakout board may be attached to this header.

I2C modules including NVM may be attached to this header.


I2C address may be selected by the lower three pairs of headers. The selection will apply to the soldered NVM module or FRAM Breakout header

I2C nonvolatile memory may be populated if desired to reduce strain on the Pico flash. Parts compatible with these should work.

BR24G512F-3AGTE2 I2C BUS(2-Wre) 512K

MB85RC256VPF-G-BCERE1 256kbit FRAM with I2C

Either 3.3V or 5V may be selected by this solder jumper. The selection will apply to the soldered NVM module, I2C1, and FRAM Breakout header.


# Bill of Materials

Qty | Value | Reference | Mfr. # | Description
6 | 0.1uF, 100nF | C1,C3,C6,C15,C19,C20 | C1206C104K3RAC7411 | Multilayer Ceramic Capacitors MLCC - SMD/SMT 25V 0.1uF X7R 1206 10%
1 | 470uF | C2 | REF1016471M035K | Aluminum Electrolytic Capacitors - Radial Leaded Radial Leaded Aluminum Electrolytic Capacitor
7 | 22uF | C4,C5,C8,C9,C10,C11,C12 | CL31A226MOCLNNC | Multilayer Ceramic Capacitors MLCC - SMD/SMT 22uF+/-20% 16V X5R 3 1206
1 | 1uF | C7 | CL31B105KAHNFNE | Multilayer Ceramic Capacitors MLCC - SMD/SMT 1uF+/-10% 25V X7R 32 1206
2 | 22pF | C13,C14 | C1206C220J3HACTU | Multilayer Ceramic Capacitors MLCC - SMD/SMT 25V 22pF X8R 1206 5%
1 | 4.7uF | C16 | CL31B475KOHNFNE | Multilayer Ceramic Capacitors MLCC - SMD/SMT 4.7uF+/-10% 16V X7R 1206
1 | 470nF | C21
6 | LED | D1,D4,D5,D7,D8,D12 | 156120VS75000 | Single Color LEDs WL-SMRW SMD RvMt Mon Wtrclr Rect 1206BtGn
4 | M7 | D2,D3,D9,D10 | M7 | Rectifiers Diode, SMA, 1000V, 1A
2 | PwrG | D6,D11 | 156120VS75000 | Single Color LEDs WL-SMRW SMD RvMt Mon Wtrclr Rect 1206BtGn
2 | 0ZCG0035AF2C | F1,F2 | 0ZCG0035AF2C | Resettable Fuses - PPTC
1 | TPS54294PWPR | IC1 | TPS54294PWPR | Switching Voltage Regulators 4.5-18Vin Dual 2A Ou t Sync SD Cnvrtr A A 595-TPS54294PWP
1 | MCP2518FDT-E_SL | IC2 | MCP2518FDT-E/SL | CAN Interface IC Stand-alone Low Power CAN FD Controller w/SPI Interface Grade1
1 | MCP2562FDT-E/SN | IC3 | MCP2562FDT-E/SN | CAN Interface IC CAN Flexible Data Rate Transceiver
1 | TPS3840DxNBR | IC4
1 | MB85RCxxxV | IC5 | BR24G512F-3AGTE2 | EEPROM I2C BUS(2-Wre) 512K SOP8 EEPROM
2 | RJ45 | J1,J2 | MTJ-880X1 | Modular Connectors / Ethernet Connectors 8P8C TYPE 0 GLD FLSH BLK
1 | SRP3212A-2R2M | L1 | SRP3212A-2R2M | Power Inductors - SMD Ind,3.2x2.5x1mm,2.2uH+/-20%,4A, shd AEC-Q200
1 | SRP3212A-3R3M | L2 | SRP3212A-3R3M | Power Inductors - SMD Ind,3.2x2.5x1mm,3.3uH+/-20%,3.1A, shd AEC-Q200
1 | DMG2305UX-7 | Q1 | DMG2305UX-7 | MOSFETs P-Ch ENH FET -20V 52mOh -5A
1 | 124K | R1 | ERA-8AEB1243V | Thin Film Resistors - SMD 1206 124Kohm 25ppm 0.1% AEC-Q200
2 | 22.1K | R2,R4 | ERA-8AEB2212V | Thin Film Resistors - SMD 1206 22.1Kohm 25ppm 0.1% AEC-Q200
1 | 73.2K | R3 | ERA-8AEB7322V | Thin Film Resistors - SMD 1206 73.2Kohm 25ppm 0.1% AEC-Q200
3 | 3K | R5,R10,R12
1 | 820R | R6 | RT1206FRE07820RL | Thin Film Resistors - SMD 1/4W 820 ohm 1% 50ppm
3 | 560R | R7,R18,R19 | RT1206FRE07560RL | Thin Film Resistors - SMD 560 OHM 1% 50PPM 1/4W
4 | 10K | R8,R9,R13,R14
1 | 2K | R11 | RT1206FRE072KL | Thin Film Resistors - SMD 1/4W 2K ohm 1% 50ppm
1 | 6k8 | R15 | RT1206DRD076K8L | Thin Film Resistors - SMD 6.8 kOhms 250 mW 0.5 % 1206
1 | 560K | R16
1 | 100K | R17
1 | Raspberry Pi Pico | RPiPico1
1 | Pico Reset | SW1 | TS11-674-43-BK-160-RA-D | Tactile Switches 6 x 7.4 mm 4.3 mm 160 gf Black Right Angle Through Hole SPST
1 | Blue Button | SW2 | TS11-674-43-BK-160-RA-D | Tactile Switches 6 x 7.4 mm 4.3 mm 160 gf Black Right Angle Through Hole SPST
1 | Gold Button | SW3 | TS11-674-43-BK-160-RA-D | Tactile Switches 6 x 7.4 mm 4.3 mm 160 gf Black Right Angle Through Hole SPST
1 | ABM-40MHZ | Y1 | ABM3-40.000MHZ-B2-T | Crystals Xtal 5032 2-SMD 40MHz Tol +/-20ppm Stab +/-50ppm -20C - 70C 18pF 25 Ohms

### Connections:

J3 | Select power from LCC or Inject Power to LCC
J4, J21 | 10 pin IDC connector I/O
J5,J7 | I2C Header
J6,J8,J12 | 3.3/5 Volt Power Selection
J9 | Fram Breakout header
J14,J17 | Pico Pinout Conn_01x20
J16 | FRAM Power Select
J18 | 5 volt power out
J19 | 3.3 volt power out
J20 | Barrel Jack power input
J24 | External Reset header
J27 | MasterPower bridge header
JP1 | J2 LCC Power enable
JP3 | J1 LCC Power enable
JP4 | LCC Ground enable
JP6-9 | NVM Address & WP

# Software

### Board:

The author uses the RP2040 board library by Earle Philhower

https://arduino-pico.readthedocs.io/en/latest/install.html

### For LCC support:

https://github.com/openlcb/OpenLCB_Single_Thread

Or

https://github.com/JimKueneman/OpenLcbCLib

### CAN Hardware:

ACAN2517 Arduino library.

### External Storage:

I2C_EEPROM Arduino library by Rob Tillaart

FRAM_I2C Arduino library by Rob Tillaart

### NeoPixel:

NeoPixelBus by Makuna Arduino library (preferred)

Or

NeoPixelConnect Arduino library by Alan Yorinks.

### Other preferred libraries for the RPi Pico:

#### Display

#include <TFT_eSPI.h> // Hardware-specific display library

#include "my_bb_captouch.h" //capacitive touch driver

#### Servos

#include <ServoEasing.hpp> // great library for getting slow servo action, including bounces

#include <PCA9685_servo_driver.h>

#include <PCA9685_servo.h>

#### Stepper Motor

#include "AccelStepper.h" // by Mike McCauley

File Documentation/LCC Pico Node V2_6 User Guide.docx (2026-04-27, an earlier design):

# LCC Pico Node User Guide

Version 2.6

This version utilizes the MCP2815 and MCP2562 discrete hardware components (chips) for the LCC interface.

The intent of this node is to control up to four strings of NeoPixels and/or other peripheral components on a model railroad layout. It may also be adapted to several other uses as there is facility to connect to all the exposed pins on the Raspberry Pi Pico microcontroller. J11, J12, J15, and J23 have power and ground pins in line to facilitate NeoPixel string connections. While it will work with either the Pico or Pico2, the latter is recommended due to enhanced capabilities.

There are no resistors on the Reset, Blue, and Gold button lines.


The node may be powered from the barrel jack or the LCC port. The barrel jack power should be at least seven (7) volts to power the microcontroller or fifteen (15) volts [or your preferred LCC voltage] if using the node to inject power to LCC. Amperage should be sufficient to drive any external devices plus about half an amp for the node plus another 1.5 amps if injecting power to LCC. There are six power LEDs. Five should be lit to indicate that the node is properly powered, six if barrel jack powered.

Node power configuration is accomplished with five jumpers located behind the LCC ports.

Master Power jumper should be bridged to power the node. A normally closed button may be plugged in here as a means to do a hardware reset should there be a problem with the power initialization due to a slow ramping power supply.


LCC Pwrd jumper should be bridged along with the LCC Grnd jumper if the node is to be powered from the LCC Port. Note that this will not provide power to the stepper driver which is powered exclusively from the barrel jack.

Inject Power should be bridged along with the LCC Grnd jumper if the node is intended to inject power to one or both of the LCC ports. 15 volts of at least 1.5 amps should be applied to the barrel jack in order to inject power.

J1 Pwr and J2 Pwr jumpers allow power isolation of one or both LCC ports. Generally, both jumpers would be bridged. If power injection or utilization was only desired in one direction, then the opposing jumper would be opened to isolate that leg. The isolated leg should be powered downstream as opening the jumper will cut off any power from the node.

LCC Grnd jumper should be bridged if the node is intended to inject power to or draw power from one or both of the LCC ports.


J24 jumper may be attached to a normally open button to function as a Reset as it is in parallel to the on board Reset button.


The power applied to the middle pins of the IDC connector may be selected by bridging the respective power selection jumpers. Pin assignments are noted on the PCB.


The power applied to the I2C may be selected by bridging the power selection jumper.

A similar jumper is adjacent to the I2C1 header.

# NVM Storage

Either 3.3V or 5V may be selected by these solder jumpers. The selection will apply to the soldered NVM module or FRAM Breakout header

I2C address may be selected by the lower three pairs of headers. The selection will apply to the soldered NVM module or FRAM Breakout header

An Adafruit FRAM breakout board may be attached to this header.


I2C modules including NVM may be attached to this header. Either 3.3V or 5V may be selected by the adjacent jumpers.

I2C nonvolatile memory may be populated if desired to reduce strain on the Pico flash. Parts compatible with these should work.

BR24G512F-3AGTE2 I2C BUS(2-Wre) 512K

MB85RC256VPF-G-BCERE1 256kbit FRAM with I2C


External NVM may be attached to either the I2C1 header, the FRAM Breakout header, or soldered down to the IC5 footprint. If either of the latter two choices are used, the I2C Address jumpers may be used to select non-default addresses or implement write protection. Otherwise, these would be functions of the module plugged into the I2C1 header.

A typical part would be a module utilizing an AT25C256 chip (left) or RC256V FRAM (right).


# Bill of Materials

Qty | Value | Reference | Mfr. # | Description
5 | 0.1uF, 100nF | C1,C3,C6,C15,C19 | C1206C104K3RAC7411 | Multilayer Ceramic Capacitors MLCC - SMD/SMT 25V 0.1uF X7R 1206 10%
1 | 470uF | C2 | REF1016471M035K | Aluminum Electrolytic Capacitors - Radial Leaded Radial Leaded Aluminum Electrolytic Capacitor
7 | 22uF | C4,C5,C8,C9,C10,C11,C12 | CL31A226MOCLNNC | Multilayer Ceramic Capacitors MLCC - SMD/SMT 22uF+/-20% 16V X5R 3 1206
1 | 1uF | C7 | CL31B105KAHNFNE | Multilayer Ceramic Capacitors MLCC - SMD/SMT 1uF+/-10% 25V X7R 32 1206
2 | 22pF | C13,C14 | C1206C220J3HACTU | Multilayer Ceramic Capacitors MLCC - SMD/SMT 25V 22pF X8R 1206 5%
1 | 4.7uF | C16 | CL31B475KOHNFNE | Multilayer Ceramic Capacitors MLCC - SMD/SMT 4.7uF+/-10% 16V X7R 1206
4 | M7 | D2,D3,D9,D10 | M7 | Rectifiers Diode, SMA, 1000V, 1A
2 | 0ZCG0035AF2C | F1,F2 | 0ZCG0035AF2C | Resettable Fuses - PPTC
1 | TPS54294PWPR | IC1 | TPS54294PWPR | Switching Voltage Regulators 4.5-18Vin Dual 2A Ou t Sync SD Cnvrtr A A 595-TPS54294PWP
1 | MCP2518FDT-E_SL | IC2 | MCP2518FDT-E/SL | CAN Interface IC Stand-alone Low Power CAN FD Controller w/SPI Interface Grade1
1 | MCP2562FDT-E/SN | IC3 | MCP2562FDT-E/SN | CAN Interface IC CAN Flexible Data Rate Transceiver
1 | MB85RCxxxV | IC5 | BR24G512F-3AGTE2 | EEPROM I2C BUS(2-Wre) 512K SOP8 EEPROM
2 | RJ45 | J1,J2 | MTJ-880X1 | Modular Connectors / Ethernet Connectors 8P8C TYPE 0 GLD FLSH BLK
1 | SRP3212A-2R2M | L1 | SRP3212A-2R2M | Power Inductors - SMD Ind,3.2x2.5x1mm,2.2uH+/-20%,4A,shd AEC-Q200
1 | SRP3212A-3R3M | L2 | SRP3212A-3R3M | Power Inductors - SMD Ind,3.2x2.5x1mm,3.3uH+/-20%,3.1A,shd AEC-Q200
1 | DMG2305UX-7 | Q1 | DMG2305UX-7 | MOSFETs P-Ch ENH FET -20V 52mOh -5A
1 | 124K | R1 | ERA-8AEB1243V | Thin Film Resistors - SMD 1206 124Kohm 25ppm 0.1% AEC-Q200
2 | 22.1K | R2,R4 | ERA-8AEB2212V | Thin Film Resistors - SMD 1206 22.1Kohm 25ppm 0.1% AEC-Q200
1 | 73.2K | R3 | ERA-8AEB7322V | Thin Film Resistors - SMD 1206 73.2Kohm 25ppm 0.1% AEC-Q200
3 | 3K | R5,R10,R12
1 | 820R | R6 | RT1206FRE07820RL | Thin Film Resistors - SMD 1/4W 820 ohm 1% 50ppm
1 | 560R | R7 | RT1206FRE07560RL | Thin Film Resistors - SMD 560 OHM 1% 50PPM 1/4W
4 | 10K | R8,R9,R13,R14
1 | 2K | R11 | RT1206FRE072KL | Thin Film Resistors - SMD 1/4W 2K ohm 1% 50ppm
1 | 6k8 | R15 | RT1206DRD076K8L | Thin Film Resistors - SMD 6.8 kOhms 250 mW 0.5 % 1206
1 | Raspberry Pi Pico | RPiPico1
3 | Pico Reset | SW1,2,3 | TS11-674-43-BK-160-RA-D | Tactile Switches 6 x 7.4 mm 4.3 mm 160 gf Black Right Angle Through Hole SPST
1 | ABM-40MHZ | Y1 | ABM3-40.000MHZ-B2-T | Crystals Xtal 5032 2-SMD 40MHz Tol +/-20ppm Stab +/-50ppm -20C - 70C 18pF 25 Ohms
4 | LED | D4,D5,D7,D8 | 156120VS75000 | Single Color LEDs WL-SMRW SMD RvMt Mon Wtrclr Rect 1206BtGn
2 | PwrG | D6,D11 | 156120VS75000 | Single Color LEDs WL-SMRW SMD RvMt Mon Wtrclr Rect 1206BtGn

### Connections:

J3,J6,J12 | 3.3/5 Volt Power Selection
J5,J7 | I2C Header
J9 | Fram Breakout header
J10 | NVM Address
J11,J13,J15,J23 | NeoPixel Headers
J14,J17 | Pico Pinout Conn_01x20
J16 | FRAM Power Select
J18 | 5 volt power out
J19 | 3.3 volt power out
J20 | Barrel Jack power input
J21 | 10 pin IDC connector I/O
J22 | AGND headers
J24 | External Reset header
J27 | MasterPower bridge header
JP1 | J2 LCC Power enable
JP2 | Power from LCC enable
JP3 | J1 LCC Power enable
JP4 | LCC Ground enable
JP5 | Inject Power to LCC enable

# Software

### Board:

The author uses the RP2040 board library by Earle Philhower

https://arduino-pico.readthedocs.io/en/latest/install.html

### For LCC support:

https://github.com/openlcb/OpenLCB_Single_Thread

Or

https://github.com/JimKueneman/OpenLcbCLib

### CAN Hardware:

ACAN2517 Arduino library.

### External Storage:

I2C_EEPROM Arduino library by Rob Tillaart

FRAM_I2C Arduino library by Rob Tillaart

### NeoPixel:

NeoPixelBus by Makuna Arduino library (preferred)

Or

NeoPixelConnect Arduino library by Alan Yorinks.

### Other preferred libraries for the RPi Pico:

#### Display

#include <TFT_eSPI.h> // Hardware-specific display library

#include "my_bb_captouch.h" //capacitive touch driver

#### Servos

#include <ServoEasing.hpp> // great library for getting slow servo action, including bounces

#include <PCA9685_servo_driver.h>

#include <PCA9685_servo.h>

#### Stepper Motor

#include "AccelStepper.h" // by Mike McCauley

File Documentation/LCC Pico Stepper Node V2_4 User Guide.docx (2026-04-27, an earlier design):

# LCC Pico Turntable Node User Guide

Version 2.4

This version utilizes the MCP2815 and MCP2562 discrete components for the LCC interface.

The intent of this node is to control all aspects of a turntable & roundhouse engine facility on a model railroad layout. It may also be adapted to several other uses as there is facility to connect to all the exposed pins on the Raspberry Pi Pico microcontroller. Some pins have power and ground pins in line to facilitate peripheral connections.

Note that the resistor in line with the reset button has been changed to zero ohm from the 10K shown. There are no resistors on the Blue and Gold button lines.


The node may be powered from the barrel jack or the LCC port. If driving a stepper motor power must be applied from the barrel jack. In this case the external power must be suitable for the motor and stepper controller. The barrel jack power should be at least seven (7) volts to power the node or fifteen (15) volts if using the node to inject power to LCC. Amperage should be sufficient to drive any external devices plus about half an amp for the node plus another 1.5 amps if injecting power to LCC.

Node power configuration is accomplished with five jumpers located behind the LCC ports.


LCC Pwrd jumper should be bridged along with the LCC Grnd jumper if the node is to be powered from the LCC Port. Note that this will not provide power to the stepper driver which is powered exclusively from the barrel jack.

J1 Pwr and J2 Pwr jumpers allow power isolation of one or both LCC ports. Generally, both jumpers would be bridged. If power injection or utilization was only desired in one direction, then the opposing jumper would be opened to isolate that leg. The isolated leg should be powered downstream as opening the jumper will cut off any power from the node.

LCC Grnd jumper should be bridged if the node is intended to inject power to or draw power from one or both of the LCC ports.

Inject Power should be bridged along with the LCC Grnd jumper if the node is intended to inject power to one or both of the LCC ports. 15 volts of at least 1.5 amps should be applied to the barrel jack in order to inject power.


The power applied to the middle pins of the GPIO blocks of four may be selected by bridging the respective power selection jumpers.

The power applied to the 40 pin display connector may be selected by bridging the respective power selection jumper.

The power applied to the I2C may be selected by bridging the power selection jumper.


The power applied to the I2C nonvolatile memory may be selected by bridging the power selection jumper.


I2C nonvolatile memory may be populated if desired to reduce strain on the Pico flash. Parts compatible with these should work.

BR24G512F-3AGTE2 I2C BUS(2-Wre) 512K

MB85RC256VPF-G-BCERE1 256kbit FRAM with I2


The stepper motor driver, if populated, can be configured with these jumpers. Bigtreetech TMC2208 V3.0 UART Stepper with Heat Sink has worked well for me as a replacement for a A4988


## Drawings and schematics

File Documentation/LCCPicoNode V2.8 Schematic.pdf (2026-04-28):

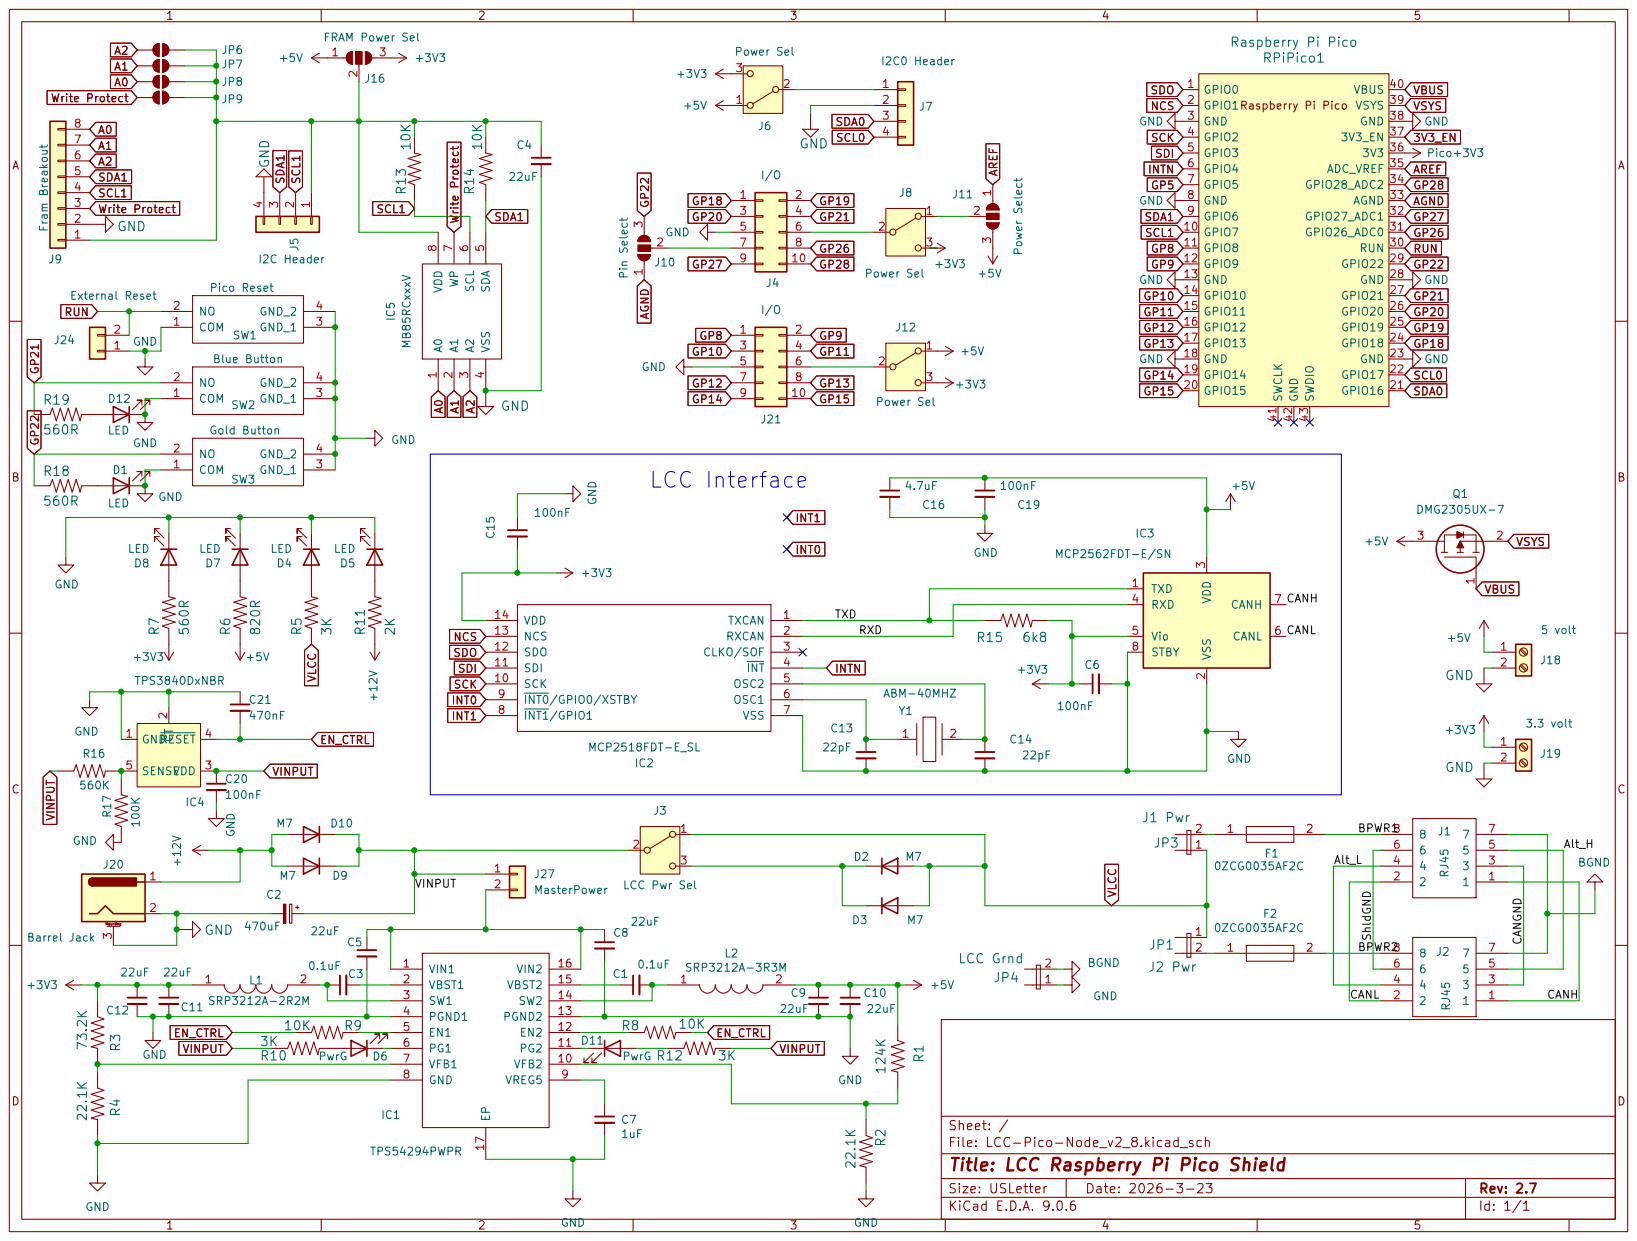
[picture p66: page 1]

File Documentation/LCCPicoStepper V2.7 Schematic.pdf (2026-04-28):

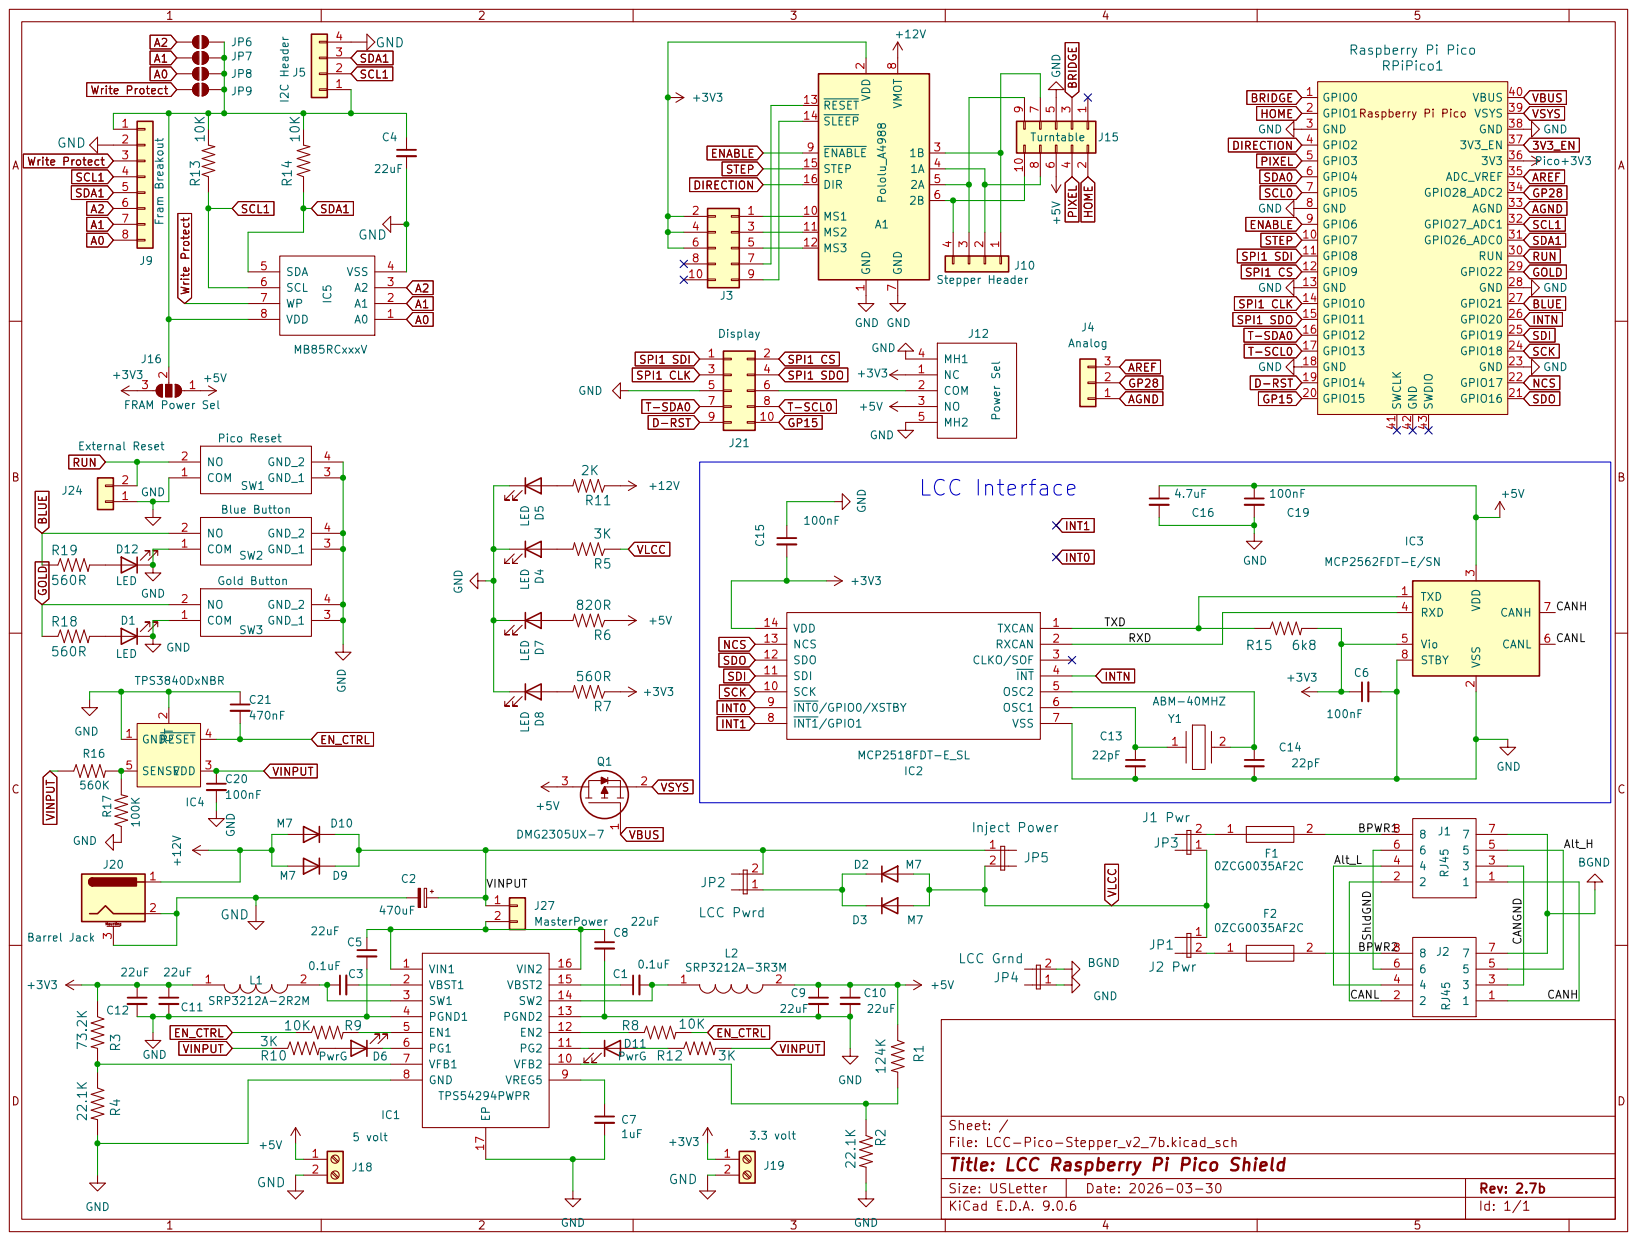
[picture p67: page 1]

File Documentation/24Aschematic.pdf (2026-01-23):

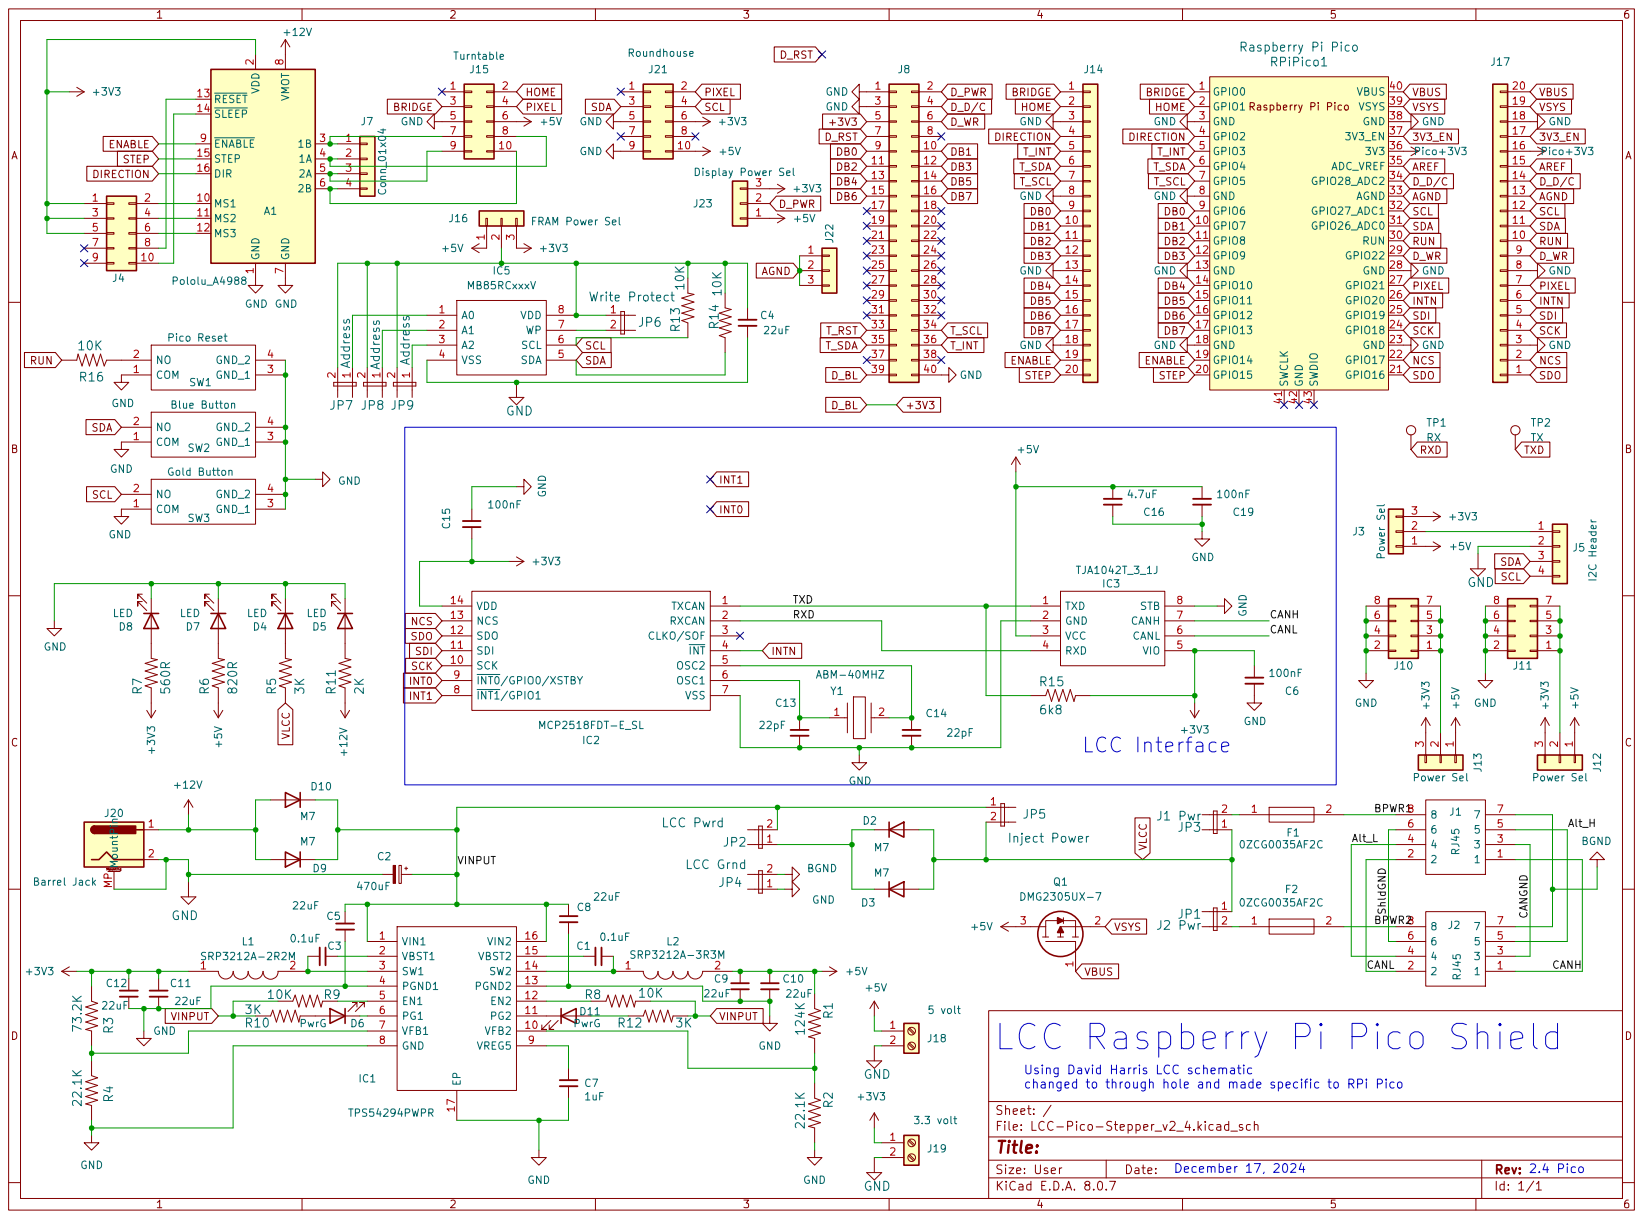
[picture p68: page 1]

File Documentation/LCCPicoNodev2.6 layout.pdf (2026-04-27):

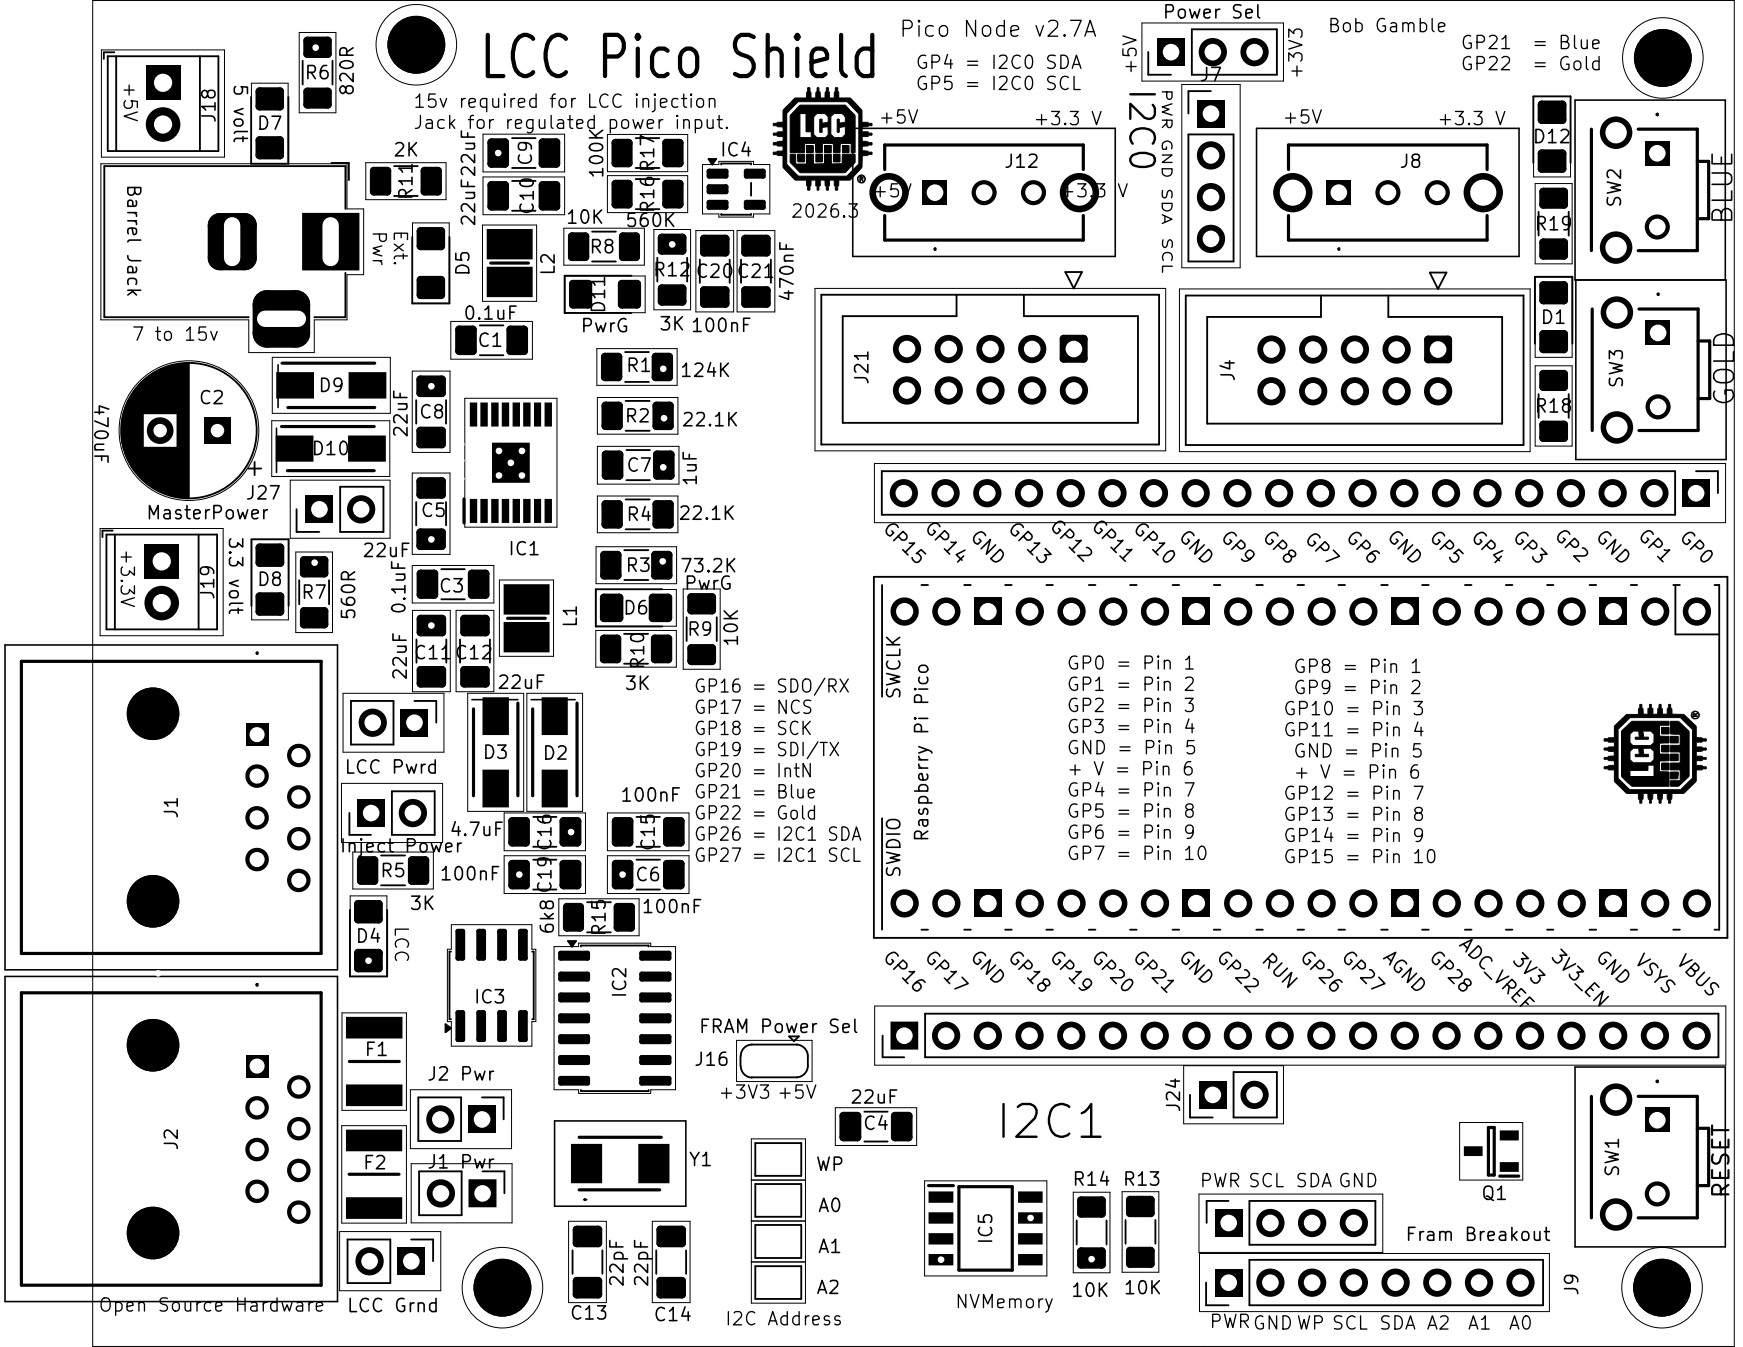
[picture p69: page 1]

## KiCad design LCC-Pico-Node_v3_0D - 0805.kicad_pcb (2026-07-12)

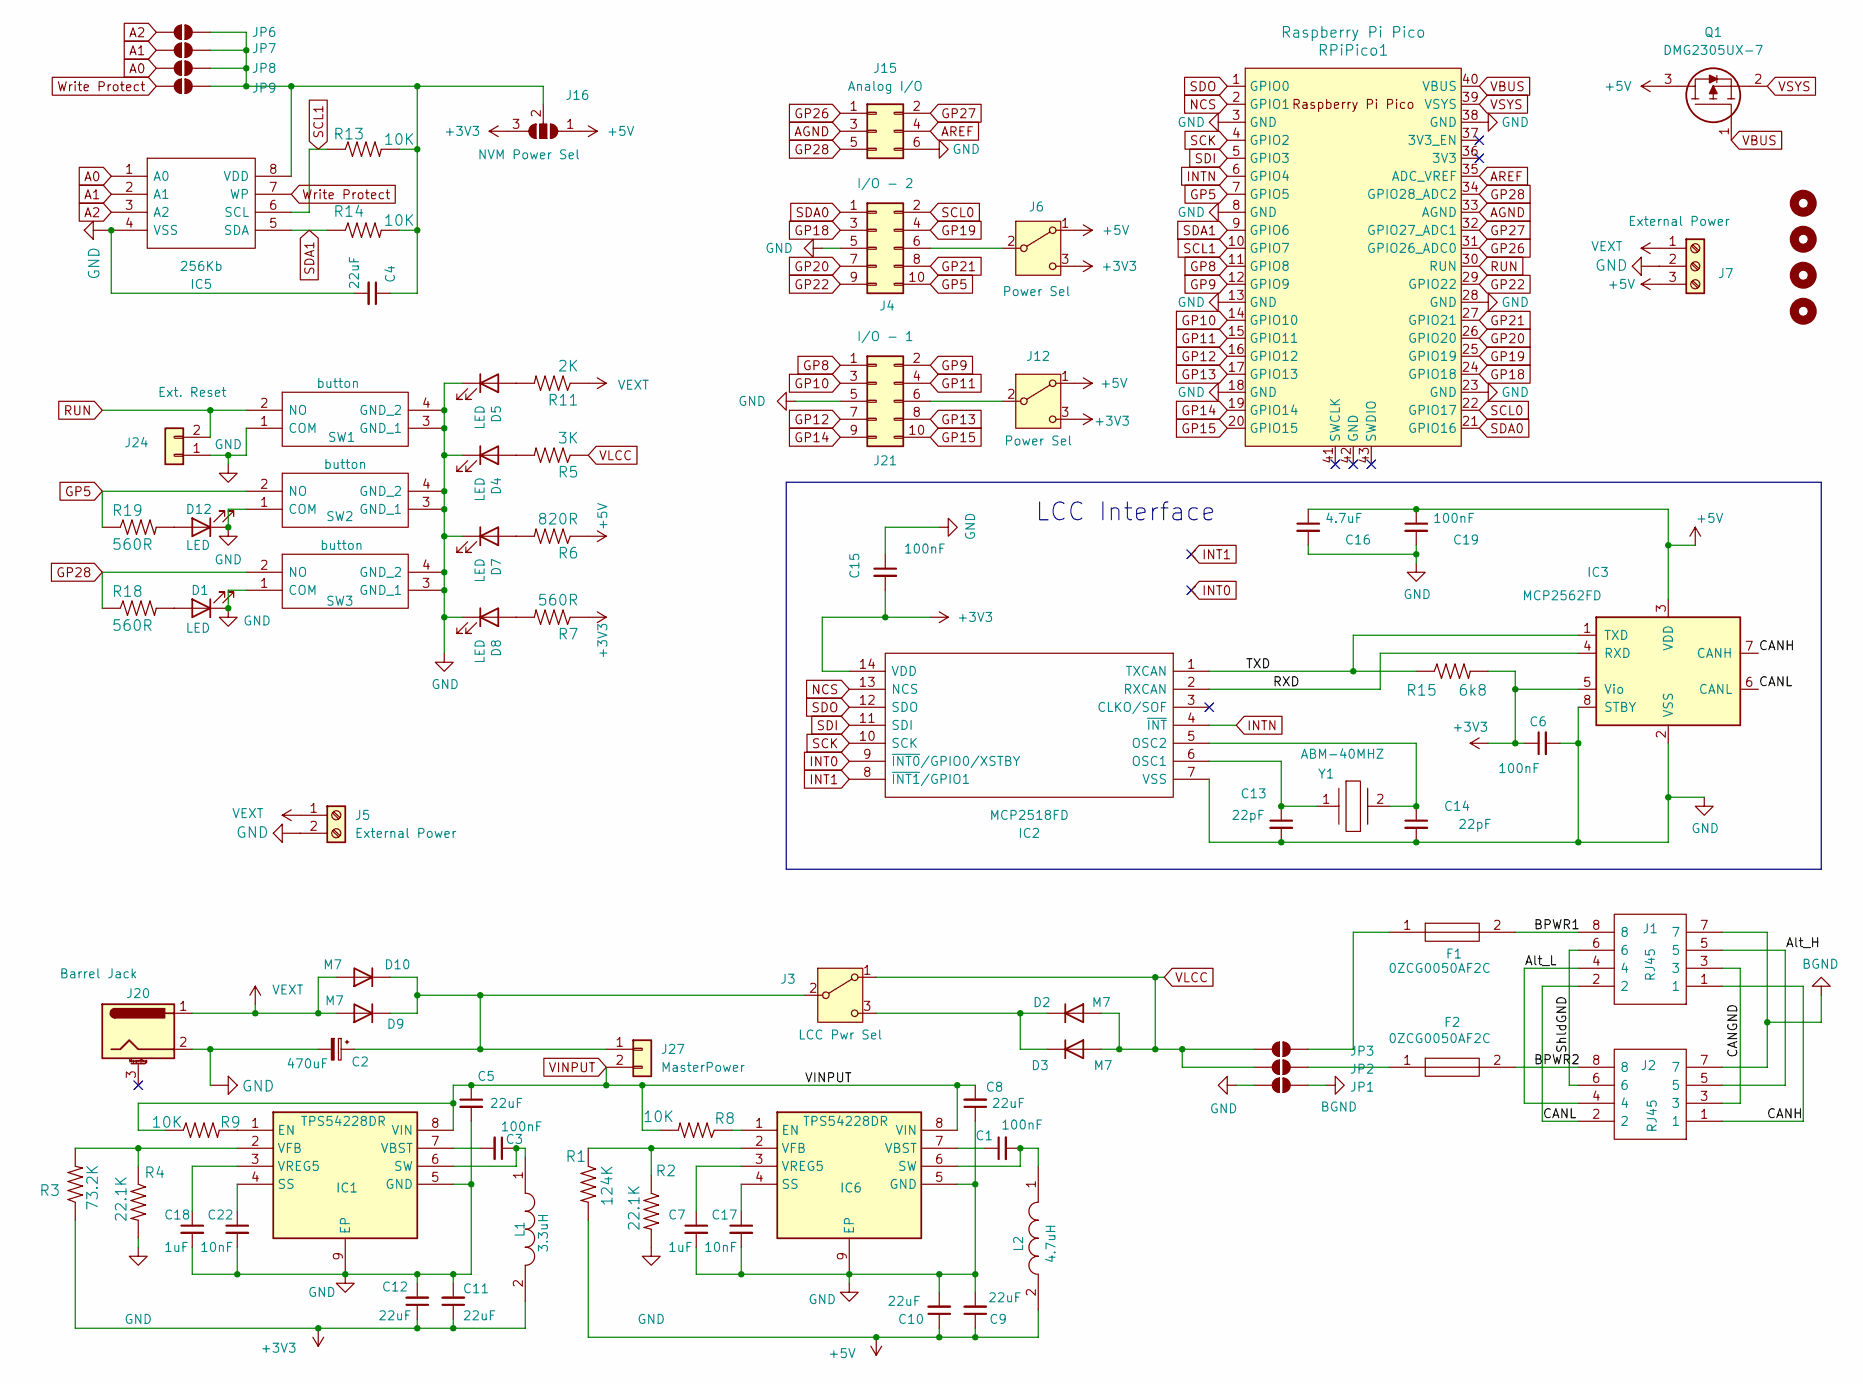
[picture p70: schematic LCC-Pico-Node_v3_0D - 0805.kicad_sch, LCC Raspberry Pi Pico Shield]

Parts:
C1, C3, C6, C15, C19: 100nF; C_0805_2012Metric; LCSC C49678
C2: 470uF; CP_Elec_8x10.5; LCSC C48935389
C4, C5, C8, C9, C10, C11, C12: 22uF; C_0805_2012Metric; LCSC C45783
C7, C18: 1uF; C_0805_2012Metric; LCSC C28323
C13, C14: 22pF; C_0805_2012Metric; LCSC C1804
C16: 4.7uF; C_0805_2012Metric; LCSC C1779
C17, C22: 10nF; C_0805_2012Metric; LCSC C1710
D1, D4, D5, D7, D8, D12: LED; LED_0805_2012Metric; LCSC C2297
D2, D3, D9, D10: M7; D_SMA; LCSC C22448047
F1, F2: 0ZCG0050AF2C; FUSC4632X70N; Mouser Part Number 530-0ZCG0050AF2C
H1, H2, H3, H4: MountingHole; MountingHole_3.2mm_M3
IC1, IC6: TPS54228DR; SOIC127P600X170-9N; Mouser Part Number 595-TPS54228DDAR
IC2: MCP2518FD; SOIC-14_3.9x8.7mm_P1.27mm; Mouser Part Number 579-MCP2518FDT-E/SL
IC3: MCP2562FD; SOIC-8_3.9x4.9mm_P1.27mm; Mouser Part Number 771-TJA1042T/3/1J
IC5: 256Kb; SOIC127P600X175-8N; Mouser Part Number 755-BR24G256F-5E2
J1, J2: RJ45; MTJ880X1; Mouser Part Number 737-MTJ-880X1
J3: LCC Pwr Sel; SLW8645872ARAND
J4: I/O - 2; IDC-Header_2x05_P2.54mm_Vertical
J5: External Power; PhoenixContact_MSTBA_2,5_2-G-5,08_1x02_P5.08mm_Horizontal
J6, J12: Power Sel; SLW8645872ARAND
J7: External Power; JST_EH_B3B-EH-A_1x03_P2.50mm_Vertical
J15: Analog I/O; IDC-Header_2x03_P2.54mm_Vertical
J16: NVM Power Sel; SolderJumper-3_P1.3mm_Open_RoundedPad1.0x1.5mm
J20: Barrel Jack; DC-050_SMD; LCSC C431534
J21: I/O - 1; IDC-Header_2x05_P2.54mm_Vertical
J24: Ext. Reset; PinHeader_1x02_P2.54mm_Vertical
J27: MasterPower; PinHeader_1x02_P2.54mm_Vertical
JP1: GND; SolderJumper-2_P1.3mm_Bridged_RoundedPad1.0x1.5mm
JP2: CAN2; SolderJumper-2_P1.3mm_Open_RoundedPad1.0x1.5mm
JP3: CAN1; SolderJumper-2_P1.3mm_Open_RoundedPad1.0x1.5mm
JP6: A2; SolderJumper-2_P1.3mm_Open_Pad1.0x1.5mm
JP7: A1; SolderJumper-2_P1.3mm_Open_Pad1.0x1.5mm
JP8: A0; SolderJumper-2_P1.3mm_Open_Pad1.0x1.5mm
JP9: WP; SolderJumper-2_P1.3mm_Open_Pad1.0x1.5mm
L1: 3.3uH; L_1210_3225Metric; Mouser Part Number 81-1277AS-H-3R3MP2
L2: 4.7uH; L_1210_3225Metric; Mouser Part Number 81-1276AS-H-4R7MP2
Q1: DMG2305UX-7; SOT96P240X115-3N; Mouser Part Number 621-DMG2305UX-7
R1: 124K; R_0805_2012Metric; LCSC C2902861
R2, R4: 22.1K; R_0805_2012Metric; LCSC C865310
R3: 73.2K; R_0805_2012Metric; LCSC C422816
R5: 3K; R_0805_2012Metric; LCSC C17661
R6: 820R; R_0805_2012Metric; LCSC C17837
R7, R18, R19: 560R; R_0805_2012Metric; LCSC C28636
R8, R9, R13, R14: 10K; R_0805_2012Metric; LCSC C17414
R11: 2K; R_0805_2012Metric; LCSC C17604
R15: 6k8; R_0805_2012Metric; LCSC C17772
RPiPico1: Raspberry Pi Pico; RPi_Pico_SMD_TH; PARTREV 12/May/2017
SW1, SW2, SW3: button; SW_Push_1P1T_XKB_TS-1187A; Mouser Part Number 179-TS1167443160RAD
Y1: ABM-40MHZ; ABM3; Mouser Part Number 815-ABL-40-B2F

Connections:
+3V3: C6.1, C11.1, C12.1, C15.2, IC2.14 (VDD), IC3.5 (Vio), J6.3 (C), J12.3 (C), J16.3 (B), L1.2, R3.1, R7.1, R15.2
+5V: C9.1, C10.1, C16.1, C19.1, IC3.3 (VDD), J6.1 (A), J7.3, J12.1 (A), J16.1 (A), L2.2, Q1.3, R1.2, R6.1
/Alt_H: J1.5, J2.5
/Alt_L: J1.4, J2.4
/BPWR1: F1.2, J1.8
/BPWR2: F2.2, J2.8
/CANGND: J1.3, J2.3
/CANH: IC3.7 (CANH), J1.1, J2.1
/CANL: IC3.6 (CANL), J1.2, J2.2
/RXD: IC2.2 (RXCAN), IC3.4 (RXD)
/ShldGND: J1.6, J2.6
/TXD: IC2.1 (TXCAN), IC3.1 (TXD), R15.1
A0: IC5.1 (A0), JP8.1 (A)
A1: IC5.2 (A1), JP7.1 (A)
A2: IC5.3 (A2), JP6.1 (A)
AGND: J15.3, RPiPico1.33 (AGND)
AREF: J15.4, RPiPico1.35 (ADC_VREF)
BGND: J1.7, J2.7, JP1.2 (B)
GND: C2.2, C4.2, C5.2, C6.2, C7.2, C8.1, C9.2, C10.2, C11.2, C12.2, C13.2, C14.2, C15.1, C16.2, C17.2, C18.2, C19.2, C22.2, D1.1 (K), D4.1 (K), D5.1 (K), D7.1 (K), D8.1 (K), D12.1 (K), IC1.5 (GND), IC1.9 (EP), IC2.7 (VSS), IC3.2 (VSS), IC3.8 (STBY), IC5.4 (VSS), IC6.5 (GND), IC6.9 (EP), J4.5, J5.2, J7.2, J15.6, J20.2, J21.5, J24.1, JP1.1 (A), R2.2, R4.2, RPiPico1.3 (GND), RPiPico1.8 (GND), RPiPico1.13 (GND), RPiPico1.18 (GND), RPiPico1.23 (GND), RPiPico1.28 (GND), RPiPico1.38 (GND), SW1.1 (COM), SW1.3 (GND_1), SW1.4 (GND_2), SW2.1 (COM), SW2.3 (GND_1), SW2.4 (GND_2), SW3.1 (COM), SW3.3 (GND_1), SW3.4 (GND_2)
GP5: J4.10, R19.1, RPiPico1.7 (GPIO5), SW2.2 (NO)
GP8: J21.1, RPiPico1.11 (GPIO8)
GP9: J21.2, RPiPico1.12 (GPIO9)
GP10: J21.3, RPiPico1.14 (GPIO10)
GP11: J21.4, RPiPico1.15 (GPIO11)
GP12: J21.7, RPiPico1.16 (GPIO12)
GP13: J21.8, RPiPico1.17 (GPIO13)
GP14: J21.9, RPiPico1.19 (GPIO14)
GP15: J21.10, RPiPico1.20 (GPIO15)
GP18: J4.3, RPiPico1.24 (GPIO18)
GP19: J4.4, RPiPico1.25 (GPIO19)
GP20: J4.7, RPiPico1.26 (GPIO20)
GP21: J4.8, RPiPico1.27 (GPIO21)
GP22: J4.9, RPiPico1.29 (GPIO22)
GP26: J15.1, RPiPico1.31 (GPIO26_ADC0)
GP27: J15.2, RPiPico1.32 (GPIO27_ADC1)
GP28: J15.5, R18.1, RPiPico1.34 (GPIO28_ADC2), SW3.2 (NO)
INT0: IC2.9 (~INT0/GPIO0/XSTBY)
INT1: IC2.8 (~INT1/GPIO1)
INTN: IC2.4 (~INT), RPiPico1.6 (GPIO4)
NCS: IC2.13 (NCS), RPiPico1.2 (GPIO1)
unnamed: D1.2 (A), R18.2
unnamed: D2.1 (K), D3.1 (K), J3.3 (C)
unnamed: D4.2 (A), R5.2
unnamed: D5.2 (A), R11.2
unnamed: D7.2 (A), R6.2
unnamed: D8.2 (A), R7.2
unnamed: C2.1, D9.1 (K), D10.1 (K), J3.2 (B), J27.1
unnamed: D12.2 (A), R19.2
unnamed: IC1.1 (EN), R9.2
unnamed: C22.1, IC1.4 (SS)
unnamed: C3.1, IC1.6 (SW), L1.1
unnamed: C3.2, IC1.7 (VBST)
unnamed: IC1.2 (VFB), R3.2, R4.1
unnamed: C18.1, IC1.3 (VREG5)
unnamed: C13.1, IC2.6 (OSC1), Y1.1
unnamed: C14.1, IC2.5 (OSC2), Y1.2
unnamed: C4.1, IC5.8 (VDD), J16.2 (C), JP6.2 (B), JP7.2 (B), JP8.2 (B), JP9.2 (B), R13.2, R14.2
unnamed: IC6.1 (EN), R8.1
unnamed: C17.1, IC6.4 (SS)
unnamed: C1.2, IC6.6 (SW), L2.1
unnamed: C1.1, IC6.7 (VBST)
unnamed: IC6.2 (VFB), R1.1, R2.1
unnamed: C7.1, IC6.3 (VREG5)
unnamed: J4.6, J6.2 (B)
unnamed: J12.2 (B), J21.6
unnamed: F2.1, JP2.2 (B)
unnamed: F1.1, JP3.2 (B)
RUN: J24.2, RPiPico1.30 (RUN), SW1.2 (NO)
SCK: IC2.10 (SCK), RPiPico1.4 (GPIO2)
SCL0: J4.2, RPiPico1.22 (GPIO17)
SCL1: IC5.6 (SCL), R13.1, RPiPico1.10 (GPIO7)
SDA0: J4.1, RPiPico1.21 (GPIO16)
SDA1: IC5.5 (SDA), R14.1, RPiPico1.9 (GPIO6)
SDI: IC2.11 (SDI), RPiPico1.5 (GPIO3)
SDO: IC2.12 (SDO), RPiPico1.1 (GPIO0)
VBUS: Q1.1, RPiPico1.40 (VBUS)
VEXT: D9.2 (A), D10.2 (A), J5.1, J7.1, J20.1, R11.1
VINPUT: C5.1, C8.2, IC1.8 (VIN), IC6.8 (VIN), J27.2, R8.2, R9.1
VLCC: D2.2 (A), D3.2 (A), J3.1 (A), JP2.1 (A), JP3.1 (A), R5.1
VSYS: Q1.2, RPiPico1.39 (VSYS)
Write Protect: IC5.7 (WP), JP9.1 (A)

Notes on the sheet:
LCC Interface

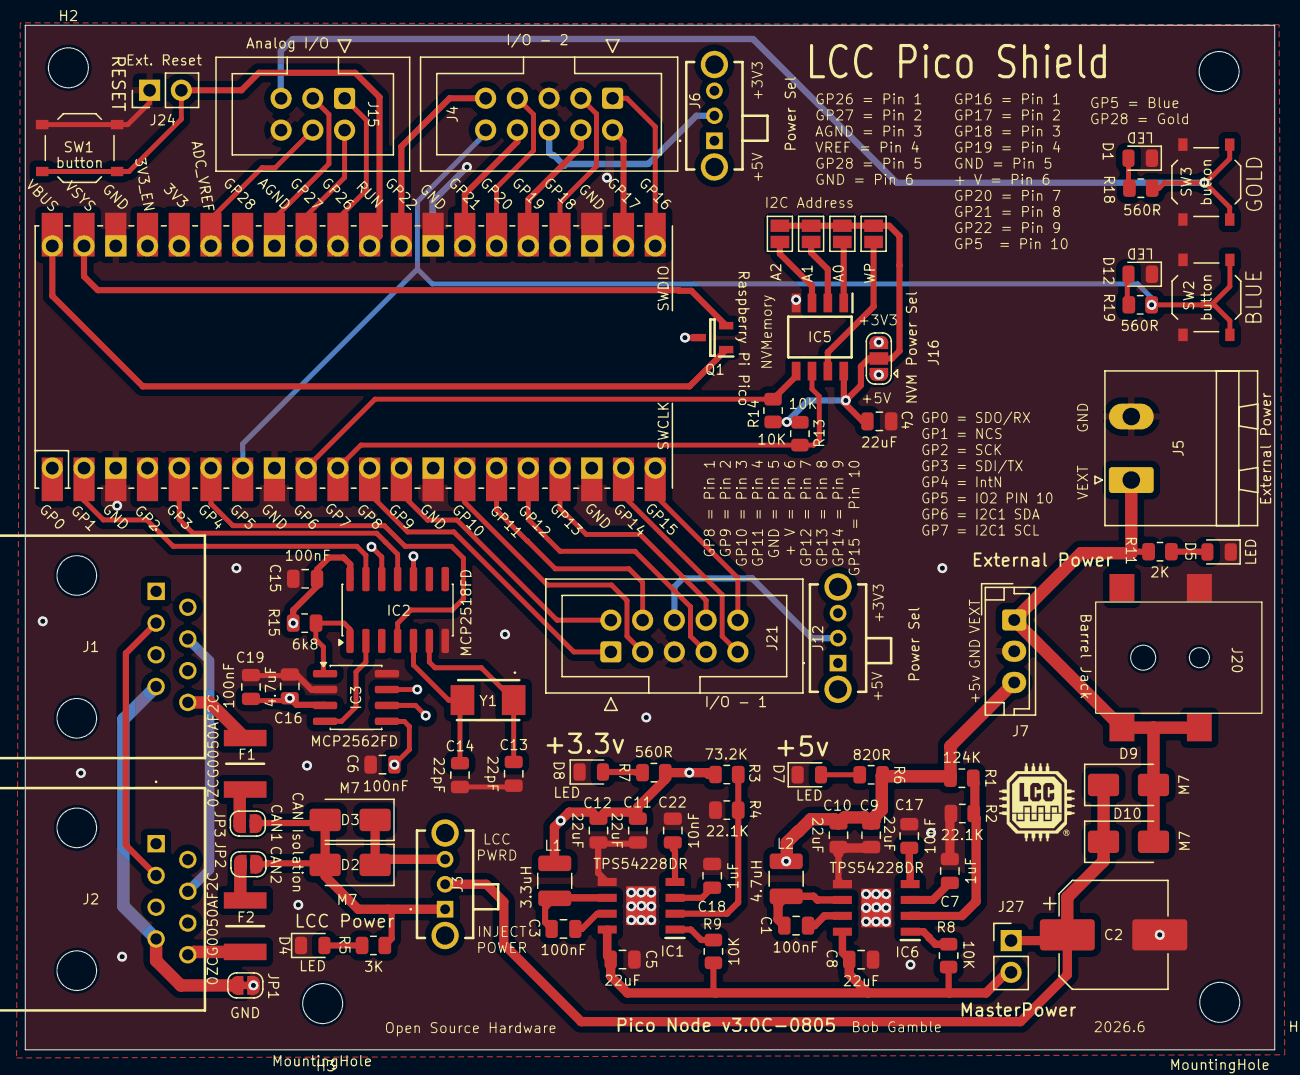
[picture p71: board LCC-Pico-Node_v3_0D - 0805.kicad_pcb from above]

Board: 4 copper layers, 100.0 x 82.0 mm, 85 parts (0 on the bottom side), 79 nets.

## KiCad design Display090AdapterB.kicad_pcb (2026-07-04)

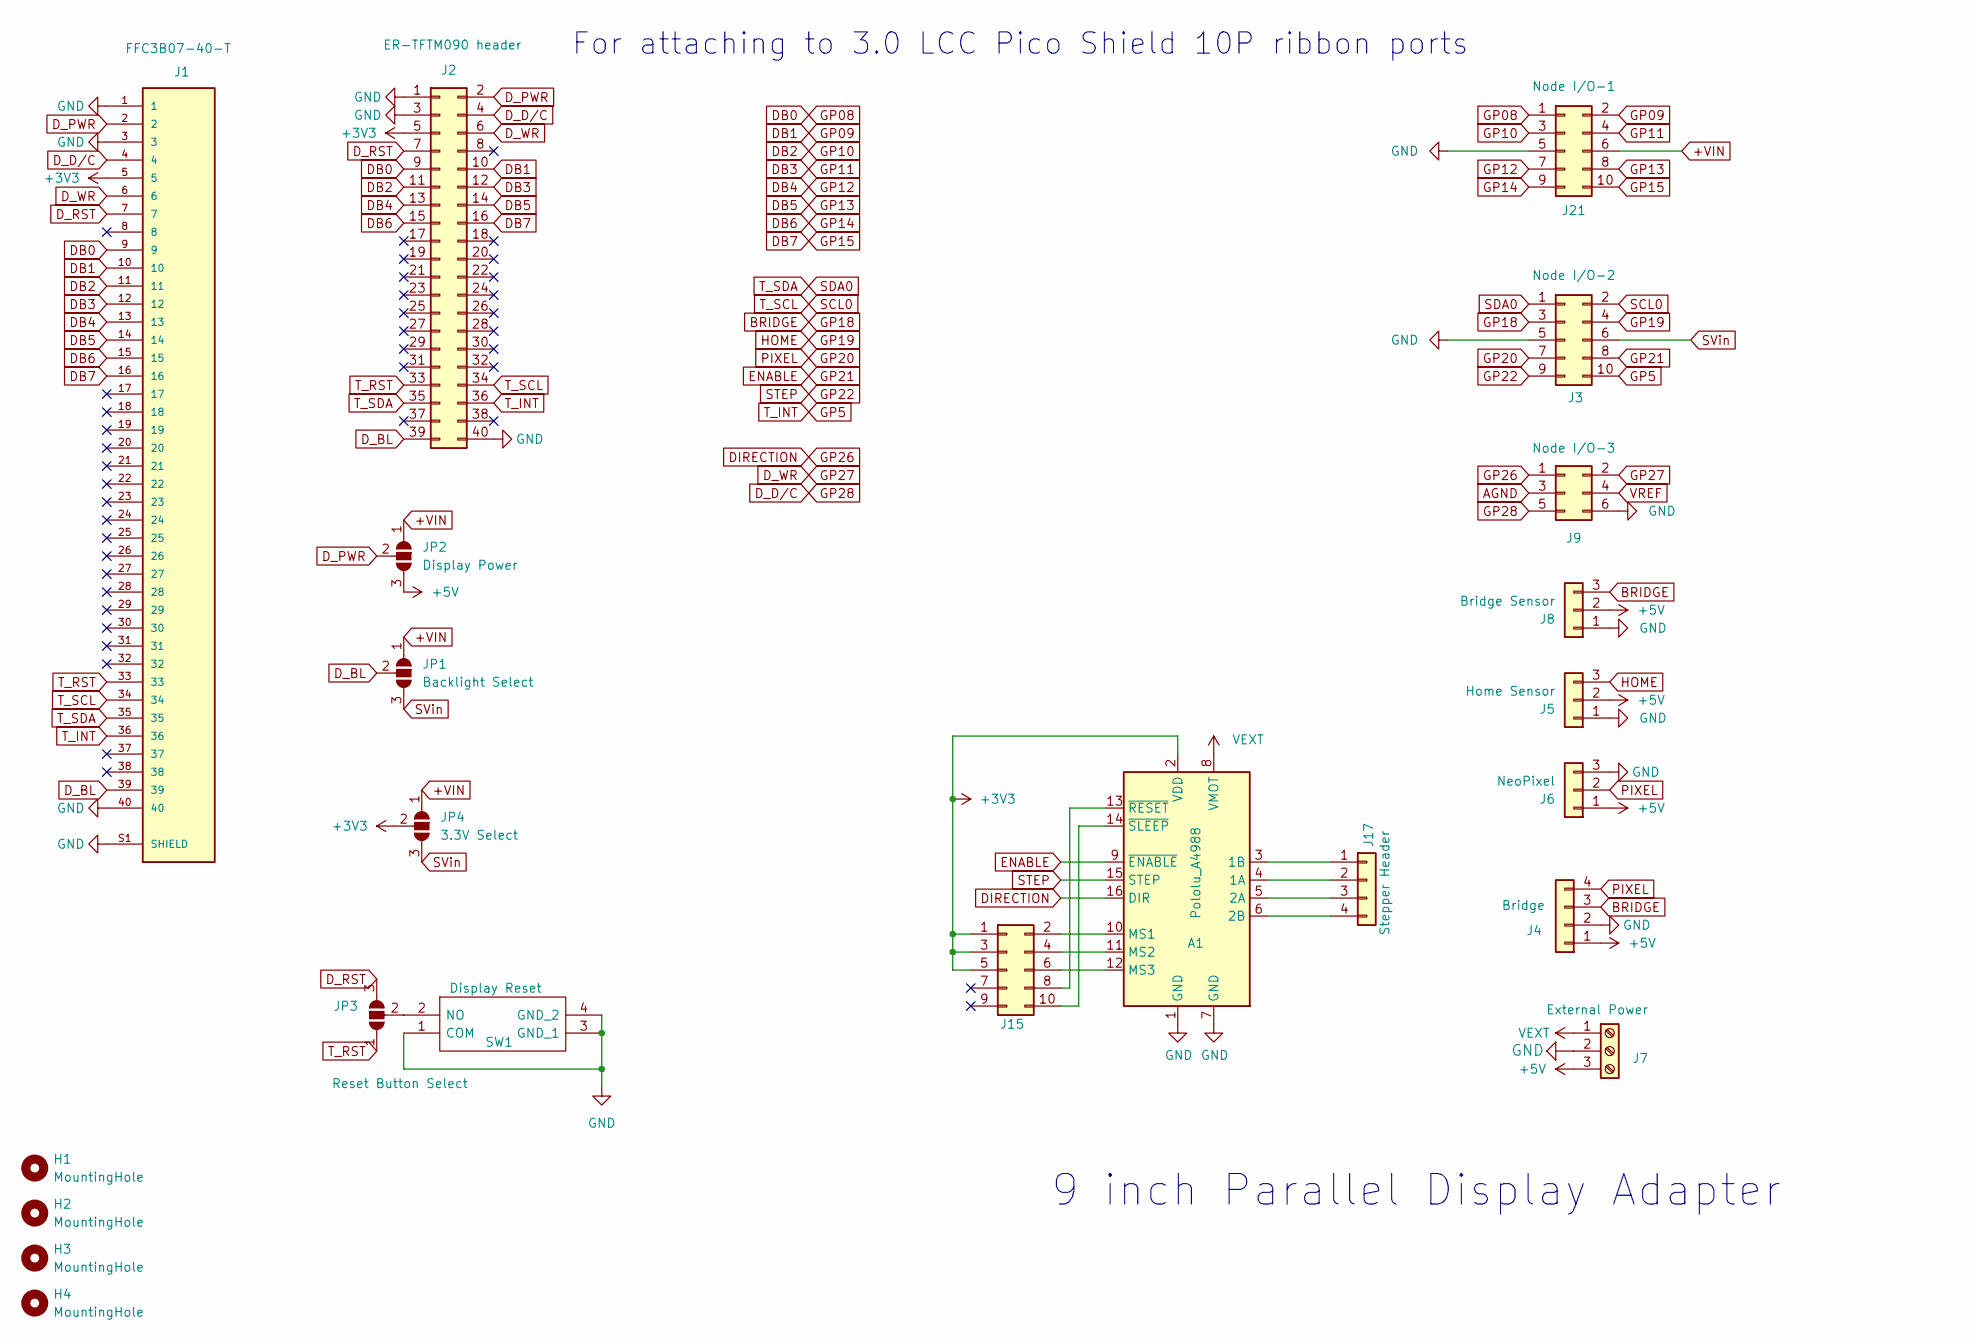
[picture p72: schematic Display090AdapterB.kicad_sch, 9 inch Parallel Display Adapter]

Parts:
A1: Pololu_A4988; Pololu_Breakout-16_15.2x20.3mm
H1, H2, H3, H4: MountingHole; MountingHole_3.5mm
J1: FFC3B07-40-T; GCT_FFC3B07-40-T; PARTREV A
J2: ER-TFTM090 header; PinSocket_2x20_P2.54mm_Vertical
J3: Node I/O-2; IDC-Header_2x05_P2.54mm_Vertical
J4: Bridge; PinHeader_1x04_P2.54mm_Vertical
J5: Home Sensor; JST_EH_B3B-EH-A_1x03_P2.50mm_Vertical
J6: NeoPixel; JST_EH_B3B-EH-A_1x03_P2.50mm_Vertical
J7: External Power; JST_EH_B3B-EH-A_1x03_P2.50mm_Vertical
J8: Bridge Sensor; JST_EH_B3B-EH-A_1x03_P2.50mm_Vertical
J9: Node I/O-3; IDC-Header_2x03_P2.54mm_Vertical
J15: Conn_02x05_Odd_Even; PinHeader_2x05_P2.54mm_Vertical
J17: Stepper Header; PinSocket_1x04_P2.54mm_Vertical
J21: Node I/O-1; IDC-Header_2x05_P2.54mm_Vertical
JP1: Backlight Select; SolderJumper-3_P1.3mm_Open_Pad1.0x1.5mm_NumberLabels
JP2: Display Power; SolderJumper-3_P1.3mm_Open_Pad1.0x1.5mm_NumberLabels
JP3: Reset Button Select; SolderJumper-3_P1.3mm_Open_Pad1.0x1.5mm_NumberLabels
JP4: 3.3V Select; SolderJumper-3_P1.3mm_Open_Pad1.0x1.5mm_NumberLabels
SW1: Display Reset; TS1167443BK160RAD; Mouser Part Number 179-TS1167443160RAD

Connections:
+3V3: A1.2 (VDD), J1.5, J2.5, J15.1, J15.3, J15.5, JP4.2 (C)
+5V: J4.1, J5.2, J6.1, J7.3, J8.2, JP2.3 (B)
+VIN: J21.6, JP1.1 (A), JP2.1 (A), JP4.1 (A)
AGND: J9.3
BRIDGE: J3.3, J4.3, J8.3
DB0: J1.9, J2.9, J21.1
DB1: J1.10, J2.10, J21.2
DB2: J1.11, J2.11, J21.3
DB3: J1.12, J2.12, J21.4
DB4: J1.13, J2.13, J21.7
DB5: J1.14, J2.14, J21.8
DB6: J1.15, J2.15, J21.9
DB7: J1.16, J2.16, J21.10
DIRECTION: A1.16 (DIR), J9.1
D_BL: J1.39, J2.39, JP1.2 (C)
D_D/C: J1.4, J2.4, J9.5
D_PWR: J1.2, J2.2, JP2.2 (C)
D_RST: J1.7, J2.7, JP3.3 (B)
D_WR: J1.6, J2.6, J9.2
ENABLE: A1.9 (~ENABLE), J3.8
GND: A1.1 (GND), A1.7 (GND), J1.1, J1.3, J1.40, J1.S1 (SHIELD), J1.S2 (SHIELD), J2.1, J2.3, J2.40, J3.5, J4.2, J5.1, J6.3, J7.2, J8.1, J9.6, J21.5, SW1.1 (COM), SW1.3 (GND_1), SW1.4 (GND_2)
GP5: J1.36, J2.36, J3.10
GP19: J3.4, J5.3
GP20: J3.7, J4.4, J6.2
GP22: A1.15 (STEP), J3.9
unnamed: A1.4 (1A), J17.2
unnamed: A1.3 (1B), J17.1
unnamed: A1.5 (2A), J17.3
unnamed: A1.6 (2B), J17.4
unnamed: A1.10 (MS1), J15.2
unnamed: A1.11 (MS2), J15.4
unnamed: A1.12 (MS3), J15.6
unnamed: A1.13 (~RESET), J15.8
unnamed: A1.14 (~SLEEP), J15.10
unnamed: JP3.2 (C), SW1.2 (NO)
SCL0: J1.34, J2.34, J3.2
SDA0: J1.35, J2.35, J3.1
SVin: J3.6, JP1.3 (B), JP4.3 (B)
T_RST: J1.33, J2.33, JP3.1 (A)
VEXT: A1.8 (VMOT), J7.1
VREF: J9.4

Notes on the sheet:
9 inch Parallel Display Adapter
For attaching to 3.0 LCC Pico Shield 10P ribbon ports

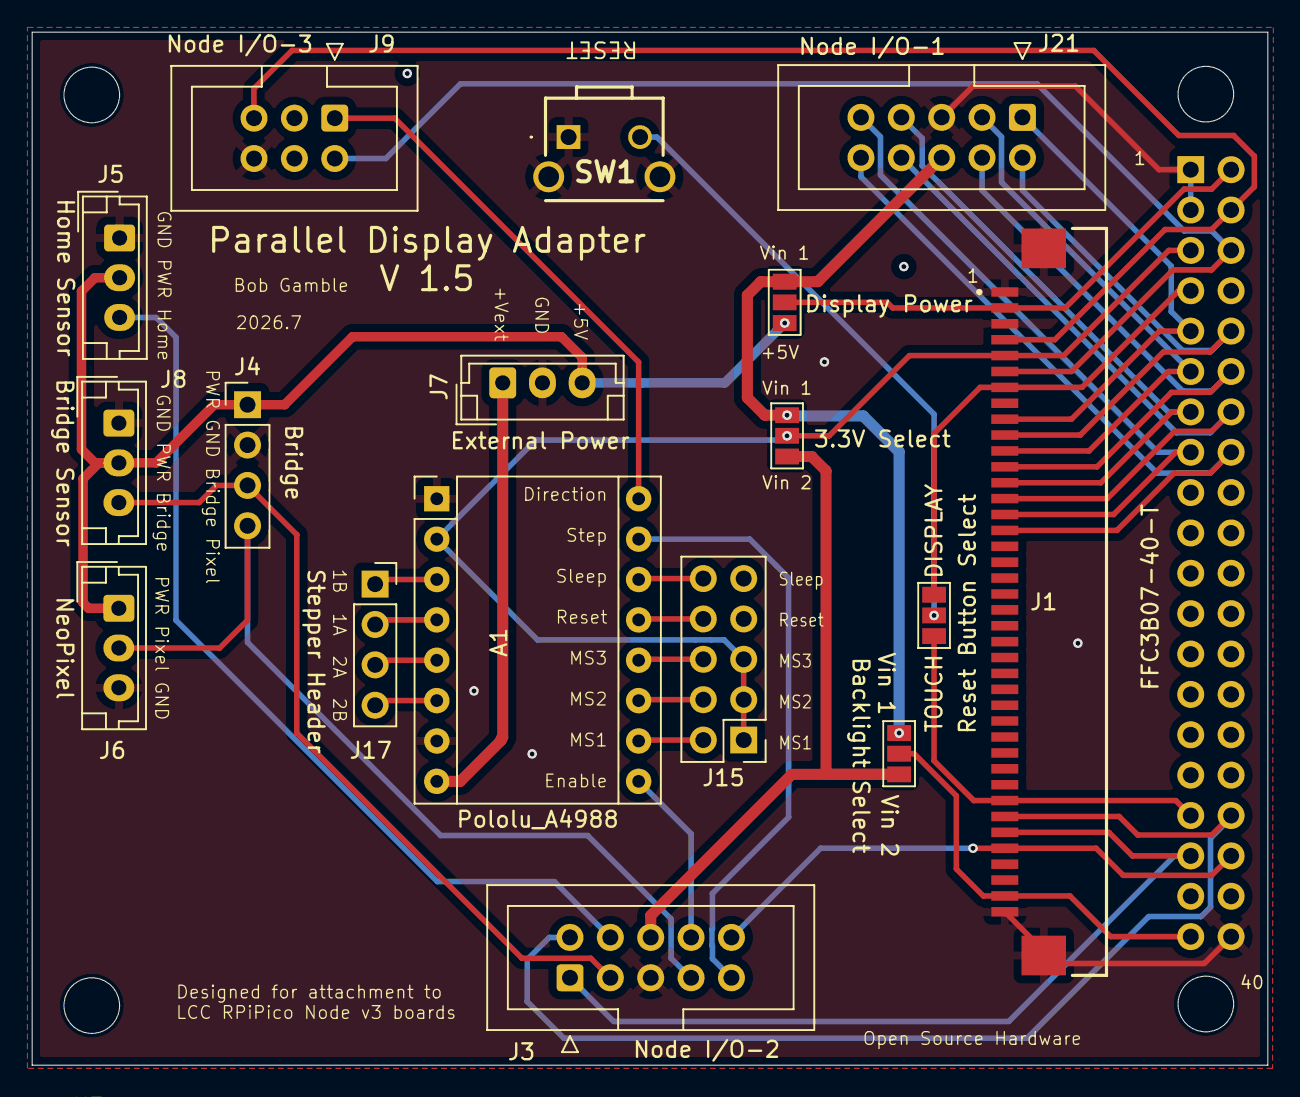
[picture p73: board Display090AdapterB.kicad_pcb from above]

Board: 2 copper layers, 77.8 x 65.0 mm, 22 parts (1 on the bottom side), 39 nets.

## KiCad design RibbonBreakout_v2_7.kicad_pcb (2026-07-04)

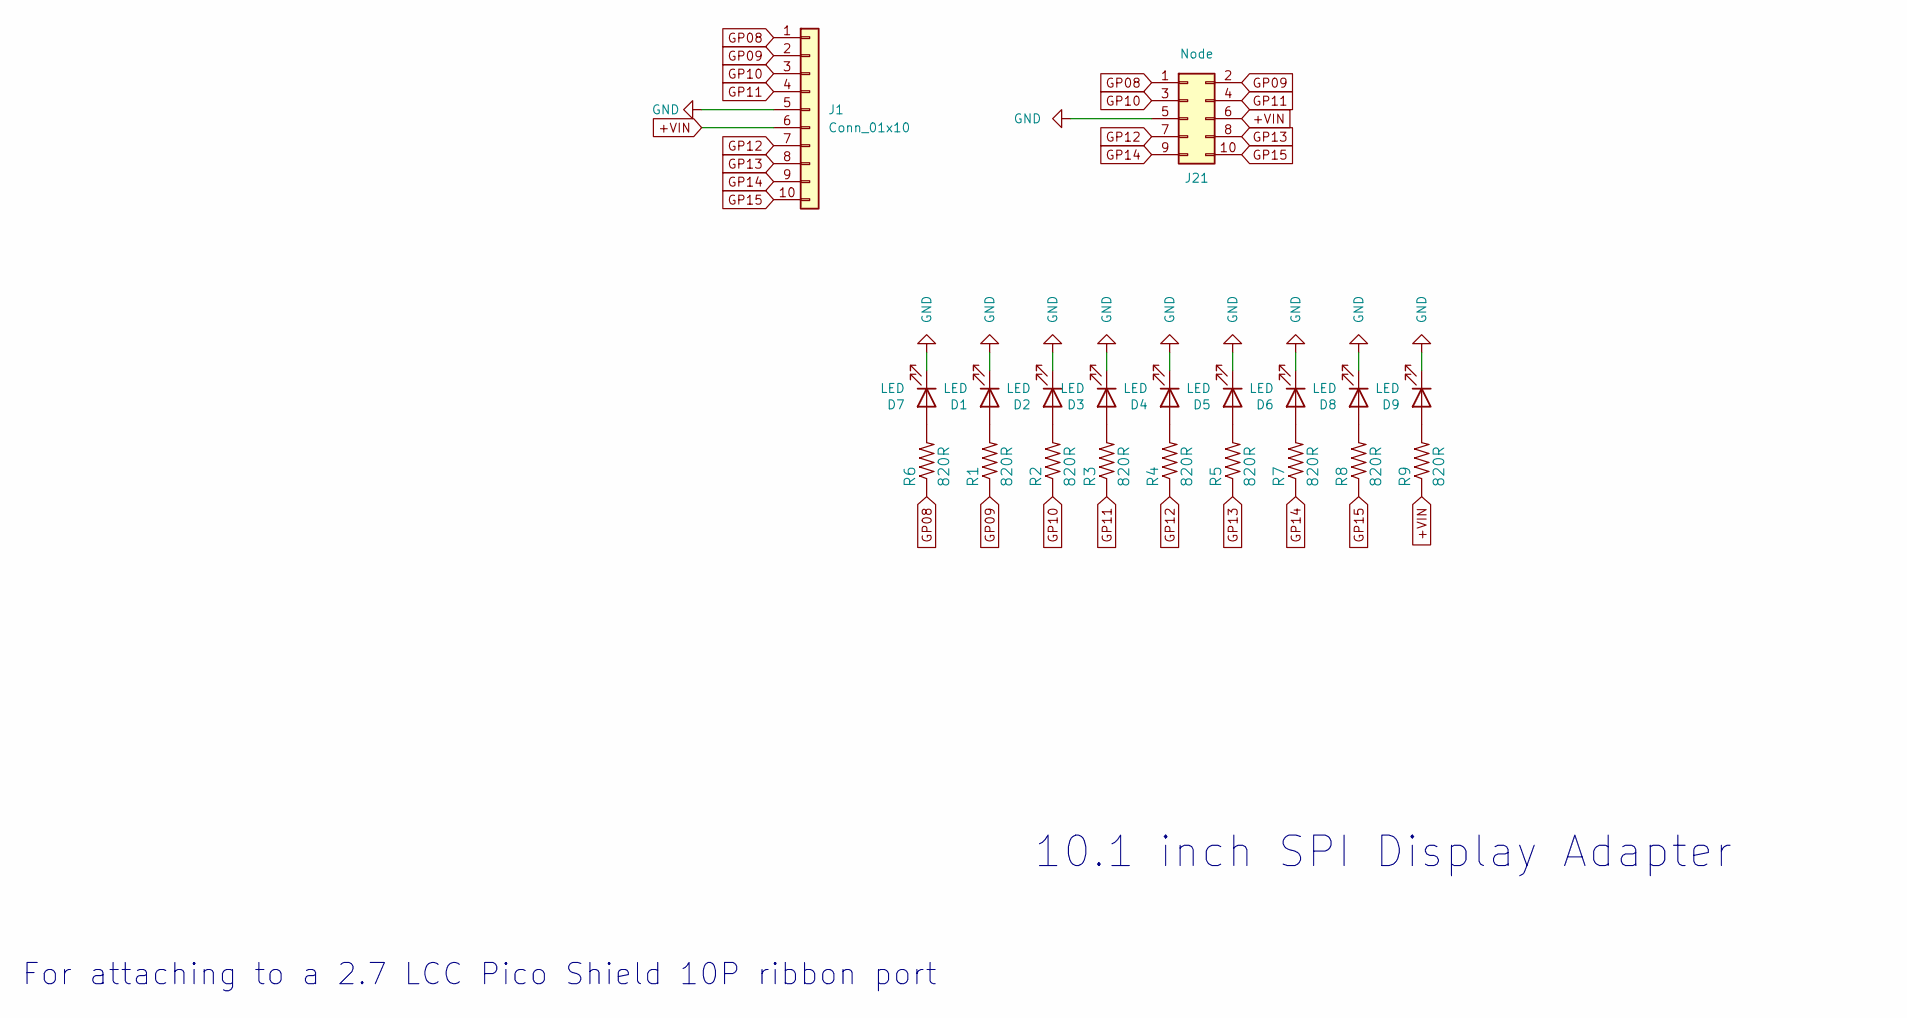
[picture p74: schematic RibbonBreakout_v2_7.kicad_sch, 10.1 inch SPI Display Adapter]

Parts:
D1, D2, D3, D4, D5, D6, D7, D8, D9: LED; LED_1206_3216Metric_Pad1.42x1.75mm_HandSolder
J1: Conn_01x10; PinHeader_1x10_P2.54mm_Vertical
J21: Node; IDC-Header_2x05_P2.54mm_Vertical
R1, R2, R3, R4, R5, R6, R7, R8, R9: 820R; R_1206_3216Metric_Pad1.30x1.75mm_HandSolder

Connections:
+VIN: J1.6, J21.6, R9.1
GND: D1.1 (K), D2.1 (K), D3.1 (K), D4.1 (K), D5.1 (K), D6.1 (K), D7.1 (K), D8.1 (K), D9.1 (K), J1.5, J21.5
GP08: J1.1, J21.1, R6.1
GP09: J1.2, J21.2, R1.1
GP10: J1.3, J21.3, R2.1
GP11: J1.4, J21.4, R3.1
GP12: J1.7, J21.7, R4.1
GP13: J1.8, J21.8, R5.1
GP14: J1.9, J21.9, R7.1
GP15: J1.10, J21.10, R8.1
unnamed: D1.2 (A), R1.2
unnamed: D2.2 (A), R2.2
unnamed: D3.2 (A), R3.2
unnamed: D4.2 (A), R4.2
unnamed: D5.2 (A), R5.2
unnamed: D6.2 (A), R7.2
unnamed: D7.2 (A), R6.2
unnamed: D8.2 (A), R8.2
unnamed: D9.2 (A), R9.2

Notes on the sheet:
10.1 inch SPI Display Adapter
For attaching to a 2.7 LCC Pico Shield 10P ribbon port

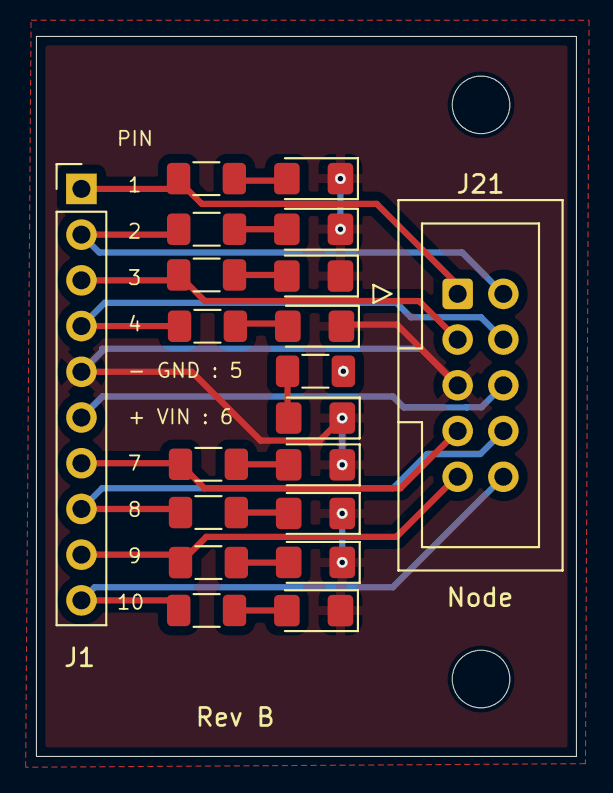
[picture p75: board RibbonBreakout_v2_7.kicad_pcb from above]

Board: 2 copper layers, 30.0 x 40.0 mm, 20 parts (0 on the bottom side), 19 nets.

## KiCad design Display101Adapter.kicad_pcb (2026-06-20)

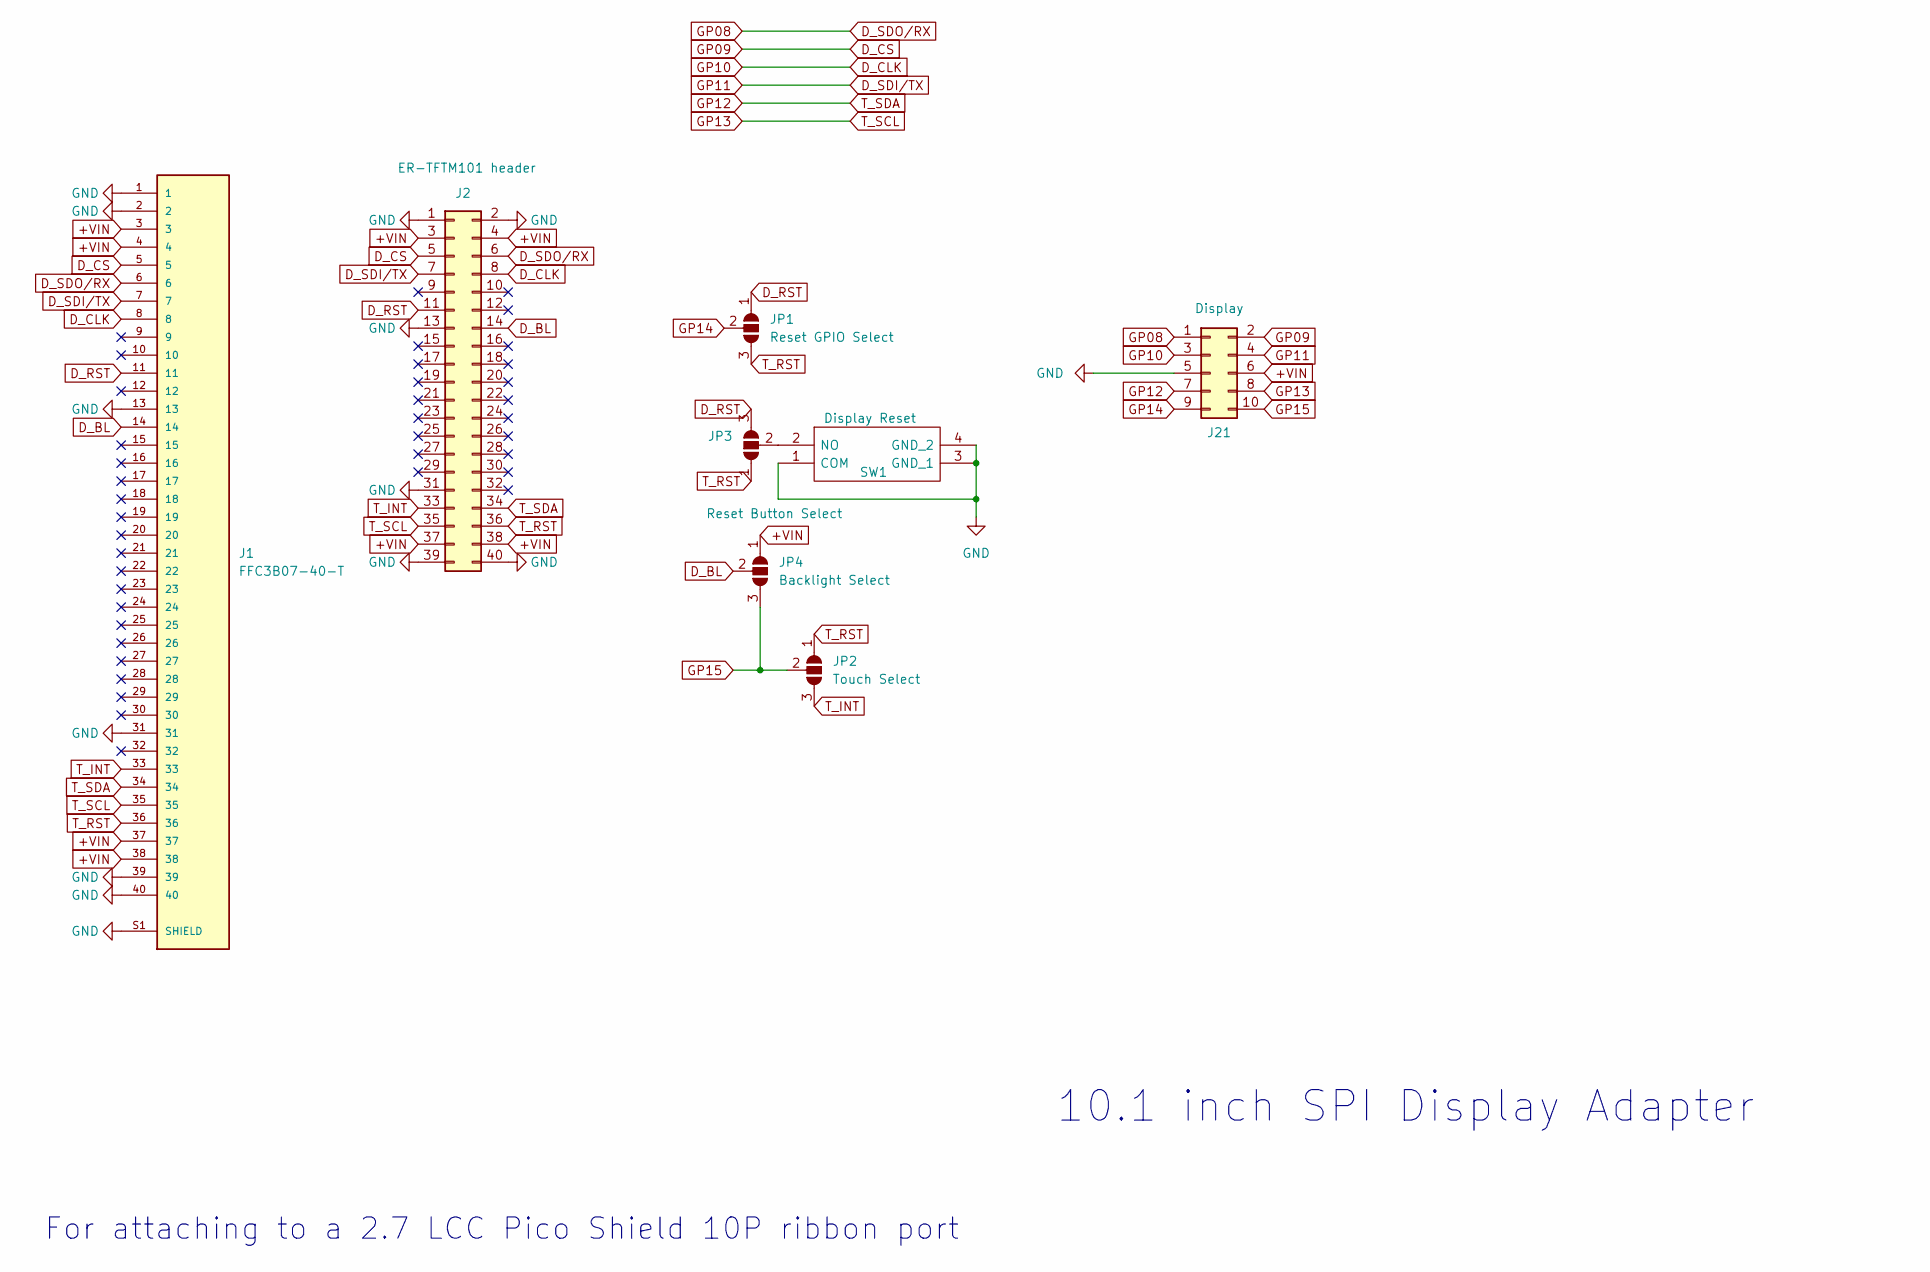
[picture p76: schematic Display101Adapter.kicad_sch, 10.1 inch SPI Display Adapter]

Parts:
J1: FFC3B07-40-T; GCT_FFC3B07-40-T; PARTREV A
J2: ER-TFTM101 header; PinSocket_2x20_P2.54mm_Vertical
J21: Display; IDC-Header_2x05_P2.54mm_Vertical
JP1: Reset GPIO Select; SolderJumper-3_P1.3mm_Open_Pad1.0x1.5mm_NumberLabels
JP2: Touch Select; SolderJumper-3_P1.3mm_Open_Pad1.0x1.5mm_NumberLabels
JP3: Reset Button Select; SolderJumper-3_P1.3mm_Open_Pad1.0x1.5mm_NumberLabels
JP4: Backlight Select; SolderJumper-3_P1.3mm_Open_Pad1.0x1.5mm_NumberLabels
SW1: Display Reset; TS1167443BK160RAD; Mouser Part Number 179-TS1167443160RAD

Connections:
+VIN: J1.3, J1.4, J1.37, J1.38, J2.3, J2.4, J2.37, J2.38, J21.6, JP4.1 (A)
D_BL: J1.14, J2.14, JP4.2 (C)
D_CLK: J1.8, J2.8, J21.3
D_CS: J1.5, J2.5, J21.2
D_RST: J1.11, J2.11, JP1.1 (A), JP3.3 (B)
D_SDI/TX: J1.7, J2.7, J21.4
D_SDO/RX: J1.6, J2.6, J21.1
GND: J1.1, J1.2, J1.13, J1.31, J1.39, J1.40, J1.S1 (SHIELD), J1.S2 (SHIELD), J2.1, J2.2, J2.13, J2.31, J2.39, J2.40, J21.5, SW1.1 (COM), SW1.3 (GND_1), SW1.4 (GND_2)
GP12: J1.34, J2.34, J21.7
GP13: J1.35, J2.35, J21.8
GP14: J21.9, JP1.2 (C)
GP15: J21.10, JP2.2 (C), JP4.3 (B)
unnamed: JP3.2 (C), SW1.2 (NO)
T_INT: J1.33, J2.33, JP2.3 (B)
T_RST: J1.36, J2.36, JP1.3 (B), JP2.1 (A), JP3.1 (A)

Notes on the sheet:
10.1 inch SPI Display Adapter
For attaching to a 2.7 LCC Pico Shield 10P ribbon port

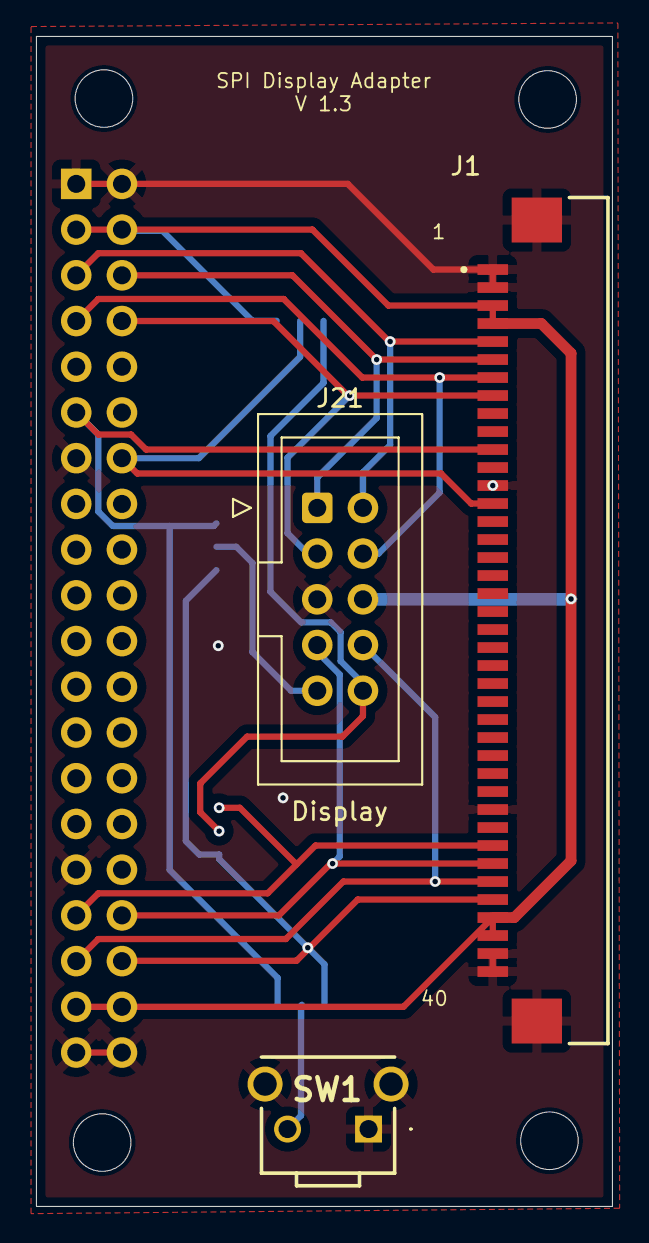
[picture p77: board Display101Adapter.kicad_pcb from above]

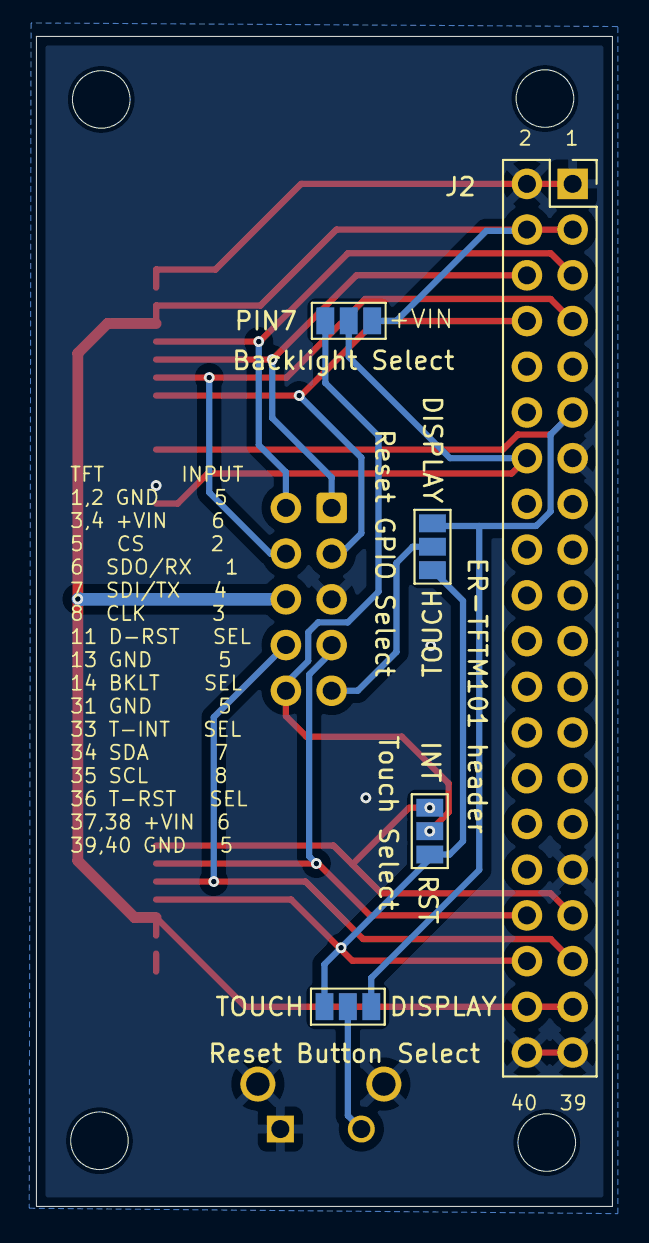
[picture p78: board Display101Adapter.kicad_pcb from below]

Board: 2 copper layers, 32.0 x 65.0 mm, 8 parts (5 on the bottom side), 15 nets.

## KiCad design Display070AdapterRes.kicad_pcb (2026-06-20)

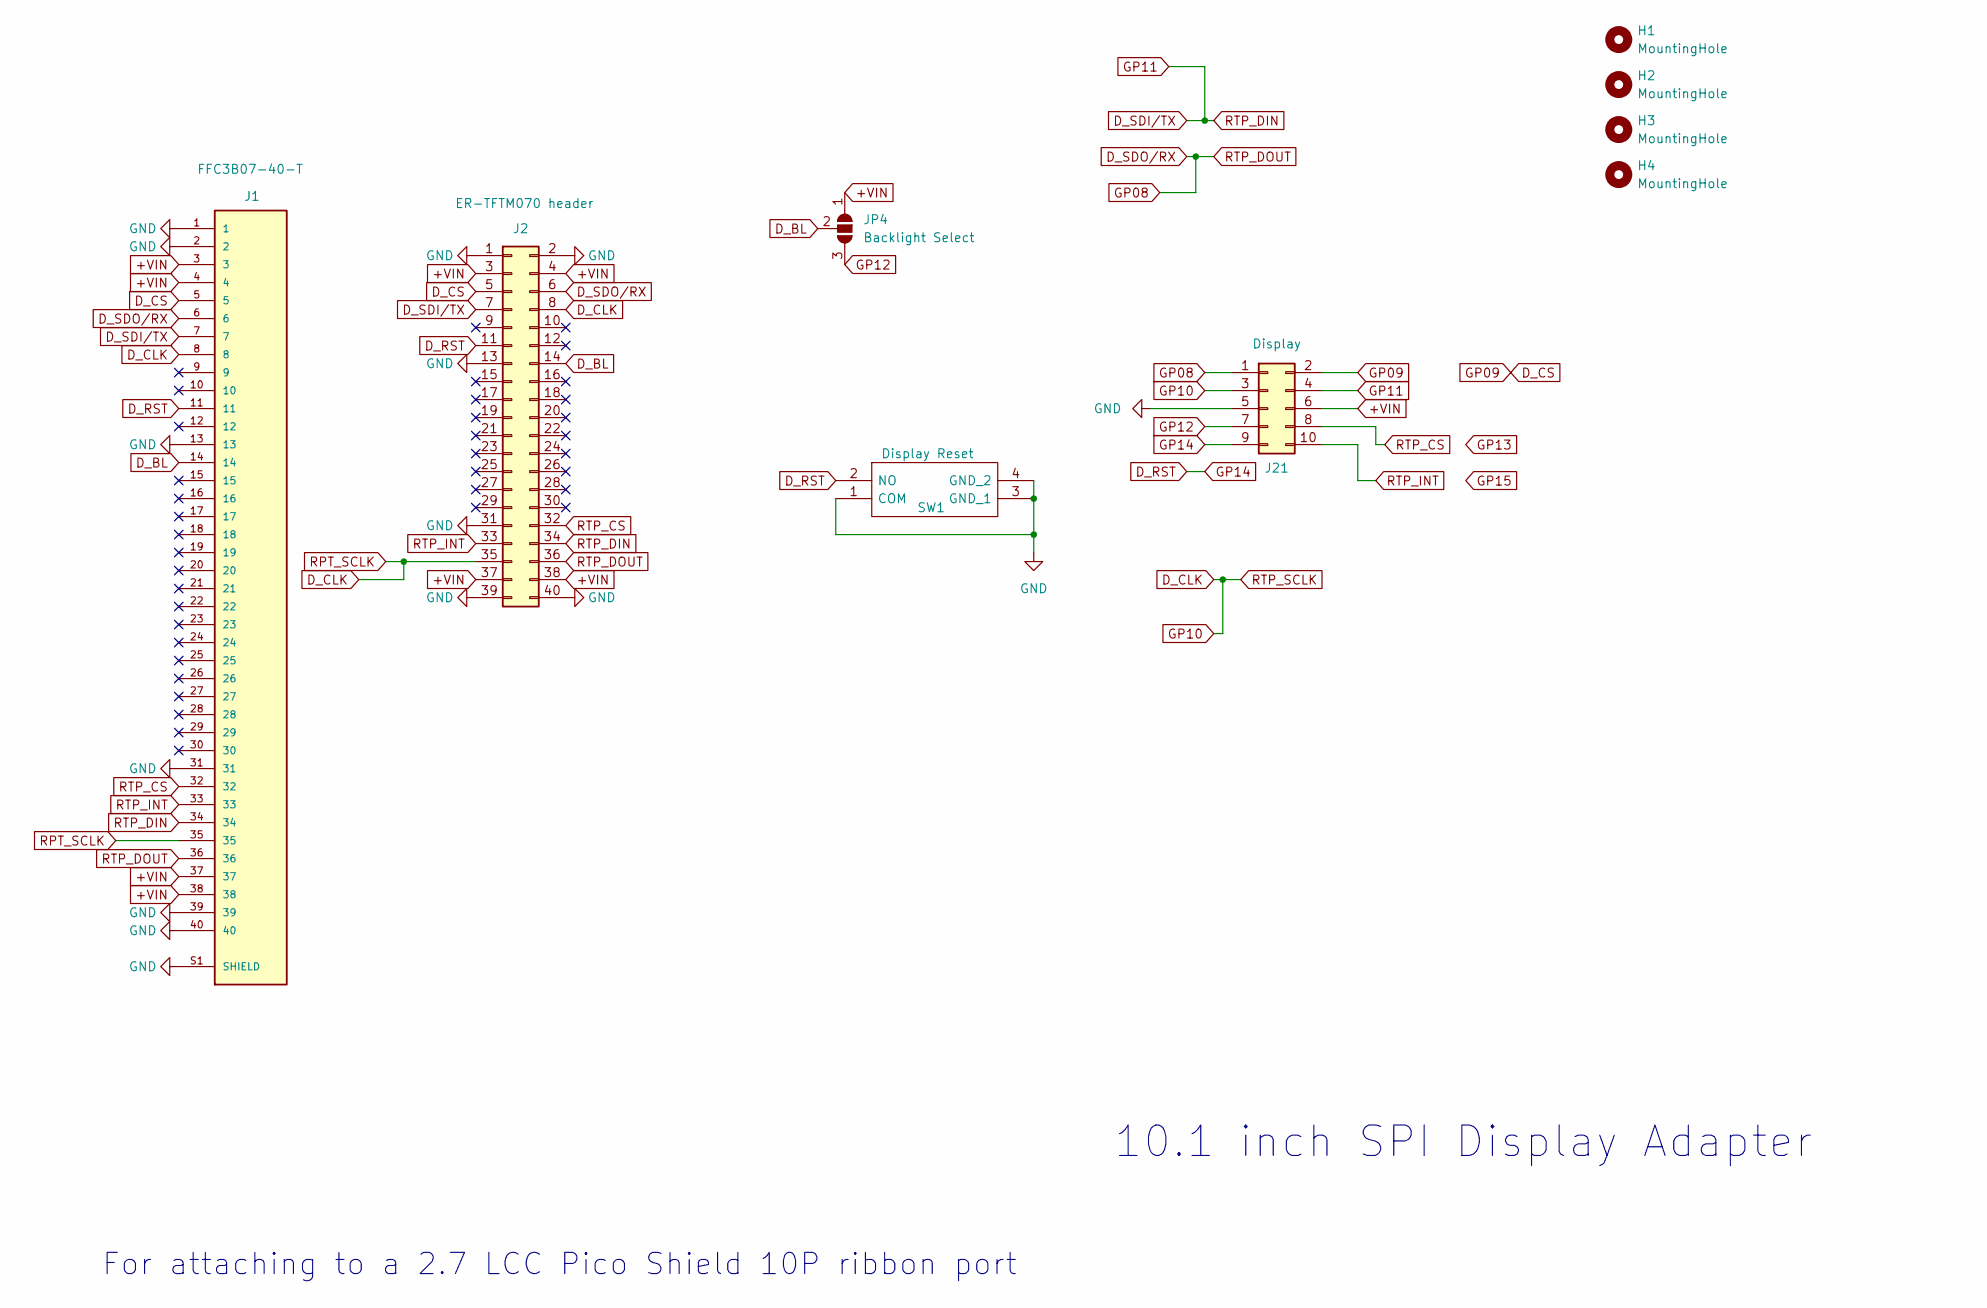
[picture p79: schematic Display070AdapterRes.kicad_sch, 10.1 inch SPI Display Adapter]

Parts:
H1, H2, H3, H4: MountingHole; MountingHole_3.5mm
J1: FFC3B07-40-T; GCT_FFC3B07-40-T; PARTREV A
J2: ER-TFTM070 header; PinSocket_2x20_P2.54mm_Vertical
J21: Display; IDC-Header_2x05_P2.54mm_Vertical
JP4: Backlight Select; SolderJumper-3_P1.3mm_Open_Pad1.0x1.5mm_NumberLabels
SW1: Display Reset; TS1167443BK160RAD; Mouser Part Number 179-TS1167443160RAD

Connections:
+VIN: J1.3, J1.4, J1.37, J1.38, J2.3, J2.4, J2.37, J2.38, J21.6, JP4.1 (A)
D_BL: J1.14, J2.14, JP4.2 (C)
D_CLK: J1.8, J1.35, J2.8, J2.35, J21.3
D_CS: J1.5, J2.5, J21.2
D_RST: J1.11, J2.11, J21.9, SW1.2 (NO)
D_SDI/TX: J1.7, J1.34, J2.7, J2.34, J21.4
D_SDO/RX: J1.6, J1.36, J2.6, J2.36, J21.1
GND: J1.1, J1.2, J1.13, J1.31, J1.39, J1.40, J1.S1 (SHIELD), J1.S2 (SHIELD), J2.1, J2.2, J2.13, J2.31, J2.39, J2.40, J21.5, SW1.1 (COM), SW1.3 (GND_1), SW1.4 (GND_2)
GP12: J21.7, JP4.3 (B)
RTP_CS: J1.32, J2.32, J21.8
RTP_INT: J1.33, J2.33, J21.10

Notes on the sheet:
10.1 inch SPI Display Adapter
For attaching to a 2.7 LCC Pico Shield 10P ribbon port

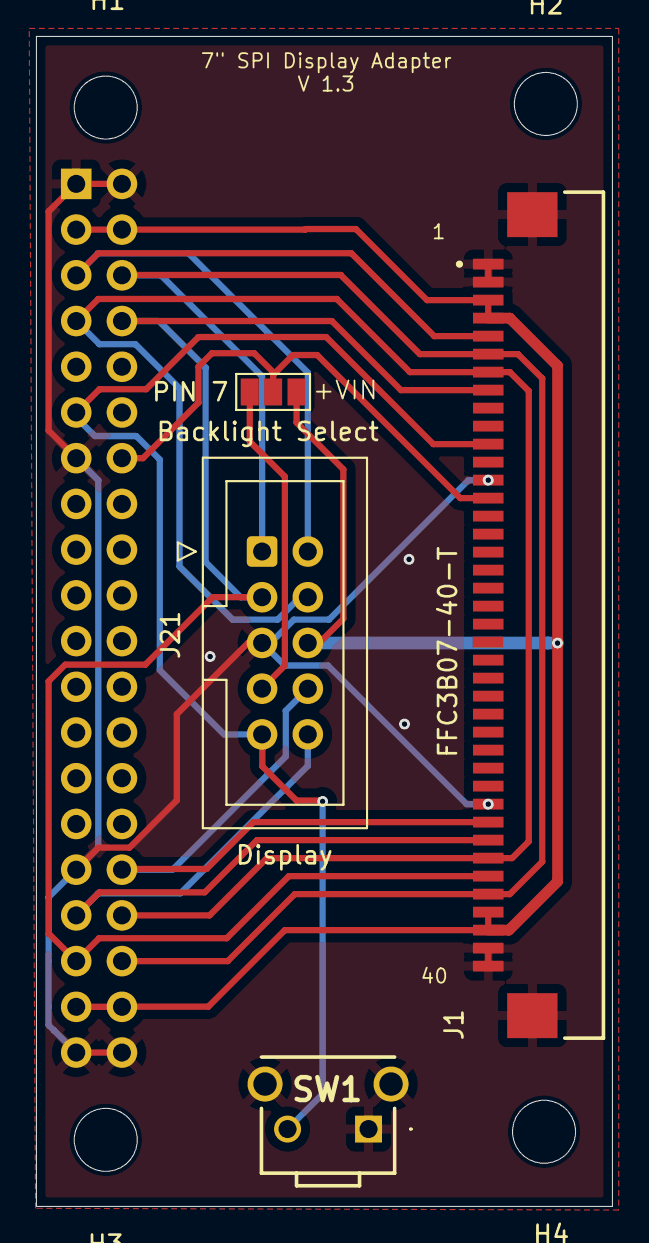
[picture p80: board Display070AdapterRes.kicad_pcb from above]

Board: 2 copper layers, 32.0 x 65.0 mm, 9 parts (1 on the bottom side), 11 nets.

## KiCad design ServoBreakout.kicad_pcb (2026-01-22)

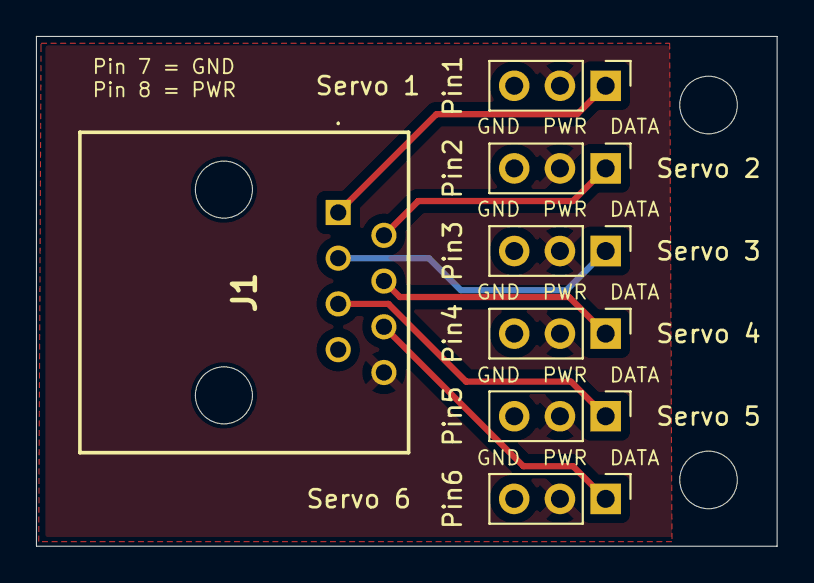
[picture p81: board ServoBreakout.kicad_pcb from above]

Board: 2 copper layers, 41.1 x 28.3 mm, 7 parts (0 on the bottom side), 8 nets.

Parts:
J1: RJ45; MTJ880X1
Pin1: Servo 1; PinHeader_1x03_P2.54mm_Vertical
Pin2: Servo 2; PinHeader_1x03_P2.54mm_Vertical
Pin3: Servo 3; PinHeader_1x03_P2.54mm_Vertical
Pin4: Servo 4; PinHeader_1x03_P2.54mm_Vertical
Pin5: Servo 5; PinHeader_1x03_P2.54mm_Vertical
Pin6: Servo 6; PinHeader_1x03_P2.54mm_Vertical

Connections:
+5V: J1.8, Pin1.2, Pin2.2, Pin3.2, Pin4.2, Pin5.2, Pin6.2
Data 1: J1.1, Pin1.1
Data 2: J1.2, Pin2.1
Data 3: J1.3, Pin3.1
Data 4: J1.4, Pin4.1
Data 5: J1.5, Pin5.1
Data 6: J1.6, Pin6.1
GND: J1.7, Pin1.3, Pin2.3, Pin3.3, Pin4.3, Pin5.3, Pin6.3

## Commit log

2026-01-22 Initial Load
    put the files in the right place
    [LCC-Pico-Node_v2_6-B_Mask.gbs, LCC-Pico-Node_v2_6-B_Paste.gbp, LCC-Pico-Node_v2_6-B_Silkscreen.gbo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]
2026-01-23 Added Documentation
    Added some board documentation
    [LCC-Pico-Stepper_v2_4 ABC BOM.xlsx]
2026-04-27 2026 Spring Board Updates
    updates for stepper board for SPI display and node boards and breakout boards for IDC cables
    [Display101Adapter-B_Mask.gbr, Display101Adapter-B_Paste.gbr, Display101Adapter-B_Silkscreen.gbr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]
2026-04-28 Documentation Updates
    added a bunch
    [LCC-Pico-Stepper_v2_7.xlsx, parts.xlsx, rp-pico-2-pin-planner-LCCboards.xlsx]
2026-06-20 Delete old boards
    Delete old flawed boards, v 3.0 boards are much better.
    [LCC-Pico-Node_v2_6-B_Mask.gbs, LCC-Pico-Node_v2_6-B_Paste.gbp, LCC-Pico-Node_v2_6-B_Silkscreen.gbo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]
2026-06-20 v3.0 added
    [Display070AdapterRes.kicad_pcb, Display070AdapterRes.kicad_sch, Display090Adapter.kicad_pcb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]
2026-06-23 Production level
    0805 boards can be assembled at JLCPCB with these files
    1206 boards are for hand assembly
    [BOM-LCC-Pico-LiteNode_v3B - 0805.csv, BOM-LCC-Pico-Node_v3_0C - 0805.csv, LCC-Pico-LiteNode_v3B - 0805.kicad_pcb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]
2026-06-24 Fixed a problem file
    a footprint got rotated by accident
    [LCC-Pico-Node_v3_0C - 0805.csv, LCC-Pico-Node_v3_0C - 0805.kicad_pcb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]
2026-07-04 Add Display090AdapterB & update gerbers
    Replace Display090Adapter with a new Display090AdapterB set (new .kicad_pcb/.kicad_pro and updated .kicad_prl/.kicad_sch). Update RibbonBreakout and RibbonBreakout2 board files. Remove many individual gerber output files and add consolidated GERBER-*.zip archives under gerbers/. Also remove temporary/backup documentation files. These changes package gerbers and introduce the B revision of the 090 adapter.
    [Display090Adapter.kicad_pcb, Display090Adapter.kicad_sch, Display090AdapterB.kicad_pcb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]
2026-07-07 fixed bad EEPROM footprint rotation
    had rotated EEPROM incorrectly, this fixes it
    [BOM-LCC-Pico-Node_v3_0C - 0805.csv, LCC-Pico-Node_v3_0C - 0805.kicad_pcb, LCC-Pico-Node_v3_0C - 0805.kicad_sch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]
2026-07-12 barrel jack footprint fix
    bad footprint replaced
    [BOM-LCC-Pico-Node_v3_0D - 0805.csv, LCC-Pico-Node_v3_0C - 1206.kicad_pcb, LCC-Pico-Node_v3_0C - 1206.kicad_sch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]
2026-07-12 Screen print cleanup
    minor updates and formatting of screen print content
    [LCC-Pico-Node_v3_0D - 1206.kicad_pcb]
2026-07-18 Create LCC Pico Node V3_0 User Guide.pdf
